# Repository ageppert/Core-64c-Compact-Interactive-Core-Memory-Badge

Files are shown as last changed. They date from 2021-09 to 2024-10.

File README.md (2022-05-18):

# Core-64c-Compact-Interactive-Core-Memory-Badge
Weave your own 64 bits of core memory over the top of LEDs to interact with directly using a magnetic wand.

Purchase: https://www.Core64.io

Follow this project at: https://hackaday.io/project/166155-core-64-interactive-core-memory-badge

You are in the hardware development repository. Production version firmware is at https://github.com/ageppert/Core64/

# Hardware Version History (latest on top)

HWV 0.3.0 Correct shift register schematic, add TC0_MON as ADC3, move 5V0 cap down, alternate LDO v-regs with 0.1uF caps, rotate SPI GPIO 180°, matrix current setting resistors 6.8 Ohm, I2C pull-ups 1.2K, add battery pack wire pads directly to board, silkscreen tweaks, move LED Matrix Driver components away from lanyard hole.

HWV 0.2.1 Rework HWV 0.2.0 to correct shift register schematics mistakes.

HWV 0.2.0 Change to 74HC595 shift registers for IO expansion. First version prototyped. Matrix current setting resistors 5.1 Ohm.

HWV 0.1.0 Compact Triple Stack - use 74HC138/238 3-to-8 decoders for IO expansion. Abandoned before prototyping.

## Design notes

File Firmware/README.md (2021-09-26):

# Firmware Source Code
Arduino project folder, sketches, libraries.

This firmware is for TESTING ONLY in development of Core64c.

Functional firmware is in https://github.com/ageppert/Core64/tree/master/Firmware

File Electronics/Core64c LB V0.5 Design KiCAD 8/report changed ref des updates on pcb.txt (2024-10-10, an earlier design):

Info: Processing symbol 'C1:Capacitor_SMD:C_0805_2012Metric'.
Info: Processing symbol 'X9:Connector_JST:JST_SH_SM04B-SRSS-TB_1x04-1MP_P1.00mm_Horizontal'.
Info: Processing symbol 'C2:Capacitor_SMD:C_0805_2012Metric'.
Info: Processing symbol 'X7:Connector_PinSocket_2.54mm:PinSocket_1x08_P2.54mm_Vertical'.
Info: Processing symbol 'C3:Capacitor_SMD:C_0805_2012Metric'.
Info: Processing symbol 'X6:Connector_PinSocket_2.54mm:PinSocket_1x11_P2.54mm_Vertical'.
Info: Processing symbol 'C4:Capacitor_SMD:C_0805_2012Metric'.
Info: Processing symbol 'X4:Connector_PinSocket_2.54mm:PinSocket_1x04_P2.54mm_Vertical'.
Info: Processing symbol 'C5:Capacitor_SMD:C_0805_2012Metric'.
Info: Processing symbol 'X2:Connector_PinSocket_2.54mm:PinSocket_1x04_P2.54mm_Vertical'.
Info: Processing symbol 'C6:Capacitor_SMD:C_0805_2012Metric'.
Info: Processing symbol 'U10:Package_SO:SOIC-14_3.9x8.7mm_P1.27mm'.
Info: Processing symbol 'C7:Capacitor_SMD:C_1206_3216Metric'.
Info: Processing symbol 'U9:digikey-footprints:SOIC-8_W3.9mm'.
Info: Processing symbol 'C8:Capacitor_SMD:C_1206_3216Metric'.
Info: Processing symbol 'U8:Package_TO_SOT_SMD:SOT-23-5'.
Info: Processing symbol 'C9:Capacitor_SMD:C_1206_3216Metric'.
Info: Processing symbol 'U7:Package_TO_SOT_SMD:SOT-23-5'.
Info: Processing symbol 'C10:Capacitor_SMD:C_0805_2012Metric'.
Info: Processing symbol 'U6:Package_TO_SOT_SMD:SOT-223-5'.
Info: Processing symbol 'C11:Capacitor_SMD:C_0805_2012Metric'.
Info: Processing symbol 'U5:digikey-footprints:SOIC-16_W3.90mm'.
Info: Processing symbol 'U4:digikey-footprints:SOIC-16_W3.90mm'.
Info: Processing symbol 'U3:digikey-footprints:SOIC-16_W3.90mm'.
Info: Processing symbol 'C12:Capacitor_SMD:C_0805_2012Metric'.
Info: Processing symbol 'U2:Package_SO:SOIC-8_3.9x4.9mm_P1.27mm'.
Info: Processing symbol 'C13:Capacitor_SMD:C_1206_3216Metric'.
Info: Processing symbol 'U1:PICO:Pico_W_SC0915'.
Info: Processing symbol 'C14:Capacitor_SMD:C_1206_3216Metric'.
Info: Processing symbol 'SW1:Switch_XKB_SK12D07VG4_SK12D07L4B:SK12D07VG4'.
Info: Processing symbol 'C15:Capacitor_SMD:C_1206_3216Metric'.
Info: Processing symbol 'R55:Resistor_SMD:R_0805_2012Metric'.
Info: Processing symbol 'C16:Capacitor_SMD:C_0805_2012Metric'.
Info: Processing symbol 'R54:Resistor_SMD:R_0805_2012Metric'.
Info: Processing symbol 'C17:Capacitor_SMD:C_0805_2012Metric'.
Info: Processing symbol 'R53:Resistor_SMD:R_0805_2012Metric'.
Info: Processing symbol 'C18:Capacitor_SMD:C_0805_2012Metric'.
Info: Processing symbol 'R52:Resistor_SMD:R_0805_2012Metric'.
Info: Processing symbol 'C19:Capacitor_SMD:C_0805_2012Metric'.
Info: Processing symbol 'R51:Resistor_SMD:R_0805_2012Metric'.
Info: Processing symbol 'D1:Package_TO_SOT_SMD:SOT-323_SC-70'.
Info: Processing symbol 'D2:Package_TO_SOT_SMD:SOT-323_SC-70'.
Info: Processing symbol 'D3:Package_TO_SOT_SMD:SOT-323_SC-70'.
Info: Processing symbol 'D4:Package_TO_SOT_SMD:SOT-323_SC-70'.
Info: Processing symbol 'D5:Package_TO_SOT_SMD:SOT-323_SC-70'.
Info: Processing symbol 'D6:Package_TO_SOT_SMD:SOT-323_SC-70'.
Info: Processing symbol 'D7:Package_TO_SOT_SMD:SOT-323_SC-70'.
Info: Processing symbol 'D8:Package_TO_SOT_SMD:SOT-323_SC-70'.
Info: Processing symbol 'D9:Package_TO_SOT_SMD:SOT-323_SC-70'.
Info: Processing symbol 'D10:Package_TO_SOT_SMD:SOT-323_SC-70'.
Info: Processing symbol 'D11:Package_TO_SOT_SMD:SOT-323_SC-70'.
Info: Processing symbol 'D12:Package_TO_SOT_SMD:SOT-323_SC-70'.
Info: Processing symbol 'H1:MountingHole:MountingHole_3.2mm_M3_Pad_Via'.
Info: Processing symbol 'H2:MountingHole:MountingHole_3.2mm_M3_Pad_Via'.
Info: Processing symbol 'J1:Connector_PinSocket_2.54mm:PinSocket_1x20_P2.54mm_Vertical'.
Info: Processing symbol 'J2:Connector_PinSocket_2.54mm:PinSocket_1x20_P2.54mm_Vertical'.
Info: Processing symbol 'R50:Resistor_SMD:R_0805_2012Metric'.
Info: Processing symbol 'R49:Resistor_SMD:R_0805_2012Metric'.
Info: Processing symbol 'J3:Connector_PinSocket_2.54mm:PinSocket_1x02_P2.54mm_Vertical'.
Info: Processing symbol 'J6:Connector_PinSocket_2.54mm:PinSocket_1x08_P2.54mm_Vertical'.
Info: Processing symbol 'J12:Connector_PinSocket_2.54mm:PinSocket_1x08_P2.54mm_Vertical'.
Info: Processing symbol 'R48:Resistor_SMD:R_0805_2012Metric'.
Info: Processing symbol 'JP1:Jumper:SolderJumper-2_P1.3mm_Bridged_RoundedPad1.0x1.5mm'.
Info: Processing symbol 'R47:Resistor_SMD:R_0805_2012Metric'.
Info: Processing symbol 'R46:Resistor_SMD:R_0805_2012Metric'.
Info: Processing symbol 'R45:Resistor_SMD:R_0805_2012Metric'.
Info: Processing symbol 'R44:Resistor_SMD:R_0805_2012Metric'.
Info: Processing symbol 'R42:Resistor_SMD:R_0805_2012Metric'.
Info: Processing symbol 'R38:Resistor_SMD:R_0805_2012Metric'.
Info: Processing symbol 'R37:Resistor_SMD:R_0805_2012Metric'.
Info: Processing symbol 'R36:Resistor_SMD:R_0805_2012Metric'.
Info: Processing symbol 'R35:Resistor_SMD:R_0805_2012Metric'.
Info: Processing symbol 'R34:Resistor_SMD:R_0805_2012Metric'.
Info: Processing symbol 'R31:Resistor_SMD:R_0805_2012Metric'.
Info: Processing symbol 'JP15:Jumper:SolderJumper-3_P1.3mm_Open_Pad1.0x1.5mm_NumberLabels'.
Info: Processing symbol 'JP16:Jumper:SolderJumper-3_P1.3mm_Open_Pad1.0x1.5mm_NumberLabels'.
Info: Processing symbol 'L1:Core_64_footprints:Core64c_Logo_7mm'.
Info: Processing symbol 'L2:Core_64_footprints:Core64c_Logo_7mm'.
Info: Processing symbol 'L3:Symbol:OSHW-Logo2_7.3x6mm_SilkScreen'.
Info: Processing symbol 'Q1:digikey-footprints:SOT-23-3'.
Info: Processing symbol 'Q2:digikey-footprints:SOT-23-3'.
Info: Processing symbol 'R30:Resistor_SMD:R_0805_2012Metric'.
Info: Processing symbol 'R28:Resistor_SMD:R_0805_2012Metric'.
Info: Processing symbol 'Q3:digikey-footprints:SOT-23-3'.
Info: Processing symbol 'Q4:digikey-footprints:SOT-23-3'.
Info: Processing symbol 'R27:Resistor_SMD:R_0805_2012Metric'.
Info: Processing symbol 'Q5:digikey-footprints:SOT-23-3'.
Info: Processing symbol 'Q6:digikey-footprints:SOT-23-3'.
Info: Processing symbol 'R26:Resistor_SMD:R_0805_2012Metric'.
Info: Processing symbol 'Q7:digikey-footprints:SOT-23-3'.
Info: Processing symbol 'Q8:digikey-footprints:SOT-23-3'.
Info: Processing symbol 'R25:Resistor_SMD:R_0805_2012Metric'.
Info: Processing symbol 'Q9:digikey-footprints:SOT-23-3'.
Info: Processing symbol 'Q10:digikey-footprints:SOT-23-3'.
Info: Processing symbol 'R24:Resistor_SMD:R_0805_2012Metric'.
Info: Processing symbol 'Q11:digikey-footprints:SOT-23-3'.
Info: Processing symbol 'Q12:digikey-footprints:SOT-23-3'.
Info: Processing symbol 'R23:Resistor_SMD:R_0805_2012Metric'.
Info: Processing symbol 'Q13:digikey-footprints:SOT-23-3'.
Info: Processing symbol 'Q14:digikey-footprints:SOT-23-3'.
Info: Processing symbol 'R22:Resistor_SMD:R_0805_2012Metric'.
Info: Processing symbol 'Q15:digikey-footprints:SOT-23-3'.
Info: Processing symbol 'Q16:digikey-footprints:SOT-23-3'.
Info: Processing symbol 'R21:Resistor_SMD:R_0805_2012Metric'.
Info: Processing symbol 'Q17:digikey-footprints:SOT-23-3'.
Info: Processing symbol 'Q18:digikey-footprints:SOT-23-3'.
Info: Processing symbol 'R20:Resistor_SMD:R_0805_2012Metric'.
Info: Processing symbol 'Q19:digikey-footprints:SOT-23-3'.
Info: Processing symbol 'Q20:digikey-footprints:SOT-23-3'.
Info: Processing symbol 'R19:Resistor_SMD:R_0805_2012Metric'.
Info: Processing symbol 'Q21:digikey-footprints:SOT-23-3'.
Info: Processing symbol 'R18:Resistor_SMD:R_0805_2012Metric'.
Info: Processing symbol 'Q22:digikey-footprints:SOT-23-3'.
Info: Processing symbol 'Q23:digikey-footprints:SOT-23-3'.
Info: Processing symbol 'R1:Resistor_SMD:R_0805_2012Metric'.
Info: Processing symbol 'R2:Resistor_SMD:R_0805_2012Metric'.
Info: Processing symbol 'R3:Resistor_SMD:R_0805_2012Metric'.
Info: Processing symbol 'R4:Resistor_SMD:R_0805_2012Metric'.
Info: Processing symbol 'R5:Resistor_SMD:R_0805_2012Metric'.
Info: Processing symbol 'R6:Resistor_SMD:R_0805_2012Metric'.
Info: Processing symbol 'R7:Resistor_SMD:R_0805_2012Metric'.
Info: Processing symbol 'R8:Resistor_SMD:R_0805_2012Metric'.
Info: Processing symbol 'R9:Resistor_SMD:R_0805_2012Metric'.
Info: Processing symbol 'R10:Resistor_SMD:R_0805_2012Metric'.
Info: Processing symbol 'R11:Resistor_SMD:R_0805_2012Metric'.
Info: Processing symbol 'R12:Resistor_SMD:R_0805_2012Metric'.
Info: Processing symbol 'R13:Resistor_SMD:R_0805_2012Metric'.
Info: Processing symbol 'R14:Resistor_SMD:R_0805_2012Metric'.
Info: Processing symbol 'R15:Resistor_SMD:R_0805_2012Metric'.
Info: Processing symbol 'R16:Resistor_SMD:R_0805_2012Metric'.
Info: Processing symbol 'R17:Resistor_SMD:R_0805_2012Metric'.
Reconnected Q21 pin 3 from GNDPWR to GMEM.
Reconnected Q20 pin 2 from GNDPWR to GMEM.
Reconnected Q18 pin 2 from GNDPWR to GMEM.
Reconnected Q16 pin 2 from GNDPWR to GMEM.
Changed R51 reference designator to R21.
Reconnected Q14 pin 2 from GNDPWR to GMEM.
Reconnected Q12 pin 2 from GNDPWR to GMEM.
Reconnected Q10 pin 2 from GNDPWR to GMEM.
Reconnected Q8 pin 2 from GNDPWR to GMEM.
Reconnected Q6 pin 2 from GNDPWR to GMEM.
Reconnected Q4 pin 2 from GNDPWR to GMEM.
Changed R28 reference designator to R27.
Reconnected Q2 pin 2 from GNDPWR to GMEM.
Changed R27 reference designator to R28.
Add net GMEM.
Changed R55 reference designator to R30.
Connected JP1 pin 1 to PICO_VBUS.
Changed R56 reference designator to R31.
Connected JP1 pin 2 to 5VUSB.
Changed R48 reference designator to R34.
Removed JP1 'exclude from BOM' fabrication attribute.
Changed R47 reference designator to R35.
Updated JP1 footprint filters to 'SolderJumper*Bridged*'.
Changed R40 reference designator to R36.
Add net Net-(R36-Pad1).
Reconnected R36 pin 1 from Net-(R40-Pad1) to Net-(R36-Pad1).
Updated JP1 sheetfile to 'Core64c LB.kicad_sch'.
Changed R41 reference designator to R37.
Reconnected R37 pin 2 from Net-(R40-Pad1) to Net-(R36-Pad1).
Updated JP1 sheetname to 'Root'.
Changed R42 reference designator to R38.
Updated JP1 fields.
Changed R45 reference designator to R42.
Updated JP1 symbol association from  to /08dada08-f2dd-4b06-bc5f-624b59e1f3ee.
Changed R39 reference designator to R44.
Changed JP1 value from SolderJumper-2_P1.3mm_Bridged_RoundedPad1.0x1.5mm to VBUS_VUSB_TIE.
Changed R44 reference designator to R45.
Add net Net-(U6-EN).
Reconnected R45 pin 2 from Net-(U5-EN) to Net-(U6-EN).
Changed REF** reference designator to JP1.
Changed R38 reference designator to R46.
Add net Net-(U8-Y).
Reconnected R46 pin 2 from Net-(U3-Y) to Net-(U8-Y).
Added JP1 (footprint 'Jumper:SolderJumper-2_P1.3mm_Bridged_RoundedPad1.0x1.5mm').
Changed R29 reference designator to R47.
Reconnected J12 pin 3 from 5VUSB to PICO_VBUS.
Changed R30 reference designator to R48.
Add net Net-(U9B-_).
Reconnected R48 pin 2 from Net-(U1B-_) to Net-(U9B-_).
Reconnected J2 pin 20 from 5VUSB to PICO_VBUS.
Changed R32 reference designator to R49.
Reconnected R49 pin 1 from Net-(U1B-_) to Net-(U9B-_).
Add net PICO_VBUS.
Changed R34 reference designator to R50.
Changed C4 reference designator to C19.
Changed R31 reference designator to R51.
Add net Net-(U9A--).
Reconnected R51 pin 2 from Net-(U1A--) to Net-(U9A--).
Changed C3 reference designator to C18.
Changed R33 reference designator to R52.
Reconnected R52 pin 1 from Net-(U1A--) to Net-(U9A--).
Changed C2 reference designator to C17.
Changed R35 reference designator to R53.
Changed C5 reference designator to C16.
Changed R36 reference designator to R54.
Changed C22 reference designator to C15.
Changed R37 reference designator to R55.
Changed C21 reference designator to C14.
Changed C20 reference designator to C13.
Changed U7 reference designator to U1.
Reconnected U1 pin 40 from 5VUSB to PICO_VBUS.
Add net unconnected-(U1-SWCLK-PadD1).
Reconnected U1 pin D1 from unconnected-(U7-SWCLK-PadD1) to unconnected-(U1-SWCLK-PadD1).
Add net unconnected-(U1-RUN-Pad30).
Reconnected U1 pin 30 from unconnected-(U7-RUN-Pad30) to unconnected-(U1-RUN-Pad30).
Add net unconnected-(U1-GND-PadD2).
Reconnected U1 pin D2 from unconnected-(U7-GND-PadD2) to unconnected-(U1-GND-PadD2).
Add net unconnected-(U1-RUN-Pad30)_0.
Reconnected U1 pin 30 from unconnected-(U7-RUN-Pad30)_0 to unconnected-(U1-RUN-Pad30)_0.
Add net unconnected-(U1-3V3_EN-Pad37).
Reconnected U1 pin 37 from unconnected-(U7-3V3_EN-Pad37) to unconnected-(U1-3V3_EN-Pad37).
Add net unconnected-(U1-GND-PadD2)_0.
Reconnected U1 pin D2 from unconnected-(U7-GND-PadD2)_0 to unconnected-(U1-GND-PadD2)_0.
Add net unconnected-(U1-SWDIO-PadD3).
Reconnected U1 pin D3 from unconnected-(U7-SWDIO-PadD3) to unconnected-(U1-SWDIO-PadD3).
Add net unconnected-(U1-GND-PadD2)_1.
Reconnected U1 pin D2 from unconnected-(U7-GND-PadD2)_1 to unconnected-(U1-GND-PadD2)_1.
Reconnected U1 pin 40 from 5VUSB to PICO_VBUS.
Add net unconnected-(U1-SWDIO-PadD3)_0.
Reconnected U1 pin D3 from unconnected-(U7-SWDIO-PadD3)_0 to unconnected-(U1-SWDIO-PadD3)_0.
Add net unconnected-(U1-SWDIO-PadD3)_1.
Reconnected U1 pin D3 from unconnected-(U7-SWDIO-PadD3)_1 to unconnected-(U1-SWDIO-PadD3)_1.
Add net unconnected-(U1-SWCLK-PadD1)_0.
Reconnected U1 pin D1 from unconnected-(U7-SWCLK-PadD1)_0 to unconnected-(U1-SWCLK-PadD1)_0.
Add net unconnected-(U1-SWCLK-PadD1)_1.
Reconnected U1 pin D1 from unconnected-(U7-SWCLK-PadD1)_1 to unconnected-(U1-SWCLK-PadD1)_1.
Add net unconnected-(U1-3V3_EN-Pad37)_0.
Reconnected U1 pin 37 from unconnected-(U7-3V3_EN-Pad37)_0 to unconnected-(U1-3V3_EN-Pad37)_0.
Changed C13 reference designator to C12.
Changed U4 reference designator to U2.
Reconnected C11 pin 1 from Net-(U6-BP) to Net-(U7-BP).
Changed U8 reference designator to U3.
Add net Net-(U3-QH').
Reconnected U3 pin 9 from Net-(U8-QH') to Net-(U3-QH').
Add net Net-(U7-BP).
Changed U9 reference designator to U4.
Reconnected U4 pin 14 from Net-(U8-QH') to Net-(U3-QH').
Add net Net-(U4-QH').
Reconnected U4 pin 9 from Net-(U10-SER) to Net-(U4-QH').
Changed C12 reference designator to C11.
Changed U10 reference designator to U5.
Add net Net-(U5-QE).
Reconnected U5 pin 4 from Net-(U10-QE) to Net-(U5-QE).
Add net Net-(U5-QH).
Reconnected U5 pin 7 from Net-(U10-QH) to Net-(U5-QH).
Add net unconnected-(U5-QH'-Pad9).
Reconnected U5 pin 9 from unconnected-(U10-QH'-Pad9) to unconnected-(U5-QH'-Pad9).
Reconnected U5 pin 14 from Net-(U10-SER) to Net-(U4-QH').
Add net Net-(U5-QF).
Reconnected U5 pin 5 from Net-(U10-QF) to Net-(U5-QF).
Add net Net-(U5-QG).
Reconnected U5 pin 6 from Net-(U10-QG) to Net-(U5-QG).
Changed C11 reference designator to C10.
Changed U5 reference designator to U6.
Add net unconnected-(U6-NC-Pad2).
Reconnected U6 pin 2 from unconnected-(U5-NC-Pad2) to unconnected-(U6-NC-Pad2).
Reconnected U6 pin 1 from Net-(U5-EN) to Net-(U6-EN).
Changed C19 reference designator to C9.
Changed U6 reference designator to U7.
Reconnected U7 pin 4 from Net-(U6-BP) to Net-(U7-BP).
Changed C18 reference designator to C8.
Changed U3 reference designator to U8.
Reconnected U8 pin 4 from Net-(U3-Y) to Net-(U8-Y).
Changed C17 reference designator to C7.
Changed U1 reference designator to U9.
Reconnected U9 pin 2 from Net-(U1A--) to Net-(U9A--).
Reconnected U9 pin 6 from Net-(U1B-_) to Net-(U9B-_).
Changed C10 reference designator to C6.
Changed U2 reference designator to U10.
Updated U10 symbol association from /cc8a2cc2-faaa-46fc-b29a-479b6a972e1d to /f689fd4c-a0ce-4408-baa7-6587441be90b.
Add net Net-(U10-Pad1).
Reconnected U10 pin 5 from Net-(U2-Pad1) to Net-(U10-Pad1).
Add net Net-(U10-Pad13).
Reconnected U10 pin 9 from Net-(U2-Pad13) to Net-(U10-Pad13).
Reconnected U10 pin 6 from Net-(U2-Pad1) to Net-(U10-Pad1).
Add net Net-(U10-Pad12).
Reconnected U10 pin 4 from Net-(U2-Pad12) to Net-(U10-Pad12).
Reconnected U10 pin 1 from Net-(U2-Pad1) to Net-(U10-Pad1).
Reconnected U10 pin 12 from Net-(U2-Pad12) to Net-(U10-Pad12).
Reconnected U10 pin 13 from Net-(U2-Pad13) to Net-(U10-Pad13).
Changed C8 reference designator to C5.
Changed X7 reference designator to X2.
Changed C16 reference designator to C4.
Changed X10 reference designator to X4.
Reconnected X4 pin 4 from Net-(U10-QH) to Net-(U5-QH).
Reconnected X4 pin 3 from Net-(U10-QG) to Net-(U5-QG).
Reconnected X4 pin 1 from Net-(U10-QE) to Net-(U5-QE).
Reconnected X4 pin 2 from Net-(U10-QF) to Net-(U5-QF).
Changed C15 reference designator to C3.
Changed C14 reference designator to C2.
Changed X4 reference designator to X7.
Changed C6 reference designator to C1.
Changed X8 reference designator to X9.
Removed unused net unconnected-(U7-SWDIO-PadD3)_1.
Removed unused net unconnected-(U7-SWDIO-PadD3)_0.
Reconnected via from GNDPWR to GMEM.
Reconnected via from GNDPWR to GMEM.
Reconnected via from GNDPWR to GMEM.
Reconnected via from GNDPWR to GMEM.
Reconnected via from GNDPWR to GMEM.
Reconnected via from GNDPWR to GMEM.
Reconnected via from GNDPWR to GMEM.
Reconnected via from GNDPWR to GMEM.
Reconnected via from GNDPWR to GMEM.
Reconnected via from GNDPWR to GMEM.
Reconnected via from GNDPWR to GMEM.
Reconnected via from GNDPWR to GMEM.
Reconnected via from GNDPWR to GMEM.
Reconnected via from Net-(U2-Pad1) to Net-(U10-Pad1).
Reconnected via from Net-(U2-Pad1) to Net-(U10-Pad1).
Reconnected via from Net-(U2-Pad1) to Net-(U10-Pad1).
Reconnected via from Net-(U1A--) to Net-(U9A--).
Reconnected via from Net-(U1A--) to Net-(U9A--).
Reconnected via from Net-(U8-QH') to Net-(U3-QH').
Reconnected via from Net-(U8-QH') to Net-(U3-QH').
Reconnected via from Net-(U10-SER) to Net-(U4-QH').
Reconnected via from Net-(U10-SER) to Net-(U4-QH').
Removed unused net unconnected-(U7-SWDIO-PadD3).
Removed unused net unconnected-(U7-SWCLK-PadD1)_1.
Removed unused net unconnected-(U7-SWCLK-PadD1)_0.
Removed unused net unconnected-(U7-SWCLK-PadD1).
Removed unused net unconnected-(U7-RUN-Pad30)_0.
Removed unused net unconnected-(U7-RUN-Pad30).
Removed unused net unconnected-(U7-GND-PadD2)_1.
Removed unused net unconnected-(U7-GND-PadD2)_0.
Removed unused net unconnected-(U7-GND-PadD2).
Removed unused net unconnected-(U7-3V3_EN-Pad37)_0.
Removed unused net GNDPWR.
Removed unused net Net-(R40-Pad1).
Removed unused net Net-(U10-QE).
Removed unused net Net-(U10-QF).
Removed unused net Net-(U10-QG).
Removed unused net Net-(U10-QH).
Removed unused net Net-(U10-SER).
Removed unused net Net-(U1A--).
Removed unused net Net-(U1B-_).
Removed unused net Net-(U2-Pad1).
Removed unused net Net-(U2-Pad12).
Removed unused net Net-(U2-Pad13).
Removed unused net Net-(U3-Y).
Removed unused net Net-(U5-EN).
Removed unused net Net-(U6-BP).
Removed unused net Net-(U8-QH').
Removed unused net unconnected-(U10-QH'-Pad9).
Removed unused net unconnected-(U5-NC-Pad2).
Removed unused net unconnected-(U7-3V3_EN-Pad37).
Warning: No net found for component X9 pad MP (no pin MP in symbol).
Warning: No net found for component X9 pad MP (no pin MP in symbol).
Error: U1 pad TP4 not found in PICO:Pico_W_SC0915.
Error: U1 pad TP5 not found in PICO:Pico_W_SC0915.
Error: U1 pad TP1 not found in PICO:Pico_W_SC0915.
Error: U1 pad D not found in PICO:Pico_W_SC0915.
Error: U1 pad TP3 not found in PICO:Pico_W_SC0915.
Error: U1 pad B not found in PICO:Pico_W_SC0915.
Error: U1 pad A not found in PICO:Pico_W_SC0915.
Error: U1 pad TP6 not found in PICO:Pico_W_SC0915.
Error: U1 pad TP2 not found in PICO:Pico_W_SC0915.
Error: U1 pad C not found in PICO:Pico_W_SC0915.

Info: Total warnings: 2, errors: 10.

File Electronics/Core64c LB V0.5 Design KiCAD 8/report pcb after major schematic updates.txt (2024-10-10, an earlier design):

Info: Processing symbol 'C1:Capacitor_SMD:C_0805_2012Metric'.
Info: Processing symbol 'X72:Connector_PinSocket_2.54mm:PinSocket_1x07_P2.54mm_Vertical'.
Info: Processing symbol 'X71:Connector_PinSocket_2.54mm:PinSocket_1x07_P2.54mm_Vertical'.
Info: Processing symbol 'C2:Capacitor_SMD:C_0805_2012Metric'.
Info: Processing symbol 'X9:Connector_JST:JST_SH_SM04B-SRSS-TB_1x04-1MP_P1.00mm_Horizontal'.
Info: Processing symbol 'C3:Capacitor_SMD:C_0805_2012Metric'.
Info: Processing symbol 'X5:Connector_PinSocket_2.54mm:PinSocket_1x11_P2.54mm_Vertical'.
Info: Processing symbol 'C4:Capacitor_SMD:C_0805_2012Metric'.
Info: Processing symbol 'X4:Connector_PinSocket_2.54mm:PinSocket_1x04_P2.54mm_Vertical'.
Info: Processing symbol 'C5:Capacitor_SMD:C_0805_2012Metric'.
Info: Processing symbol 'X3:Connector_PinSocket_2.54mm:PinSocket_1x10_P2.54mm_Vertical'.
Info: Processing symbol 'C6:Capacitor_SMD:C_0805_2012Metric'.
Info: Processing symbol 'U10:Package_SO:SOIC-14_3.9x8.7mm_P1.27mm'.
Info: Processing symbol 'C7:Capacitor_SMD:C_1206_3216Metric'.
Info: Processing symbol 'U9:digikey-footprints:SOIC-8_W3.9mm'.
Info: Processing symbol 'C8:Capacitor_SMD:C_1206_3216Metric'.
Info: Processing symbol 'U8:Package_TO_SOT_SMD:SOT-23-5'.
Info: Processing symbol 'C9:Capacitor_SMD:C_1206_3216Metric'.
Info: Processing symbol 'U7:Package_TO_SOT_SMD:SOT-23-5'.
Info: Processing symbol 'C10:Capacitor_SMD:C_0805_2012Metric'.
Info: Processing symbol 'U6:Package_TO_SOT_SMD:SOT-223-5'.
Info: Processing symbol 'C11:Capacitor_SMD:C_0805_2012Metric'.
Info: Processing symbol 'U5:digikey-footprints:SOIC-16_W3.90mm'.
Info: Processing symbol 'C12:Capacitor_SMD:C_0805_2012Metric'.
Info: Processing symbol 'U4:digikey-footprints:SOIC-16_W3.90mm'.
Info: Processing symbol 'C13:Capacitor_SMD:C_1206_3216Metric'.
Info: Processing symbol 'U3:digikey-footprints:SOIC-16_W3.90mm'.
Info: Processing symbol 'C14:Capacitor_SMD:C_1206_3216Metric'.
Info: Processing symbol 'U2:Package_SO:SOIC-8_3.9x4.9mm_P1.27mm'.
Info: Processing symbol 'C15:Capacitor_SMD:C_1206_3216Metric'.
Info: Processing symbol 'U1:PICO:Pico_W_SC0915'.
Info: Processing symbol 'C16:Capacitor_SMD:C_0805_2012Metric'.
Info: Processing symbol 'TP23:Core_64_footprints:TestPoint_THTPad_D1.5mm_Drill1.0mm'.
Info: Processing symbol 'C17:Capacitor_SMD:C_0805_2012Metric'.
Info: Processing symbol 'TP22:Core_64_footprints:TestPoint_THTPad_D1.5mm_Drill1.0mm'.
Info: Processing symbol 'C18:Capacitor_SMD:C_0805_2012Metric'.
Info: Processing symbol 'TP21:Core_64_footprints:TestPoint_THTPad_D1.5mm_Drill1.0mm'.
Info: Processing symbol 'C19:Capacitor_SMD:C_0805_2012Metric'.
Info: Processing symbol 'TP20:Core_64_footprints:TestPoint_THTPad_D1.5mm_Drill1.0mm'.
Info: Processing symbol 'D1:Package_TO_SOT_SMD:SOT-323_SC-70'.
Info: Processing symbol 'TP19:Core_64_footprints:TestPoint_THTPad_D1.5mm_Drill1.0mm'.
Info: Processing symbol 'SW1:Switch_XKB_SK12D07VG4_SK12D07L4B:SK12D07VG4'.
Info: Processing symbol 'R55:Resistor_SMD:R_0805_2012Metric'.
Info: Processing symbol 'R54:Resistor_SMD:R_0805_2012Metric'.
Info: Processing symbol 'D2:Package_TO_SOT_SMD:SOT-323_SC-70'.
Info: Processing symbol 'R53:Resistor_SMD:R_0805_2012Metric'.
Info: Processing symbol 'R52:Resistor_SMD:R_0805_2012Metric'.
Info: Processing symbol 'D3:Package_TO_SOT_SMD:SOT-323_SC-70'.
Info: Processing symbol 'R51:Resistor_SMD:R_0805_2012Metric'.
Info: Processing symbol 'R50:Resistor_SMD:R_0805_2012Metric'.
Info: Processing symbol 'R49:Resistor_SMD:R_0805_2012Metric'.
Info: Processing symbol 'R48:Resistor_SMD:R_0805_2012Metric'.
Info: Processing symbol 'D4:Package_TO_SOT_SMD:SOT-323_SC-70'.
Info: Processing symbol 'R47:Resistor_SMD:R_0805_2012Metric'.
Info: Processing symbol 'R46:Resistor_SMD:R_0805_2012Metric'.
Info: Processing symbol 'D5:Package_TO_SOT_SMD:SOT-323_SC-70'.
Info: Processing symbol 'R45:Resistor_SMD:R_0805_2012Metric'.
Info: Processing symbol 'R44:Resistor_SMD:R_0805_2012Metric'.
Info: Processing symbol 'R43:Resistor_SMD:R_0805_2012Metric'.
Info: Processing symbol 'R42:Resistor_SMD:R_0805_2012Metric'.
Info: Processing symbol 'D6:Package_TO_SOT_SMD:SOT-323_SC-70'.
Info: Processing symbol 'R41:Resistor_SMD:R_0805_2012Metric'.
Info: Processing symbol 'R38:Resistor_SMD:R_0805_2012Metric'.
Info: Processing symbol 'D7:Package_TO_SOT_SMD:SOT-323_SC-70'.
Info: Processing symbol 'R37:Resistor_SMD:R_0805_2012Metric'.
Info: Processing symbol 'R36:Resistor_SMD:R_0805_2012Metric'.
Info: Processing symbol 'R35:Resistor_SMD:R_0805_2012Metric'.
Info: Processing symbol 'R34:Resistor_SMD:R_0805_2012Metric'.
Info: Processing symbol 'D8:Package_TO_SOT_SMD:SOT-323_SC-70'.
Info: Processing symbol 'R33:Resistor_SMD:R_0805_2012Metric'.
Info: Processing symbol 'R32:Resistor_SMD:R_0805_2012Metric'.
Info: Processing symbol 'D9:Package_TO_SOT_SMD:SOT-323_SC-70'.
Info: Processing symbol 'R31:Resistor_SMD:R_0805_2012Metric'.
Info: Processing symbol 'R30:Resistor_SMD:R_0805_2012Metric'.
Info: Processing symbol 'R29:Resistor_SMD:R_0805_2012Metric'.
Info: Processing symbol 'R28:Resistor_SMD:R_0805_2012Metric'.
Info: Processing symbol 'D10:Package_TO_SOT_SMD:SOT-323_SC-70'.
Info: Processing symbol 'R27:Resistor_SMD:R_0805_2012Metric'.
Info: Processing symbol 'R26:Resistor_SMD:R_0805_2012Metric'.
Info: Processing symbol 'D11:Package_TO_SOT_SMD:SOT-323_SC-70'.
Info: Processing symbol 'R25:Resistor_SMD:R_0805_2012Metric'.
Info: Processing symbol 'R24:Resistor_SMD:R_0805_2012Metric'.
Info: Processing symbol 'R23:Resistor_SMD:R_0805_2012Metric'.
Info: Processing symbol 'R22:Resistor_SMD:R_0805_2012Metric'.
Info: Processing symbol 'D12:Package_TO_SOT_SMD:SOT-323_SC-70'.
Info: Processing symbol 'R21:Resistor_SMD:R_0805_2012Metric'.
Info: Processing symbol 'R20:Resistor_SMD:R_0805_2012Metric'.
Info: Processing symbol 'H1:MountingHole:MountingHole_3.2mm_M3_Pad_Via'.
Info: Processing symbol 'R19:Resistor_SMD:R_0805_2012Metric'.
Info: Processing symbol 'R18:Resistor_SMD:R_0805_2012Metric'.
Info: Processing symbol 'R17:Resistor_SMD:R_0805_2012Metric'.
Info: Processing symbol 'R16:Resistor_SMD:R_0805_2012Metric'.
Info: Processing symbol 'R15:Resistor_SMD:R_0805_2012Metric'.
Info: Processing symbol 'R14:Resistor_SMD:R_0805_2012Metric'.
Info: Processing symbol 'R13:Resistor_SMD:R_0805_2012Metric'.
Info: Processing symbol 'R12:Resistor_SMD:R_0805_2012Metric'.
Info: Processing symbol 'R11:Resistor_SMD:R_0805_2012Metric'.
Info: Processing symbol 'H2:MountingHole:MountingHole_3.2mm_M3_Pad_Via'.
Info: Processing symbol 'R10:Resistor_SMD:R_0805_2012Metric'.
Info: Processing symbol 'R9:Resistor_SMD:R_0805_2012Metric'.
Info: Processing symbol 'R8:Resistor_SMD:R_0805_2012Metric'.
Info: Processing symbol 'R7:Resistor_SMD:R_0805_2012Metric'.
Info: Processing symbol 'R6:Resistor_SMD:R_0805_2012Metric'.
Info: Processing symbol 'R5:Resistor_SMD:R_0805_2012Metric'.
Info: Processing symbol 'R4:Resistor_SMD:R_0805_2012Metric'.
Info: Processing symbol 'R3:Resistor_SMD:R_0805_2012Metric'.
Info: Processing symbol 'R2:Resistor_SMD:R_0805_2012Metric'.
Info: Processing symbol 'J1:Connector_PinSocket_2.54mm:PinSocket_1x20_P2.54mm_Vertical'.
Info: Processing symbol 'R1:Resistor_SMD:R_0805_2012Metric'.
Info: Processing symbol 'Q23:digikey-footprints:SOT-23-3'.
Info: Processing symbol 'Q22:digikey-footprints:SOT-23-3'.
Info: Processing symbol 'Q21:digikey-footprints:SOT-23-3'.
Info: Processing symbol 'Q20:digikey-footprints:SOT-23-3'.
Info: Processing symbol 'Q19:digikey-footprints:SOT-23-3'.
Info: Processing symbol 'Q18:digikey-footprints:SOT-23-3'.
Info: Processing symbol 'Q17:digikey-footprints:SOT-23-3'.
Info: Processing symbol 'Q16:digikey-footprints:SOT-23-3'.
Info: Processing symbol 'Q15:digikey-footprints:SOT-23-3'.
Info: Processing symbol 'Q14:digikey-footprints:SOT-23-3'.
Info: Processing symbol 'Q13:digikey-footprints:SOT-23-3'.
Info: Processing symbol 'Q12:digikey-footprints:SOT-23-3'.
Info: Processing symbol 'Q11:digikey-footprints:SOT-23-3'.
Info: Processing symbol 'Q10:digikey-footprints:SOT-23-3'.
Info: Processing symbol 'Q9:digikey-footprints:SOT-23-3'.
Info: Processing symbol 'Q8:digikey-footprints:SOT-23-3'.
Info: Processing symbol 'Q7:digikey-footprints:SOT-23-3'.
Info: Processing symbol 'Q6:digikey-footprints:SOT-23-3'.
Info: Processing symbol 'Q5:digikey-footprints:SOT-23-3'.
Info: Processing symbol 'Q4:digikey-footprints:SOT-23-3'.
Info: Processing symbol 'Q3:digikey-footprints:SOT-23-3'.
Info: Processing symbol 'Q2:digikey-footprints:SOT-23-3'.
Info: Processing symbol 'Q1:digikey-footprints:SOT-23-3'.
Info: Processing symbol 'L3:Symbol:OSHW-Logo2_9.8x8mm_SilkScreen'.
Info: Processing symbol 'L2:Core_64_footprints:Core64c_Logo_7mm'.
Info: Processing symbol 'L1:Core_64_footprints:Core64c_Logo_7mm'.
Info: Processing symbol 'JP17:Jumper:SolderJumper-2_P1.3mm_Bridged_RoundedPad1.0x1.5mm'.
Info: Processing symbol 'JP16:Jumper:SolderJumper-2_P1.3mm_Bridged_RoundedPad1.0x1.5mm'.
Info: Processing symbol 'JP15:Jumper:SolderJumper-2_P1.3mm_Bridged_RoundedPad1.0x1.5mm'.
Info: Processing symbol 'JP14:Jumper:SolderJumper-2_P1.3mm_Bridged_RoundedPad1.0x1.5mm'.
Info: Processing symbol 'JP11:Jumper:SolderJumper-2_P1.3mm_Bridged_RoundedPad1.0x1.5mm'.
Info: Processing symbol 'JP10:Jumper:SolderJumper-2_P1.3mm_Bridged_RoundedPad1.0x1.5mm'.
Info: Processing symbol 'J2:Connector_PinSocket_2.54mm:PinSocket_1x20_P2.54mm_Vertical'.
Info: Processing symbol 'JP8:Jumper:SolderJumper-2_P1.3mm_Bridged_RoundedPad1.0x1.5mm'.
Info: Processing symbol 'JP3:Jumper:SolderJumper-2_P1.3mm_Bridged_RoundedPad1.0x1.5mm'.
Info: Processing symbol 'J3:Connector_PinSocket_2.54mm:PinSocket_1x02_P2.54mm_Vertical'.
Add net +LABB.
Reconnect J2 pin 19 from +BATT to +LABB.
Reconnect J2 pin 14 from XB7 to /XB7.
Reconnect J2 pin 9 from XB2 to /XB2.
Add net /GPIO4_CP4_CS2.
Reconnect J2 pin 18 from CP4_EN to /GPIO4_CP4_CS2.
Reconnect J2 pin 7 from XB0 to /XB0.
Reconnect J2 pin 8 from XB1 to /XB1.
Reconnect J2 pin 10 from XB3 to /XB3.
Reconnect J2 pin 11 from XB4 to /XB4.
Reconnect J2 pin 2 from -BATT to -LABB.
Add net /XT0,4.
Reconnect J2 pin 6 from XT0,4 to /XT0,4.
Add net /XT2,6.
Reconnect J2 pin 4 from XT2,6 to /XT2,6.
Add net /GPIO1_CP1_SAO1.
Reconnect J2 pin 15 from CP1_EN to /GPIO1_CP1_SAO1.
Reconnect J2 pin 13 from XB6 to /XB6.
Add net /XT3,7.
Reconnect J2 pin 3 from XT3,7 to /XT3,7.
Add net /GPIO2_CP2_SAO2.
Reconnect J2 pin 16 from CP2_EN to /GPIO2_CP2_SAO2.
Add net /GPIO3_CP3_DC.
Reconnect J2 pin 17 from CP3_EN to /GPIO3_CP3_DC.
Reconnect J2 pin 12 from XB5 to /XB5.
Change J3 value from ALT. BATT. to Conn_1x02.
Reconnect J3 pin 1 from +BATT to +LABB.
Reconnect J3 pin 2 from -BATT to -LABB.
Reconnect J2 pin 5 from XT1,5 to /XT1,5.
Add JP3 (footprint 'Jumper:SolderJumper-2_P1.3mm_Bridged_RoundedPad1.0x1.5mm').
Add net /XT1,5.
Add JP8 (footprint 'Jumper:SolderJumper-2_P1.3mm_Bridged_RoundedPad1.0x1.5mm').
Reconnect J1 pin 2 from unconnected-(J1-Pin_2-Pad2) to /USER1.
Add JP10 (footprint 'Jumper:SolderJumper-2_P1.3mm_Bridged_RoundedPad1.0x1.5mm').
Add net /USER1.
Add JP11 (footprint 'Jumper:SolderJumper-2_P1.3mm_Bridged_RoundedPad1.0x1.5mm').
Reconnect J1 pin 4 from YL1 to /YL1.
Change JP14 value from VBUS_VUSB_TIE to VBUS_5VUSB_TIE.
Reconnect JP14 pin 1 from PICO_VBUS to 5VUSB.
Reconnect J1 pin 5 from YL2 to /YL2.
Reconnect J1 pin 9 from SENSE1 to /CM_SENSE_1_IN.
Add net /CM_SENSE_1_IN.
Reconnect J1 pin 10 from SENSE2 to /CM_SENSE_2_IN.
Add net /CM_SENSE_2_IN.
Reconnect J1 pin 17 from CP6_EN to /GPIO6_CP6_HS2.
Add net /GPIO6_CP6_HS2.
Reconnect J1 pin 8 from YL5 to /YL5,7.
Add net /YL5,7.
Reconnect J1 pin 15 from CP8_EN to /GPIO8_CP8_HS4.
Add net /GPIO8_CP8_HS4.
Reconnect J1 pin 16 from CP7_EN to /GPIO7_CP7_HS3.
Add net /GPIO7_CP7_HS3.
Reconnect J1 pin 11 from I2C_CLOCK to /I2C_3V3_SCL.
Add net /I2C_3V3_SCL.
Reconnect J1 pin 19 from unconnected-(J1-Pin_19-Pad19) to /USER2.
Add net /USER2.
Reconnect J1 pin 14 from -BATT to -LABB.
Reconnect J1 pin 7 from YL4 to /YL4,6.
Add net /YL4,6.
Reconnect J1 pin 3 from YL0 to /YL0.
Reconnect J1 pin 6 from YL3 to /YL3.
Reconnect J1 pin 1 from LED_MATRIX_5V0_SIG to /LED_ARY_5V0_SIG.
Add net /LED_ARY_5V0_SIG.
Reconnect J1 pin 18 from CP5_EN to /GPIO5_CP5_HS1.
Add net /GPIO5_CP5_HS1.
Reconnect J1 pin 12 from I2C_DATA to /I2C_3V3_SDA.
Reconnect Q21 pin 2 from -BATT to -LABB.
Add net Net-(JP3-A).
Reconnect Q21 pin 3 from GMEM to Net-(JP3-A).
Add net /I2C_3V3_SDA.
Reconnect J1 pin 20 from unconnected-(J1-Pin_20-Pad20) to /USER3.
Add net /USER3.
Add net /CM_Q1P.
Reconnect R1 pin 2 from Q1P to /CM_Q1P.
Reconnect H2 pin 1 from -BATT to -LABB.
Add net /CM_Q1N.
Reconnect R2 pin 2 from Q1N to /CM_Q1N.
Reconnect H2 pin 1 from -BATT to -LABB.
Add net /CM_Q2P.
Reconnect R3 pin 2 from Q2P to /CM_Q2P.
Reconnect H2 pin 1 from -BATT to -LABB.
Add net /CM_Q2N.
Reconnect R4 pin 2 from Q2N to /CM_Q2N.
Reconnect H2 pin 1 from -BATT to -LABB.
Add net /CM_Q3P.
Reconnect R5 pin 2 from Q3P to /CM_Q3P.
Reconnect H2 pin 1 from -BATT to -LABB.
Add net /CM_Q3N.
Reconnect R6 pin 2 from Q3N to /CM_Q3N.
Reconnect H2 pin 1 from -BATT to -LABB.
Add net /CM_Q4P.
Reconnect R7 pin 2 from Q4P to /CM_Q4P.
Reconnect H2 pin 1 from -BATT to -LABB.
Add net /CM_Q4N.
Reconnect R8 pin 2 from Q4N to /CM_Q4N.
Reconnect H2 pin 1 from -BATT to -LABB.
Add net /CM_Q5P.
Reconnect R9 pin 2 from Q5P to /CM_Q5P.
Reconnect H2 pin 1 from -BATT to -LABB.
Add net /CM_Q5N.
Reconnect R10 pin 2 from Q5N to /CM_Q5N.
Reconnect H1 pin 1 from -BATT to -LABB.
Add net /CM_Q6P.
Reconnect R11 pin 2 from Q6P to /CM_Q6P.
Reconnect H1 pin 1 from -BATT to -LABB.
Add net /CM_Q6N.
Reconnect R12 pin 2 from Q6N to /CM_Q6N.
Reconnect H1 pin 1 from -BATT to -LABB.
Add net /CM_Q7P.
Reconnect R13 pin 2 from Q7P to /CM_Q7P.
Reconnect H1 pin 1 from -BATT to -LABB.
Add net /CM_Q7N.
Reconnect R14 pin 2 from Q7N to /CM_Q7N.
Reconnect H1 pin 1 from -BATT to -LABB.
Add net /CM_Q8P.
Reconnect R15 pin 2 from Q8P to /CM_Q8P.
Reconnect H1 pin 1 from -BATT to -LABB.
Add net /CM_Q8N.
Reconnect R16 pin 2 from Q8N to /CM_Q8N.
Reconnect H1 pin 1 from -BATT to -LABB.
Add net /CM_Q9P.
Reconnect R17 pin 2 from Q9P to /CM_Q9P.
Reconnect H1 pin 1 from -BATT to -LABB.
Add net /CM_Q9N.
Reconnect R18 pin 2 from Q9N to /CM_Q9N.
Reconnect H1 pin 1 from -BATT to -LABB.
Add net /CM_Q10P.
Reconnect R19 pin 2 from Q10P to /CM_Q10P.
Reconnect D12 pin 1 from YL3 to /YL3.
Add net /CM_Q10N.
Reconnect R20 pin 2 from Q10N to /CM_Q10N.
Reconnect D12 pin 2 from YL2 to /YL2.
Reconnect R21 pin 2 from XT0,4 to /XT0,4.
Reconnect D11 pin 2 from YL3 to /YL3.
Reconnect R22 pin 1 from XT1,5 to /XT1,5.
Add net /YL3.
Reconnect R23 pin 1 from XT2,6 to /XT2,6.
Reconnect D11 pin 1 from YL2 to /YL2.
Reconnect R24 pin 1 from XT3,7 to /XT3,7.
Add net /YL2.
Reconnect R25 pin 1 from YL4 to /YL4,6.
Reconnect D10 pin 2 from YL0 to /YL0.
Reconnect R26 pin 1 from YL5 to /YL5,7.
Reconnect D10 pin 1 from YL1 to /YL1.
Reconnect R27 pin 1 from -BATT to -LABB.
Reconnect D9 pin 2 from YL1 to /YL1.
Add net /CM_EN.
Reconnect R28 pin 1 from Net-(Q21-G) to /CM_EN.
Reconnect R28 pin 2 from CORE_ARRAY_ENABLE to Net-(Q21-G).
Add net /YL1.
Add R29 (footprint 'Resistor_SMD:R_0805_2012Metric').
Reconnect D9 pin 1 from YL0 to /YL0.
Add net /I2C_CLOCK.
Reconnect R30 pin 2 from I2C_CLOCK to /I2C_CLOCK.
Add net /YL0.
Add net /I2C_DATA.
Reconnect R31 pin 2 from I2C_DATA to /I2C_DATA.
Reconnect D8 pin 2 from XB7 to /XB7.
Add R32 (footprint 'Resistor_SMD:R_0805_2012Metric').
Reconnect D8 pin 1 from XB6 to /XB6.
Add R33 (footprint 'Resistor_SMD:R_0805_2012Metric').
Reconnect D7 pin 1 from XB7 to /XB7.
Add net /SPI_CS1.
Reconnect R34 pin 2 from SPI_CS1 to /SPI_CS1.
Add net /XB7.
Reconnect R35 pin 2 from CP4_EN to /GPIO8_CP8_HS4.
Reconnect D7 pin 2 from XB6 to /XB6.
Add R36 (footprint 'Resistor_SMD:R_0805_2012Metric').
Add net /XB6.
Add R37 (footprint 'Resistor_SMD:R_0805_2012Metric').
Reconnect D6 pin 2 from XB5 to /XB5.
Reconnect R38 pin 2 from -BATT to -LABB.
Add net Net-(JP8-A).
Reconnect R38 pin 1 from BAT_MON to Net-(JP8-A).
Reconnect D6 pin 1 from XB4 to /XB4.
Add R41 (footprint 'Resistor_SMD:R_0805_2012Metric').
Reconnect D5 pin 1 from XB5 to /XB5.
Change R42 value from 10k to 1K2.
Add net /ADC1.
Reconnect R42 pin 1 from 3V3_MON to /ADC1.
Add net /ADC1_BUFF.
Reconnect R42 pin 2 from 3V3 to /ADC1_BUFF.
Add net /XB5.
Add R43 (footprint 'Resistor_SMD:R_0805_2012Metric').
Reconnect D5 pin 2 from XB4 to /XB4.
Reconnect R44 pin 2 from -BATT to -LABB.
Add net /XB4.
Reconnect D4 pin 2 from XB3 to /XB3.
Reconnect R46 pin 1 from LED_MATRIX_5V0_SIG to /LED_ARY_5V0_SIG.
Reconnect D4 pin 1 from XB2 to /XB2.
Reconnect R47 pin 1 from SENSE1 to /CM_SENSE_1_IN.
Reconnect R47 pin 2 from SENSE2 to /CM_SENSE_2_IN.
Reconnect D3 pin 2 from XB2 to /XB2.
Add net /XB2.
Reconnect R49 pin 2 from SENSE2 to /CM_SENSE_2_IN.
Reconnect D3 pin 1 from XB3 to /XB3.
Reconnect R50 pin 1 from SENSE2 to /CM_SENSE_2_IN.
Reconnect R50 pin 2 from -BATT to -LABB.
Add net /XB3.
Reconnect D2 pin 2 from XB1 to /XB1.
Reconnect R52 pin 2 from SENSE1 to /CM_SENSE_1_IN.
Reconnect D2 pin 1 from XB0 to /XB0.
Reconnect R53 pin 2 from -BATT to -LABB.
Reconnect R53 pin 1 from SENSE1 to /CM_SENSE_1_IN.
Reconnect D1 pin 1 from XB1 to /XB1.
Add net /XB1.
Reconnect D1 pin 2 from XB0 to /XB0.
Reconnect SW1 pin 1 from +BATT to +LABB.
Add net /XB0.
Add TP19 (footprint 'Core_64_footprints:TestPoint_THTPad_D1.5mm_Drill1.0mm').
Reconnect C19 pin 2 from -BATT to -LABB.
Reconnect TP20 pin 1 from SENSE1 to /CM_SENSE_1_IN.
Reconnect C18 pin 2 from -BATT to -LABB.
Reconnect TP21 pin 1 from SENSE2 to /CM_SENSE_2_IN.
Reconnect C17 pin 2 from -BATT to -LABB.
Reconnect C16 pin 2 from -BATT to -LABB.
Reconnect C15 pin 2 from -BATT to -LABB.
Add net /LED_ARY_3V3_SIG.
Reconnect U1 pin 29 from LED_MATRIX_3V3_SIG to /LED_ARY_3V3_SIG.
Reconnect U1 pin 40 from PICO_VBUS to 5VUSB.
Reconnect U1 pin 33 from -BATT to -LABB.
Add net /SPI_CD.
Reconnect U1 pin 19 from SPI_CD to /SPI_CD.
Reconnect U1 pin 5 from CP3_EN to /GPIO3_CP3_DC.
Reconnect U1 pin 9 from CP6_EN to /GPIO6_CP6_HS2.
Reconnect U1 pin 33 from -BATT to -LABB.
Reconnect U1 pin 6 from CP4_EN to /GPIO4_CP4_CS2.
Reconnect U1 pin 22 from SPI_CS1 to /SPI_CS1.
Reconnect U1 pin 6 from CP4_EN to /GPIO4_CP4_CS2.
Reconnect U1 pin 18 from -BATT to -LABB.
Add net /SPI_CLK.
Reconnect U1 pin 24 from SPI_CLK to /SPI_CLK.
Add net /SPI_SDI.
Reconnect U1 pin 21 from SPI_SDI to /SPI_SDI.
Reconnect U1 pin 11 from CP8_EN to /GPIO8_CP8_HS4.
Reconnect U1 pin 17 from SR_CLK to /CM_SR_CLK.
Reconnect U1 pin 12 from SR_LAT to /CM_SR_LAT.
Reconnect U1 pin 4 from CP2_EN to /GPIO2_CP2_SAO2.
Reconnect U1 pin 19 from SPI_CD to /SPI_CD.
Reconnect U1 pin 29 from LED_MATRIX_3V3_SIG to /LED_ARY_3V3_SIG.
Reconnect U1 pin 28 from -BATT to -LABB.
Reconnect U1 pin 3 from -BATT to -LABB.
Add net /ADC2.
Reconnect U1 pin 34 from SPARE_ADC2 to /ADC2.
Add net /SPI_RESET.
Reconnect U1 pin 20 from SPI_RESET to /SPI_RESET.
Reconnect U1 pin 13 from -BATT to -LABB.
Reconnect U1 pin 23 from -BATT to -LABB.
Reconnect U1 pin 21 from SPI_SDI to /SPI_SDI.
Add net /SPI_SDO.
Reconnect U1 pin 25 from SPI_SDO to /SPI_SDO.
Reconnect U1 pin 38 from -BATT to -LABB.
Reconnect U1 pin 34 from SPARE_ADC2 to /ADC2.
Reconnect U1 pin 14 from I2C_DATA to /I2C_DATA.
Reconnect U1 pin 10 from CP7_EN to /GPIO7_CP7_HS3.
Reconnect U1 pin 20 from SPI_RESET to /SPI_RESET.
Reconnect U1 pin 22 from SPI_CS1 to /SPI_CS1.
Reconnect U1 pin 2 from CP1_EN to /GPIO1_CP1_SAO1.
Reconnect U1 pin 24 from SPI_CLK to /SPI_CLK.
Reconnect U1 pin 32 from 3V3_MON to /ADC1.
Reconnect U1 pin 2 from CP1_EN to /GPIO1_CP1_SAO1.
Reconnect U1 pin 26 from CORE_ARRAY_ENABLE to /CM_EN.
Reconnect U1 pin 15 from I2C_CLOCK to /I2C_CLOCK.
Reconnect U1 pin 25 from SPI_SDO to /SPI_SDO.
Add net /CM_SENSE_PULSE.
Reconnect U1 pin 27 from SENSE_PULSE to /CM_SENSE_PULSE.
Reconnect U1 pin 5 from CP3_EN to /GPIO3_CP3_DC.
Reconnect U1 pin 32 from 3V3_MON to /ADC1.
Reconnect U1 pin 12 from SR_LAT to /CM_SR_LAT.
Add net /ADC0.
Reconnect U1 pin 31 from BAT_MON to /ADC0.
Reconnect U1 pin 16 from SR_SER to /CM_SR_SER1.
Reconnect U1 pin 26 from CORE_ARRAY_ENABLE to /CM_EN.
Reconnect U1 pin 18 from -BATT to -LABB.
Add net /CM_SENSE_RESET.
Reconnect U1 pin 1 from SENSE_RESET to /CM_SENSE_RESET.
Reconnect U1 pin 23 from -BATT to -LABB.
Reconnect U1 pin 40 from PICO_VBUS to 5VUSB.
Reconnect U1 pin 8 from -BATT to -LABB.
Reconnect U1 pin 7 from CP5_EN to /GPIO5_CP5_HS1.
Reconnect U1 pin 31 from BAT_MON to /ADC0.
Reconnect U1 pin 8 from -BATT to -LABB.
Reconnect U1 pin 11 from CP8_EN to /GPIO8_CP8_HS4.
Reconnect U1 pin 15 from I2C_CLOCK to /I2C_CLOCK.
Reconnect U1 pin 28 from -BATT to -LABB.
Reconnect U1 pin 7 from CP5_EN to /GPIO5_CP5_HS1.
Reconnect U1 pin 3 from -BATT to -LABB.
Reconnect U1 pin 1 from SENSE_RESET to /CM_SENSE_RESET.
Reconnect U1 pin 4 from CP2_EN to /GPIO2_CP2_SAO2.
Reconnect U1 pin 16 from SR_SER to /CM_SR_SER1.
Reconnect U1 pin 9 from CP6_EN to /GPIO6_CP6_HS2.
Reconnect U1 pin 10 from CP7_EN to /GPIO7_CP7_HS3.
Reconnect U1 pin 38 from -BATT to -LABB.
Reconnect U1 pin 27 from SENSE_PULSE to /CM_SENSE_PULSE.
Reconnect U1 pin 13 from -BATT to -LABB.
Reconnect U1 pin 17 from SR_CLK to /CM_SR_CLK.
Reconnect U1 pin 14 from I2C_DATA to /I2C_DATA.
Reconnect C14 pin 2 from -BATT to -LABB.
Reconnect U2 pin 4 from -BATT to -LABB.
Reconnect U2 pin 6 from I2C_CLOCK to /I2C_3V3_SCL.
Reconnect U2 pin 5 from I2C_DATA to /I2C_3V3_SDA.
Reconnect U2 pin 7 from -BATT to -LABB.
Reconnect C13 pin 2 from -BATT to -LABB.
Reconnect U3 pin 8 from -BATT to -LABB.
Reconnect U3 pin 14 from SR_SER to /CM_SR_SER1.
Add net /CA_SR_SER2.
Reconnect U3 pin 9 from Net-(U3-QH') to /CA_SR_SER2.
Reconnect U3 pin 5 from Q3P to /CM_Q3P.
Reconnect U3 pin 13 from -BATT to /CM_SR_~{OE}.
Reconnect U3 pin 4 from Q3N to /CM_Q3N.
Reconnect U3 pin 12 from SR_LAT to /CM_SR_LAT.
Reconnect U3 pin 1 from Q1P to /CM_Q1P.
Reconnect U3 pin 7 from Q4P to /CM_Q4P.
Reconnect U3 pin 2 from Q2N to /CM_Q2N.
Reconnect U3 pin 11 from SR_CLK to /CM_SR_CLK.
Reconnect U3 pin 6 from Q4N to /CM_Q4N.
Reconnect U3 pin 3 from Q2P to /CM_Q2P.
Reconnect U3 pin 15 from Q1N to /CM_Q1N.
Reconnect C12 pin 2 from -BATT to -LABB.
Reconnect U4 pin 14 from Net-(U3-QH') to /CA_SR_SER2.
Reconnect U4 pin 3 from Q6P to /CM_Q6P.
Reconnect U4 pin 7 from Q8P to /CM_Q8P.
Reconnect U4 pin 12 from SR_LAT to /CM_SR_LAT.
Reconnect U4 pin 6 from Q8N to /CM_Q8N.
Reconnect U4 pin 1 from Q5P to /CM_Q5P.
Reconnect U4 pin 13 from -BATT to /CM_SR_~{OE}.
Reconnect U4 pin 15 from Q5N to /CM_Q5N.
Reconnect U4 pin 4 from Q7N to /CM_Q7N.
Add net /CA_SR_SER3.
Reconnect U4 pin 9 from Net-(U4-QH') to /CA_SR_SER3.
Reconnect U4 pin 11 from SR_CLK to /CM_SR_CLK.
Reconnect U4 pin 8 from -BATT to -LABB.
Reconnect U4 pin 5 from Q7P to /CM_Q7P.
Reconnect U4 pin 2 from Q6N to /CM_Q6N.
Reconnect C11 pin 2 from -BATT to -LABB.
Reconnect U5 pin 3 from Q10P to /CM_Q10P.
Add net /CA_SR_GPO_A.
Reconnect U5 pin 4 from Net-(U5-QE) to /CA_SR_GPO_A.
Reconnect U5 pin 8 from -BATT to -LABB.
Add net /CA_SR_GPO_D.
Reconnect U5 pin 7 from Net-(U5-QH) to /CA_SR_GPO_D.
Reconnect U5 pin 13 from -BATT to /CM_SR_~{OE}.
Reconnect U5 pin 12 from SR_LAT to /CM_SR_LAT.
Reconnect U5 pin 14 from Net-(U4-QH') to /CA_SR_SER3.
Reconnect U5 pin 1 from Q9P to /CM_Q9P.
Reconnect U5 pin 15 from Q9N to /CM_Q9N.
Add net /CA_SR_GPO_B.
Reconnect U5 pin 5 from Net-(U5-QF) to /CA_SR_GPO_B.
Add net /CA_SR_GPO_C.
Reconnect U5 pin 6 from Net-(U5-QG) to /CA_SR_GPO_C.
Reconnect U5 pin 11 from SR_CLK to /CM_SR_CLK.
Reconnect U5 pin 2 from Q10N to /CM_Q10N.
Reconnect C10 pin 2 from -BATT to -LABB.
Reconnect U6 pin 5 from -BATT to -LABB.
Reconnect C9 pin 2 from -BATT to -LABB.
Reconnect U7 pin 2 from -BATT to -LABB.
Reconnect C8 pin 2 from -BATT to -LABB.
Reconnect U8 pin 3 from -BATT to -LABB.
Reconnect U8 pin 2 from LED_MATRIX_3V3_SIG to /LED_ARY_3V3_SIG.
Reconnect U8 pin 1 from -BATT to -LABB.
Reconnect C7 pin 2 from -BATT to -LABB.
Reconnect U9 pin 4 from -BATT to -LABB.
Reconnect U9 pin 5 from SENSE1 to /CM_SENSE_1_IN.
Reconnect U9 pin 3 from SENSE2 to /CM_SENSE_2_IN.
Reconnect C6 pin 2 from -BATT to -LABB.
Update U10 symbol association from /f689fd4c-a0ce-4408-baa7-6587441be90b to /351c8bf0-7036-4033-b8e3-6f6a54e6d682.
Reconnect U10 pin 8 from SENSE_RESET to /CM_SENSE_RESET.
Reconnect U10 pin 7 from -BATT to -LABB.
Reconnect U10 pin 10 from SENSE_PULSE to /CM_SENSE_PULSE.
Reconnect U10 pin 11 from SENSE_PULSE to /CM_SENSE_PULSE.
Reconnect C5 pin 2 from -BATT to -LABB.
Change J6 footprint from 'Connector_PinSocket_2.54mm:PinSocket_1x08_P2.54mm_Vertical' to 'Connector_PinSocket_2.54mm:PinSocket_1x10_P2.54mm_Vertical'.
Reconnect C4 pin 2 from -BATT to -LABB.
Change X4 value from HEADER_4-PIN_0.1 to CA_SR_GPO_ABCD.
Reconnect X4 pin 4 from Net-(U5-QH) to /CA_SR_GPO_D.
Reconnect X4 pin 3 from Net-(U5-QG) to /CA_SR_GPO_C.
Reconnect X4 pin 1 from Net-(U5-QE) to /CA_SR_GPO_A.
Reconnect X4 pin 2 from Net-(U5-QF) to /CA_SR_GPO_B.
Reconnect C3 pin 2 from -BATT to -LABB.
Change X6 reference designator to X5.
Change X6 value from HEADER_11-PIN_0.1 to Conn_01x11_Female.
Reconnect X6 pin 2 from SPI_RESET to /SPI_CLK.
Reconnect X6 pin 8 from SPI_SDI to /SPI_CD.
Reconnect X6 pin 5 from 3V3_MON to /GPIO4_CP4_CS2.
Reconnect X6 pin 10 from -BATT to 5V0.
Reconnect X6 pin 1 from CP4_EN to /SPI_SDO.
Reconnect X6 pin 7 from SPI_SDO to /SPI_SDI.
Reconnect X6 pin 6 from SPI_CS1 to /SPI_CS1.
Reconnect X6 pin 4 from SPARE_ADC2 to /SPI_RESET.
Reconnect X6 pin 3 from SPI_CD to /GPIO3_CP3_DC.
Add net unconnected-(X5-Pin_9-Pad9).
Reconnect X6 pin 9 from SPI_CLK to unconnected-(X5-Pin_9-Pad9).
Reconnect X6 pin 11 from 3V3 to -LABB.
Reconnect C2 pin 2 from -BATT to -LABB.
Change X9 value from QWIIC to Conn_4_QWIIC.
Reconnect X9 pin 4 from I2C_CLOCK to /I2C_3V3_SCL.
Reconnect copper zone 'GROUND' from -BATT to -LABB.
Reconnect X9 pin 3 from I2C_DATA to /I2C_3V3_SDA.
Reconnect X9 pin 1 from -BATT to -LABB.
Reconnect via from Net-(U4-QH') to /CA_SR_SER3.
Reconnect C1 pin 2 from -BATT to -LABB.
Change J12 footprint from 'Connector_PinSocket_2.54mm:PinSocket_1x08_P2.54mm_Vertical' to 'Connector_PinSocket_2.54mm:PinSocket_1x07_P2.54mm_Vertical'.
Add net -LABB.
Change X7 footprint from 'Connector_PinSocket_2.54mm:PinSocket_1x08_P2.54mm_Vertical' to 'Connector_PinSocket_2.54mm:PinSocket_1x07_P2.54mm_Vertical'.
Reconnect via from -BATT to -LABB.
Reconnect via from -BATT to -LABB.
Reconnect via from -BATT to -LABB.
Reconnect via from -BATT to -LABB.
Reconnect via from -BATT to -LABB.
Reconnect via from -BATT to -LABB.
Reconnect via from -BATT to -LABB.
Reconnect via from -BATT to -LABB.
Reconnect via from -BATT to -LABB.
Reconnect via from -BATT to -LABB.
Reconnect via from -BATT to -LABB.
Reconnect via from -BATT to -LABB.
Reconnect via from -BATT to -LABB.
Reconnect via from -BATT to -LABB.
Reconnect via from -BATT to -LABB.
Reconnect via from -BATT to -LABB.
Reconnect via from -BATT to -LABB.
Reconnect via from -BATT to -LABB.
Reconnect via from -BATT to -LABB.
Reconnect via from -BATT to -LABB.
Reconnect via from -BATT to -LABB.
Reconnect via from -BATT to -LABB.
Reconnect via from -BATT to -LABB.
Reconnect via from -BATT to -LABB.
Reconnect via from -BATT to -LABB.
Reconnect via from -BATT to -LABB.
Reconnect via from -BATT to -LABB.
Reconnect via from -BATT to -LABB.
Reconnect via from -BATT to -LABB.
Reconnect via from -BATT to -LABB.
Reconnect via from -BATT to -LABB.
Reconnect via from -BATT to -LABB.
Reconnect via from -BATT to -LABB.
Reconnect via from -BATT to -LABB.
Reconnect via from -BATT to -LABB.
Reconnect via from -BATT to -LABB.
Reconnect via from -BATT to -LABB.
Reconnect via from XB4 to /XB4.
Reconnect via from XB4 to /XB4.
Reconnect via from XB6 to /XB6.
Reconnect via from XB6 to /XB6.
Reconnect via from XB2 to /XB2.
Reconnect via from XB2 to /XB2.
Reconnect via from I2C_DATA to /I2C_3V3_SDA.
Reconnect via from I2C_CLOCK to /I2C_3V3_SCL.
Reconnect via from I2C_CLOCK to /I2C_3V3_SCL.
Reconnect via from I2C_CLOCK to /I2C_3V3_SCL.
Reconnect via from I2C_CLOCK to /I2C_3V3_SCL.
Reconnect via from I2C_CLOCK to /I2C_3V3_SCL.
Reconnect via from Q2P to /CM_Q2P.
Reconnect via from Q2P to /CM_Q2P.
Reconnect via from Q3P to /CM_Q3P.
Reconnect via from Q3P to /CM_Q3P.
Reconnect via from Q3N to /CM_Q3N.
Reconnect via from Q3N to /CM_Q3N.
Reconnect via from Q4P to /CM_Q4P.
Reconnect via from Q4P to /CM_Q4P.
Reconnect via from Q4N to /CM_Q4N.
Reconnect via from Q4N to /CM_Q4N.
Reconnect via from Q5P to /CM_Q5P.
Reconnect via from Q5P to /CM_Q5P.
Reconnect via from Q5P to /CM_Q5P.
Reconnect via from Q5P to /CM_Q5P.
Reconnect via from Q5N to /CM_Q5N.
Reconnect via from Q5N to /CM_Q5N.
Reconnect via from Q5N to /CM_Q5N.
Reconnect via from Q5N to /CM_Q5N.
Reconnect via from Q6P to /CM_Q6P.
Reconnect via from Q6P to /CM_Q6P.
Reconnect via from Q6N to /CM_Q6N.
Reconnect via from Q6N to /CM_Q6N.
Reconnect via from SENSE1 to /CM_SENSE_1_IN.
Reconnect via from SENSE1 to /CM_SENSE_1_IN.
Reconnect via from SENSE2 to /CM_SENSE_2_IN.
Reconnect via from SENSE2 to /CM_SENSE_2_IN.
Reconnect via from SENSE2 to /CM_SENSE_2_IN.
Reconnect via from SENSE2 to /CM_SENSE_2_IN.
Reconnect via from SENSE2 to /CM_SENSE_2_IN.
Reconnect via from Net-(U4-QH') to /CA_SR_SER3.
Reconnect via from Q10P to /CM_Q10P.
Reconnect via from Q10P to /CM_Q10P.
Reconnect via from Q10N to /CM_Q10N.
Reconnect via from Q10N to /CM_Q10N.
Reconnect via from Q9P to /CM_Q9P.
Reconnect via from Q9P to /CM_Q9P.
Reconnect via from Q9N to /CM_Q9N.
Reconnect via from Q9N to /CM_Q9N.
Reconnect via from Q7P to /CM_Q7P.
Reconnect via from Q7P to /CM_Q7P.
Reconnect via from Q7N to /CM_Q7N.
Reconnect via from Q7N to /CM_Q7N.
Reconnect via from Q7N to /CM_Q7N.
Reconnect via from Q7N to /CM_Q7N.
Reconnect via from Q8P to /CM_Q8P.
Reconnect via from Q8P to /CM_Q8P.
Reconnect via from Q8N to /CM_Q8N.
Reconnect via from Q8N to /CM_Q8N.
Reconnect via from Q8N to /CM_Q8N.
Reconnect via from Q8N to /CM_Q8N.
Reconnect via from Q8N to /CM_Q8N.
Reconnect via from Q8N to /CM_Q8N.
Reconnect via from Q8N to /CM_Q8N.
Reconnect via from Q8N to /CM_Q8N.
Reconnect via from SENSE_PULSE to /CM_SENSE_PULSE.
Reconnect via from SENSE_PULSE to /CM_SENSE_PULSE.
Reconnect via from SENSE_PULSE to /CM_SENSE_PULSE.
Reconnect via from +BATT to +LABB.
Reconnect via from +BATT to +LABB.
Reconnect via from +BATT to +LABB.
Reconnect via from +BATT to +LABB.
Reconnect via from SENSE_RESET to /CM_SENSE_RESET.
Reconnect via from SENSE_RESET to /CM_SENSE_RESET.
Reconnect via from SENSE_RESET to /CM_SENSE_RESET.
Reconnect via from SENSE_RESET to /CM_SENSE_RESET.
Reconnect via from SENSE_RESET to /CM_SENSE_RESET.
Reconnect via from SENSE_RESET to /CM_SENSE_RESET.
Reconnect via from CP5_EN to /GPIO5_CP5_HS1.
Reconnect via from CP5_EN to /GPIO5_CP5_HS1.
Reconnect via from CP6_EN to /GPIO6_CP6_HS2.
Reconnect via from CP6_EN to /GPIO6_CP6_HS2.
Reconnect via from CP7_EN to /GPIO7_CP7_HS3.
Reconnect via from CP7_EN to /GPIO7_CP7_HS3.
Reconnect via from CP8_EN to /GPIO8_CP8_HS4.
Reconnect via from CP8_EN to /GPIO8_CP8_HS4.
Reconnect via from CP8_EN to /GPIO8_CP8_HS4.
Reconnect via from CP8_EN to /GPIO8_CP8_HS4.
Reconnect via from CP4_EN to /SPI_SDO.
Reconnect via from CP4_EN to /SPI_SDO.
Reconnect via from CP4_EN to /SPI_SDO.
Reconnect via from CP4_EN to /SPI_SDO.
Reconnect via from CP4_EN to /SPI_SDO.
Reconnect via from CP4_EN to /SPI_SDO.
Reconnect via from CP4_EN to /SPI_SDO.
Reconnect via from CP4_EN to /SPI_SDO.
Reconnect via from CP4_EN to /SPI_SDO.
Reconnect via from CP3_EN to /GPIO3_CP3_DC.
Reconnect via from CP3_EN to /GPIO3_CP3_DC.
Reconnect via from CP3_EN to /GPIO3_CP3_DC.
Reconnect via from CP3_EN to /GPIO3_CP3_DC.
Reconnect via from CP3_EN to /GPIO3_CP3_DC.
Reconnect via from CP3_EN to /GPIO3_CP3_DC.
Reconnect via from CP3_EN to /GPIO3_CP3_DC.
Reconnect via from CP2_EN to /GPIO2_CP2_SAO2.
Reconnect via from CP2_EN to /GPIO2_CP2_SAO2.
Reconnect via from CP2_EN to /GPIO2_CP2_SAO2.
Reconnect via from CP2_EN to /GPIO2_CP2_SAO2.
Reconnect via from CP2_EN to /GPIO2_CP2_SAO2.
Reconnect via from CP2_EN to /GPIO2_CP2_SAO2.
Reconnect via from CP2_EN to /GPIO2_CP2_SAO2.
Reconnect via from CP1_EN to /GPIO1_CP1_SAO1.
Reconnect via from CP1_EN to /GPIO1_CP1_SAO1.
Reconnect via from CP1_EN to /GPIO1_CP1_SAO1.
Reconnect via from CP1_EN to /GPIO1_CP1_SAO1.
Reconnect via from CP1_EN to /GPIO1_CP1_SAO1.
Reconnect via from CP1_EN to /GPIO1_CP1_SAO1.
Reconnect via from CP1_EN to /GPIO1_CP1_SAO1.
Reconnect via from CP1_EN to /GPIO1_CP1_SAO1.
Reconnect via from Q1N to /CM_Q1N.
Reconnect via from Q1N to /CM_Q1N.
Reconnect via from BAT_MON to /ADC0.
Reconnect via from BAT_MON to /ADC0.
Reconnect via from BAT_MON to /ADC0.
Reconnect via from BAT_MON to /ADC0.
Reconnect via from BAT_MON to /ADC0.
Reconnect via from BAT_MON to /ADC0.
Reconnect via from LED_MATRIX_3V3_SIG to /LED_ARY_3V3_SIG.
Reconnect via from LED_MATRIX_3V3_SIG to /LED_ARY_3V3_SIG.
Reconnect via from LED_MATRIX_3V3_SIG to /LED_ARY_3V3_SIG.
Reconnect via from LED_MATRIX_3V3_SIG to /LED_ARY_3V3_SIG.
Reconnect via from LED_MATRIX_3V3_SIG to /LED_ARY_3V3_SIG.
Reconnect via from LED_MATRIX_3V3_SIG to /LED_ARY_3V3_SIG.
Reconnect via from XB0 to /XB0.
Reconnect via from XB0 to /XB0.
Reconnect via from Q1P to /CM_Q1P.
Reconnect via from Q1P to /CM_Q1P.
Reconnect via from Q2N to /CM_Q2N.
Reconnect via from Q2N to /CM_Q2N.
Reconnect via from 3V3_MON to /GPIO4_CP4_CS2.
Reconnect via from 3V3_MON to /GPIO4_CP4_CS2.
Reconnect via from 3V3_MON to /GPIO4_CP4_CS2.
Reconnect via from SPARE_ADC2 to /SPI_RESET.
Reconnect via from SPARE_ADC2 to /SPI_RESET.
Reconnect via from SPARE_ADC2 to /SPI_RESET.
Reconnect via from CORE_ARRAY_ENABLE to /CM_EN.
Reconnect via from CORE_ARRAY_ENABLE to /CM_EN.
Reconnect via from CORE_ARRAY_ENABLE to /CM_EN.
Reconnect via from CORE_ARRAY_ENABLE to /CM_EN.
Reconnect via from SR_SER to /CM_SR_SER1.
Reconnect via from SR_SER to /CM_SR_SER1.
Reconnect via from SR_SER to /CM_SR_SER1.
Reconnect via from SR_CLK to /CM_SR_CLK.
Reconnect via from SR_CLK to /CM_SR_CLK.
Reconnect via from SR_CLK to /CM_SR_CLK.
Reconnect via from SPI_CS1 to /SPI_CS1.
Reconnect via from SPI_CS1 to /SPI_CS1.
Reconnect via from SPI_CS1 to /SPI_CS1.
Reconnect via from SR_LAT to /CM_SR_LAT.
Reconnect via from SR_LAT to /CM_SR_LAT.
Reconnect via from SR_LAT to /CM_SR_LAT.
Reconnect via from SPI_RESET to /SPI_CLK.
Reconnect via from SPI_RESET to /SPI_CLK.
Reconnect via from SPI_SDI to /SPI_CD.
Reconnect via from SPI_SDI to /SPI_CD.
Reconnect via from SPI_SDI to /SPI_CD.
Reconnect via from SPI_CLK to unconnected-(X5-Pin_9-Pad9).
Reconnect via from SPI_CLK to unconnected-(X5-Pin_9-Pad9).
Reconnect via from SPI_SDO to /SPI_SDI.
Reconnect via from SPI_SDO to /SPI_SDI.
Reconnect via from SPI_SDO to /SPI_SDI.
Reconnect via from SPI_SDO to /SPI_SDI.
Reconnect via from SPI_SDO to /SPI_SDI.
Reconnect via from Net-(U3-QH') to /CA_SR_SER2.
Reconnect via from Net-(U3-QH') to /CA_SR_SER2.
Warning: Via connected to unknown net (Net-(JP6-C)).
Warning: No net found for component X9 pad MP (no pin MP in symbol).
Warning: No net found for component X9 pad MP (no pin MP in symbol).

Info: Total warnings: 3, errors: 0.

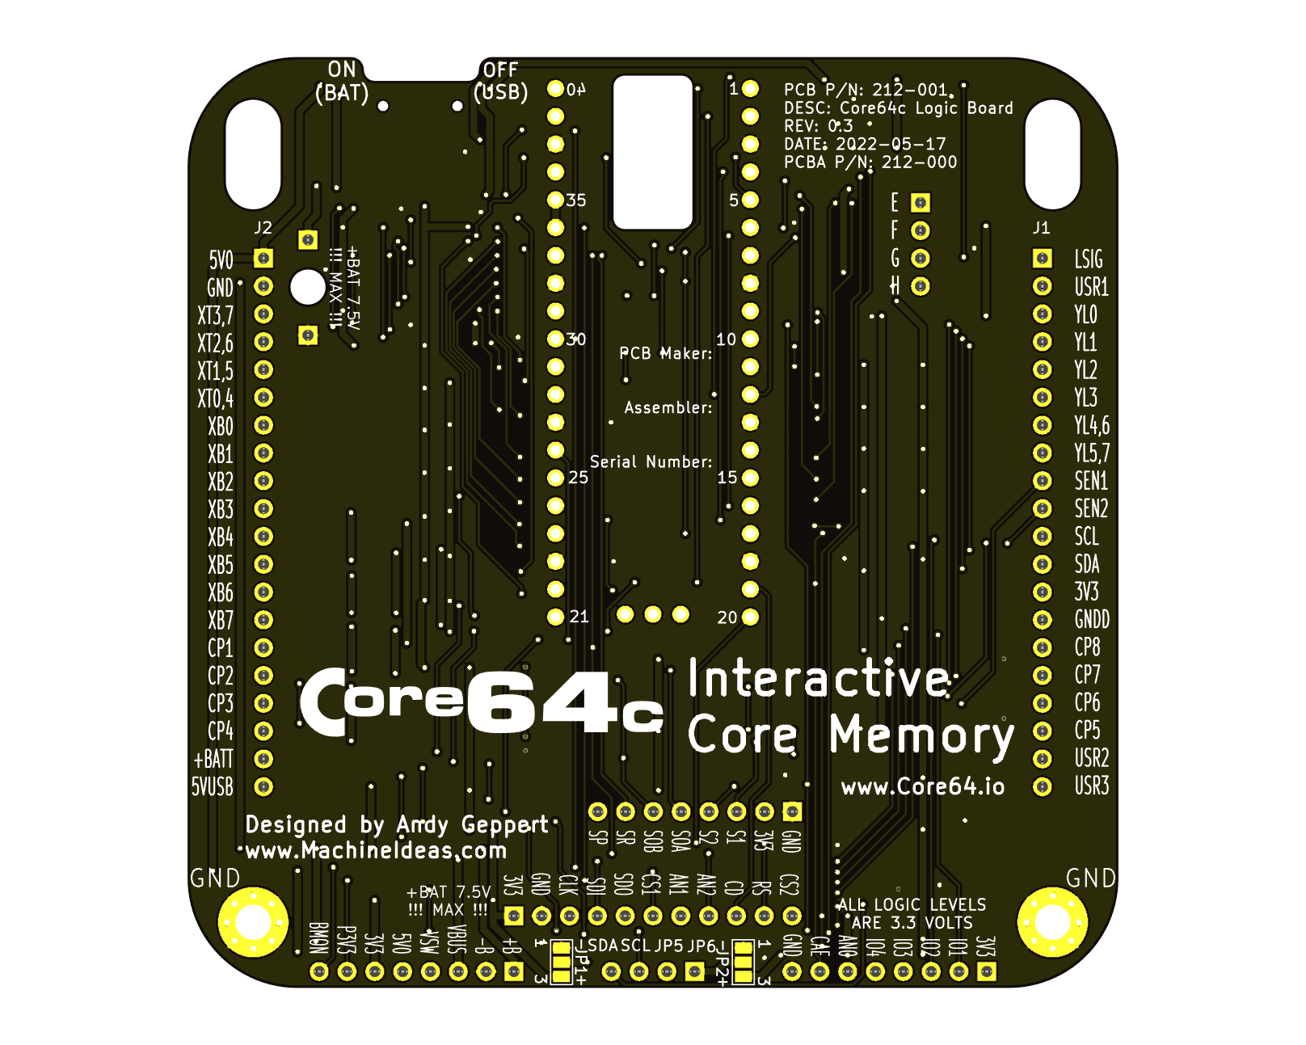
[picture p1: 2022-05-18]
Electronics/Core64c LB V0.3/Core64c LB V0.3 Render Back.png

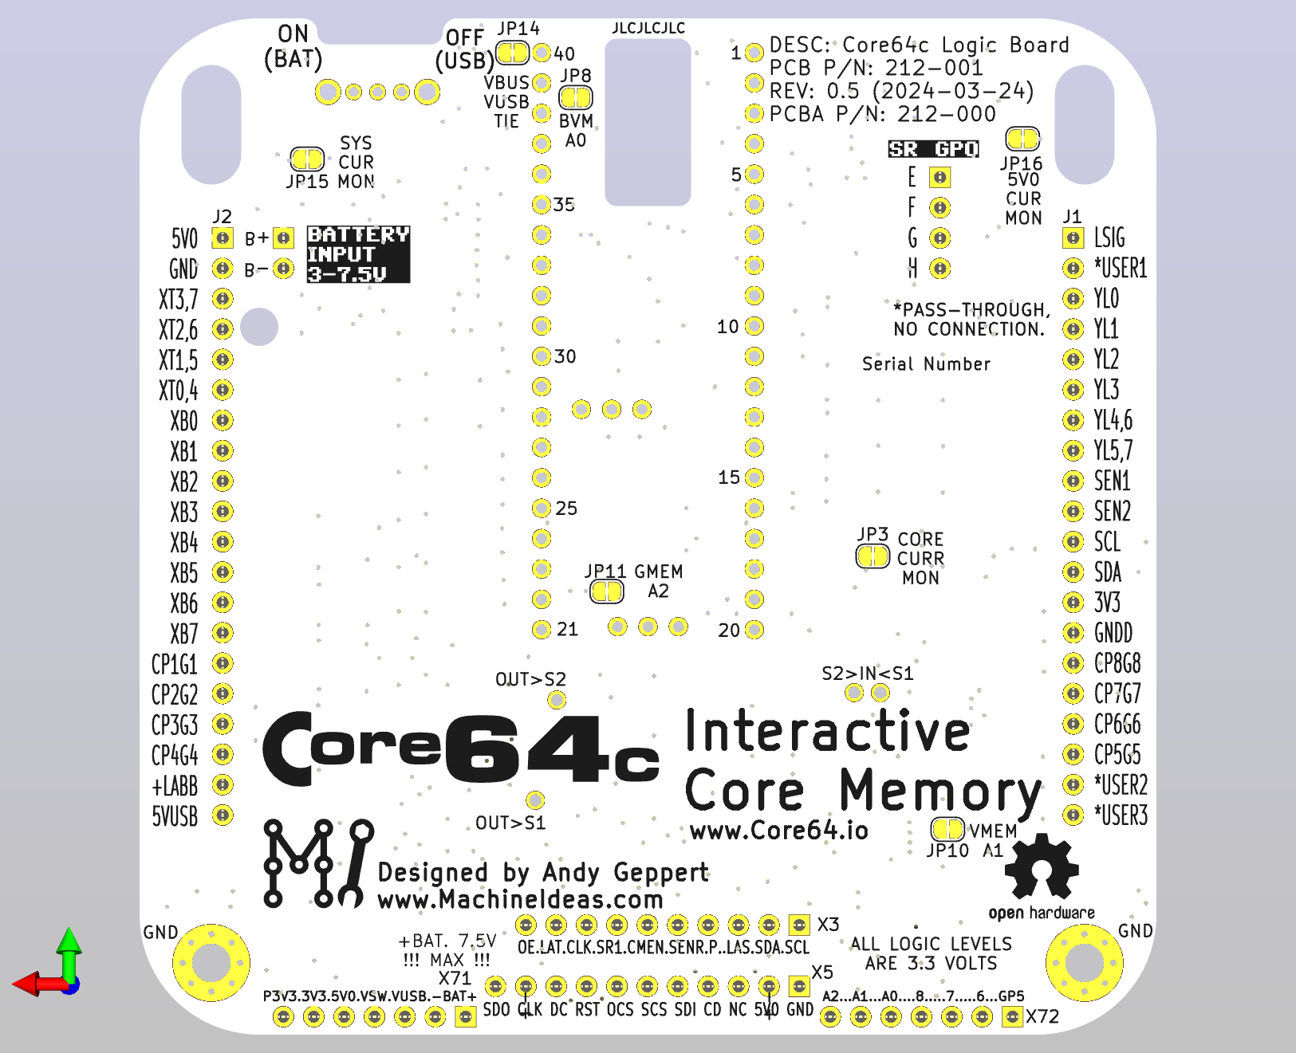
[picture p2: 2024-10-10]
Electronics/Core64c LB V0.5 Schematic and Renders/Render Core64c LB V0.5 Back.png

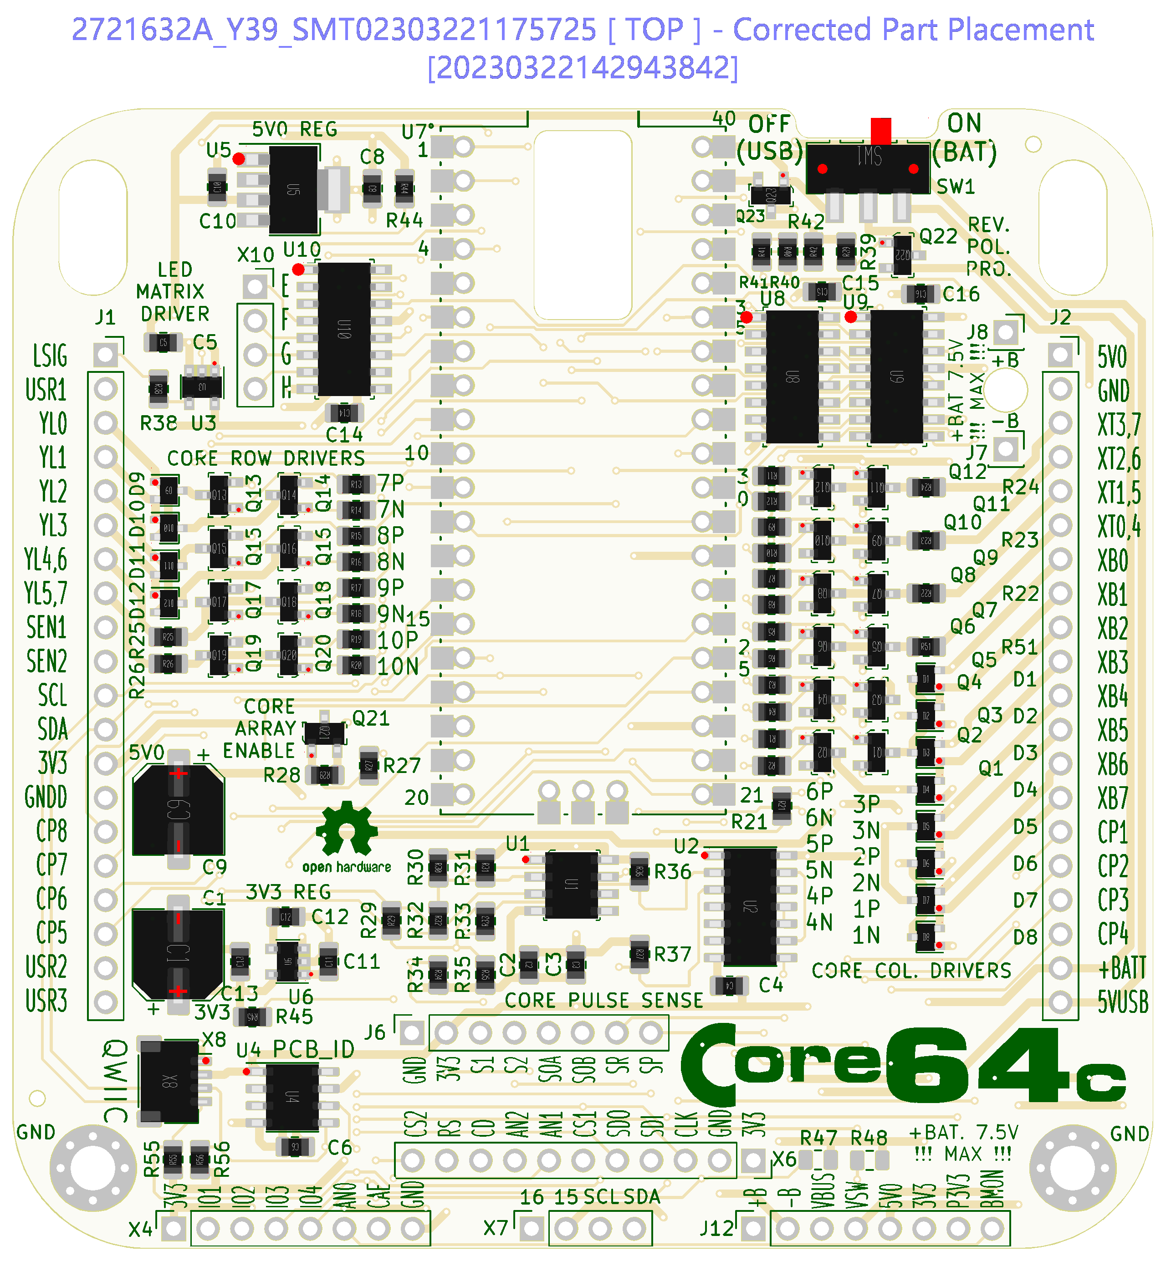
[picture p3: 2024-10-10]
Electronics/Core64c LB V0.4 KiCAD 5/Core64c Production File Review/Produce_DanZhi.SMT_Snapshot.Top.2721632A_Y39.SMT02303221175725.png

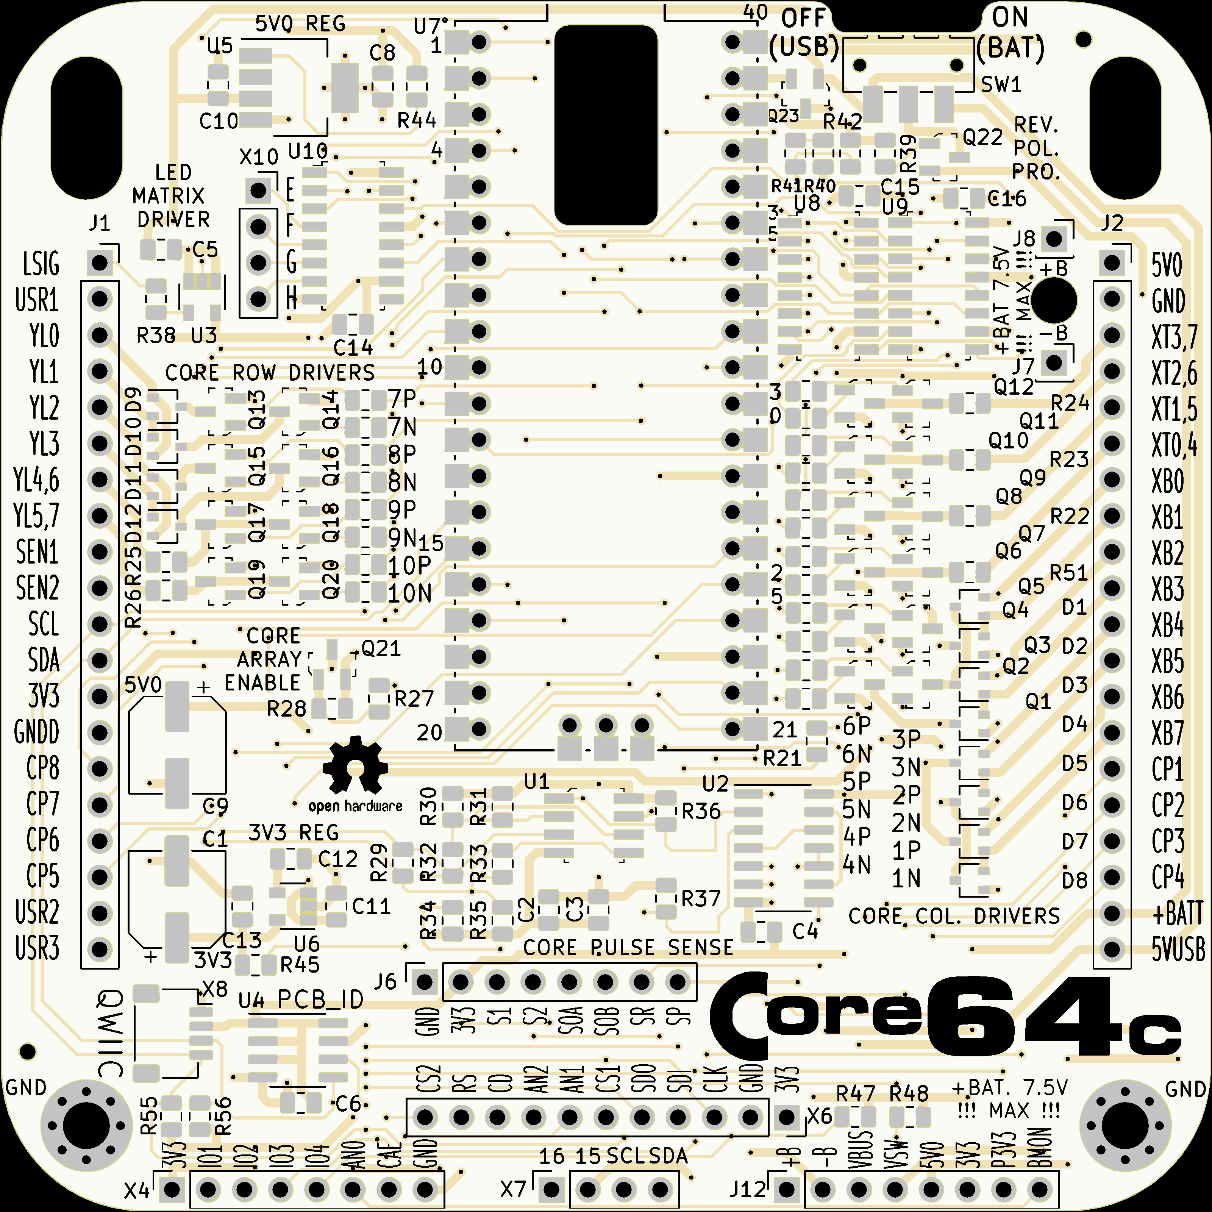
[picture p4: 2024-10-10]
Electronics/Core64c LB V0.4 KiCAD 5/Core64c Production File Review/jlcS2K58HEJHQ69top-4480x3200.png

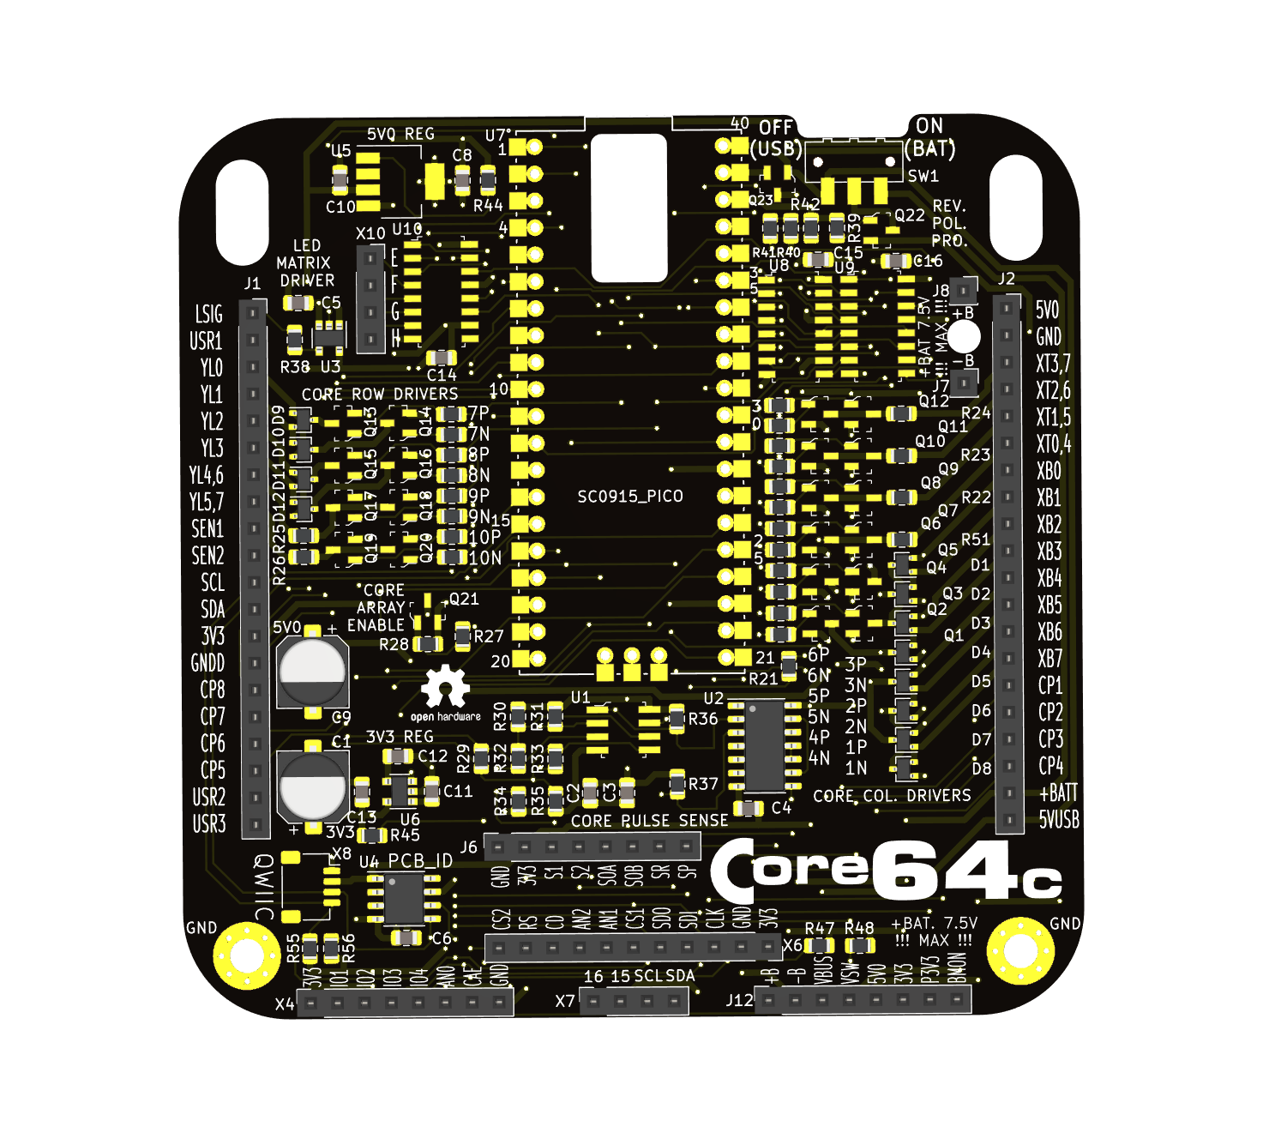
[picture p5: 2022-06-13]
Electronics/Core64c LB V0.4 KiCAD 5/Core64c LB v0.4 Render Top.png

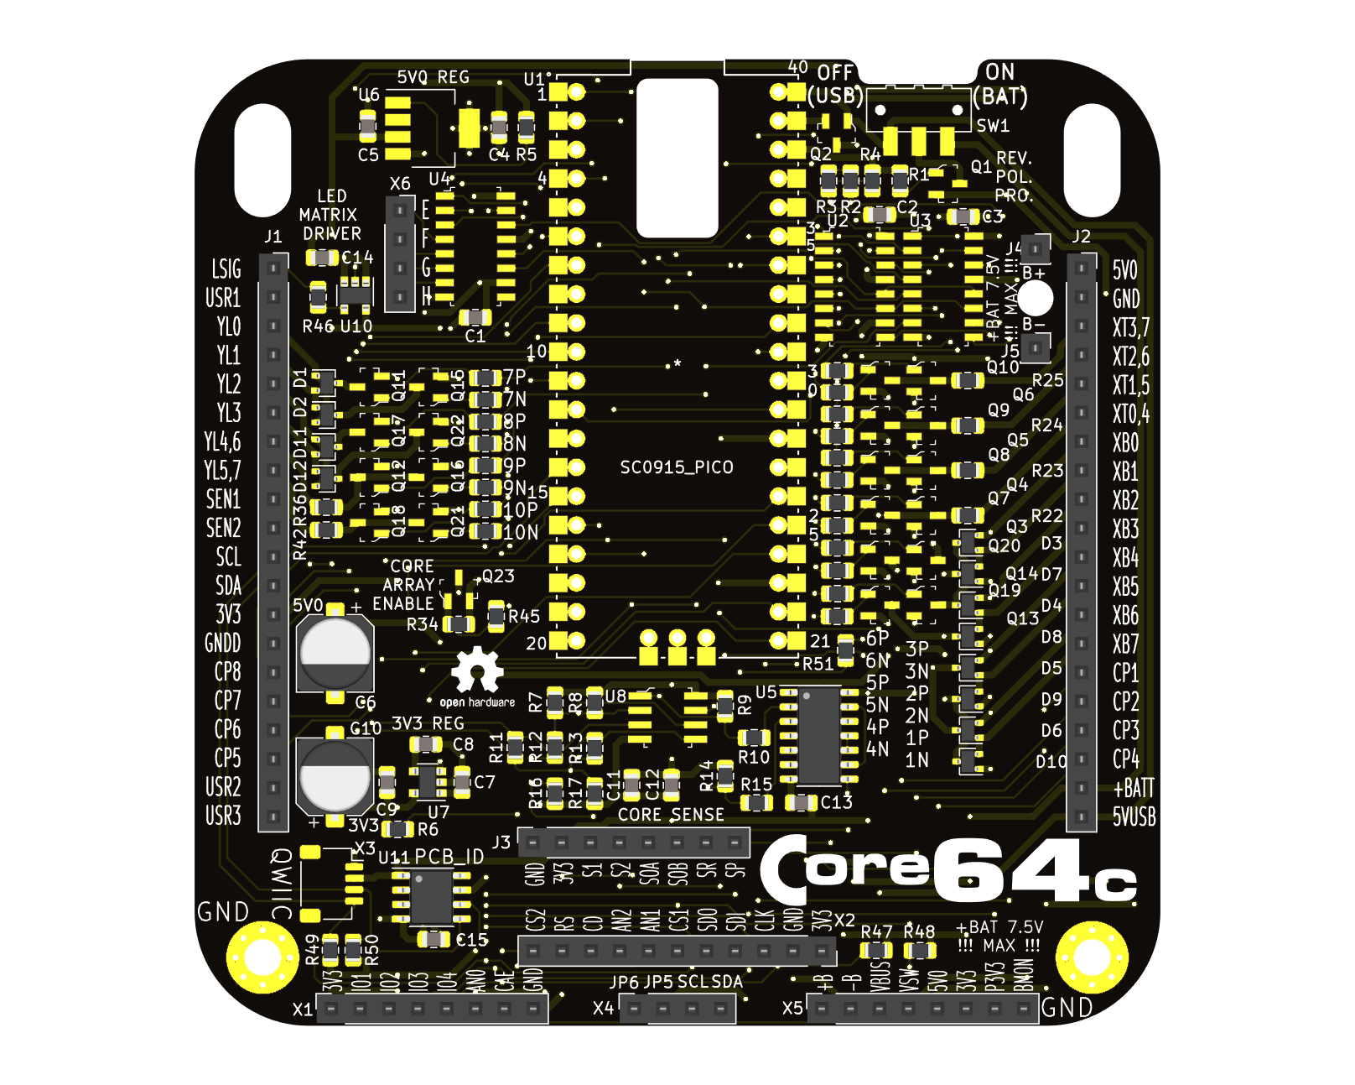
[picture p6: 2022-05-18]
Electronics/Core64c LB V0.3/Core64c LB V0.3 Render Front.png

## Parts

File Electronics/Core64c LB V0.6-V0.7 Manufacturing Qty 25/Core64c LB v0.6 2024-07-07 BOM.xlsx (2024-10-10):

Comment | Designator | Footprint | LCSC Part Number | Substituted
0.1uF | C1, C2, C3, C4, C16, C17, C19 | Capacitor_SMD:C_0805_2012Metric | C28233
1uF | C5, C6, C10, C12 | Capacitor_SMD:C_0805_2012Metric | C28323
220uF | C7, C8, C9, C13, C14, C15 | Capacitor_SMD:C_1206_3216Metric | C412252
0.01uF | C11 | Capacitor_SMD:C_0805_2012Metric | C1710
10uF | C18 | Capacitor_SMD:C_0805_2012Metric | C17024
BAT54AW | D1, D3, D5, D7, D9, D11 | Package_TO_SOT_SMD:SOT-323_SC-70 | C78261
BAT54CW | D2, D4, D6, D8, D10, D12 | Package_TO_SOT_SMD:SOT-323_SC-70 | C83573 | C5240624
MMBT4403LT1G | Q1, Q3, Q5, Q7, Q9, Q11, Q13, Q15, Q17, Q19 | digikey-footprints:SOT-23-3 | C78864
MMBT4401LT1G | Q2, Q4, Q6, Q8, Q10, Q12, Q14, Q16, Q18, Q20 | digikey-footprints:SOT-23-3 | C31776
Q_NMOS_DGS_AO3400A | Q21 | digikey-footprints:SOT-23-3 | C20917
SL3401A | Q22, Q23 | digikey-footprints:SOT-23-3 | C350311
470 | R1, R2, R3, R4, R5, R6, R7, R8, R9, R10, R11, R12, R13, R14, R15, R16, R17, R18, R19, R20, R28, R46 | Resistor_SMD:R_0805_2012Metric | C17710
8R2-1% | R21, R22, R23, R24, R25, R26 | Resistor_SMD:R_0805_2012Metric | C17830
10k | R27, R29, R34, R35, R36, R37, R38, R44, R45, R54, R55 | Resistor_SMD:R_0805_2012Metric | C17673 | This may have been 4.7K
1K2 | R30, R31 | Resistor_SMD:R_0805_2012Metric | C17379
68 | R32, R33 | Resistor_SMD:R_0805_2012Metric | C17802
1K5-1% | R47, R50, R53 | Resistor_SMD:R_0805_2012Metric | C4310
1K8-1% | R48, R51 | Resistor_SMD:R_0805_2012Metric | C17398
11-1% | R49, R52 | Resistor_SMD:R_0805_2012Metric | C17430
SK12D07L4B | SW1 | Switch_XKB_SK12D07VG4_SK12D07L4B:SK12D07VG4 | C480340
M24C02 | U2 | Package_SO:SOIC-8_3.9x4.9mm_P1.27mm | C7562
74HC595D | U3, U4, U5 | digikey-footprints:SOIC-16_W3.90mm | C5947
LP38693MP-5.0 | U6 | Package_TO_SOT_SMD:SOT-223-5 | C140294
SSP9193-33M5R | U7 | Package_TO_SOT_SMD:SOT-23-5 | C411022
SN74LV1T125DBVR | U8 | Package_TO_SOT_SMD:SOT-23-5 | C473338
LM393 | U9 | digikey-footprints:SOIC-8_W3.9mm | C7955
74HC02 | U10 | Package_SO:SOIC-14_3.9x8.7mm_P1.27mm | C350559
Conn_4_QWIIC | X9 | Connector_JST:JST_SH_SM04B-SRSS-TB_1x04-1MP_P1.00mm_Horizontal | C160404

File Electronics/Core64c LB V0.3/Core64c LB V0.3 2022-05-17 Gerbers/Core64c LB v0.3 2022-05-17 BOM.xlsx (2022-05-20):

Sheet: Core64C LB v0.3 BOM
Comment | Designator | Footprint | LCSC Part Number
0.1uF | C1, C2, C3, C11, C13, C14, C15 | Capacitor_SMD:C_0805_2012Metric | C28233
470uF | C6, C10 | Capacitor_SMD:CP_Elec_6.3x7.7 | C335982
0.01uF | C8 | Capacitor_SMD:C_0805_2012Metric | C16834
1uF | C9, C7, C4, C5 | Capacitor_SMD:C_0805_2012Metric | C16834
10uF | C12 | Capacitor_SMD:C_0805_2012Metric | C17024
BAT54AW | D3, D4, D5, D6, D11, D1 | Package_TO_SOT_SMD:SOT-323_SC-70 | C78261
BAT54CW | D7, D8, D10, D9, D12, D2 | Package_TO_SOT_SMD:SOT-323_SC-70 | C83573
SL3401A | Q1, Q2 | Digikey:SOT-23-3 | C350311
MMBT4403LT1G | Q3, Q14, Q5, Q11, Q17, Q12, Q18, Q13, Q4, Q6 | Digikey:SOT-23-3 | C78864
MMBT4401LT1G | Q7, Q20, Q9, Q10, Q15, Q22, Q16, Q21, Q19, Q8 | Digikey:SOT-23-3 | C31776
Q_NMOS_DGS_NVTR4503NT1G | Q23 | Digikey:SOT-23-3 | C184182 | INVENTORY SHORTAGE
1K8-1% | R7, R8 | Resistor_SMD:R_0805_2012Metric | C17398
10k | R9, R14, R15, R10, R4, R5, R1, R2, R3, R6, R34, R51 | Resistor_SMD:R_0805_2012Metric | C17414
11-1% | R12, R13 | Resistor_SMD:R_0805_2012Metric | C17430
1K5-1% | R16, R11, R17 | Resistor_SMD:R_0805_2012Metric | C4310
6R8-1% | R22, R23, R24, R36, R42, R25 | Resistor_SMD:R_0805_2012Metric | C17774
470 | R46, R18, R26, R33, R41, R19, R27, R20, R28, R21, R29, R30, R35, R38, R44, R31, R37, R39, R43, R32, R40, R45 | Resistor_SMD:R_0805_2012Metric | C17710
1K2 | R49, R50 | Resistor_SMD:R_0805_2012Metric | C17379
JS102011SAQN | SW1 | Button_Switch_SMD:SW_SPDT_CK-JS102011SAQN_Core64_Recessed | C221660
74HC595D | U2, U3, U4 | Digikey:SOIC-16_W3.90mm | C5947
74HC02 | U5 | Package_SO:SOIC-14_3.9x8.7mm_P1.27mm | C350559
LP38693MP-5.0 | U6 | Package_TO_SOT_SMD:SOT-223-5 | C140294
SGM2007-3.3XN5_TR | U7 | Package_TO_SOT_SMD:SOT-23-5 | C193687 | INVENTORY SHORTAGE
LM393 | U8 | Digikey:SOIC-8_W3.9mm | C7955
SN74LV1T125DBVR | U10 | Package_TO_SOT_SMD:SOT-23-5 | C473338
M24C02 | U11 | Package_SO:SOIC-8_3.9x4.9mm_P1.27mm | C7562
QWIIC | X3 | Connector_JST:JST_SH_SM04B-SRSS-TB_1x04-1MP_P1.00mm_Horizontal | C160404 | INVENTORY SHORTAGE

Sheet: Component Prices Qty5
Selected Parts(24 items)
Download Selected Parts List
Part Detail | Designator | Qty | Source | Price
 | C8,C9,C7,C4,C5 | 30 | JLCPCB | $0.2730
CL21F105ZOFNNNE
Extended PartC16834
 | R46,R18,R26,R33... | 110 | JLCPCB | $0.2420
0805W8F4700T5E
Basic PartC17710
 | U7 | 10 | JLCPCB | $2.0910
SGM2007-3.3XN5/TR
Extended PartC193687
 | Q7,Q20,Q9,Q10,Q... | 54 | JLCPCB | $8.8776
MMBT4401LT1G
Extended PartC31776
 | U11 | 5 | JLCPCB | $0.7245
M24C02-WMN6TP
Basic PartC7562
 | U2,U3,U4 | 15 | JLCPCB | $3.8160
74HC595D,118
Basic PartC5947
 | D7,D8,D10,D9,D1... | 34 | JLCPCB | $1.4790
BAT54CW-7-F
Extended PartC83573
 | Q1,Q2 | 15 | JLCPCB | $0.9810
SL3401A
Extended PartC350311
 | U5 | 5 | JLCPCB | $0.9260
SN74HC02DR
Extended PartC350559
 | U6 | 5 | JLCPCB | $5.9695
LP38693MP-5.0/NOPB
Extended PartC140294
 | Q3,Q14,Q5,Q11,Q... | 54 | JLCPCB | $2.6190
MMBT4403LT1G
Extended PartC78864
 | U10 | 10 | JLCPCB | $13.7750
SN74LV1T125DBVR
Extended PartC473338
 | D3,D4,D5,D6,D11... | 34 | JLCPCB | $1.5266
BAT54AW,115
Extended PartC78261
 | R12,R13 | 20 | JLCPCB | $0.0500
0805W8F110JT5E
Extended PartC17430
 | R9,R14,R15,R10,... | 60 | JLCPCB | $0.1200
0805W8F1002T5E
Basic PartC17414
 | R16,R11,R17 | 20 | JLCPCB | $0.0480
0805W8F1501T5E
Basic PartC4310
 | R7,R8 | 20 | JLCPCB | $0.0500
0805W8F1801T5E
Basic PartC17398
 | C12 | 20 | JLCPCB | $0.1700
CL21A106KPFNNNE
Extended PartC17024
 | C1,C2,C3,C11,C1... | 35 | JLCPCB | $0.3045
CL21B104KCFNNNE
Basic PartC28233
 | SW1 | 5 | JLCPCB | $2.4225
JS102011SAQN
Extended PartC221660
 | C6,C10 | 10 | JLCPCB | $0.4070
RVT1A471M0607
Extended PartC335982
 | R22,R23,R24,R36... | 35 | JLCPCB | $0.1400
0805W8F680KT5E
Extended PartC17774
 | U8 | 5 | JLCPCB | $0.6715
LM393DR2G
Basic PartC7955
 | R49,R50 | 20 | JLCPCB | $0.0560
0805W8F1201T5E
Basic PartC17379
Show Less

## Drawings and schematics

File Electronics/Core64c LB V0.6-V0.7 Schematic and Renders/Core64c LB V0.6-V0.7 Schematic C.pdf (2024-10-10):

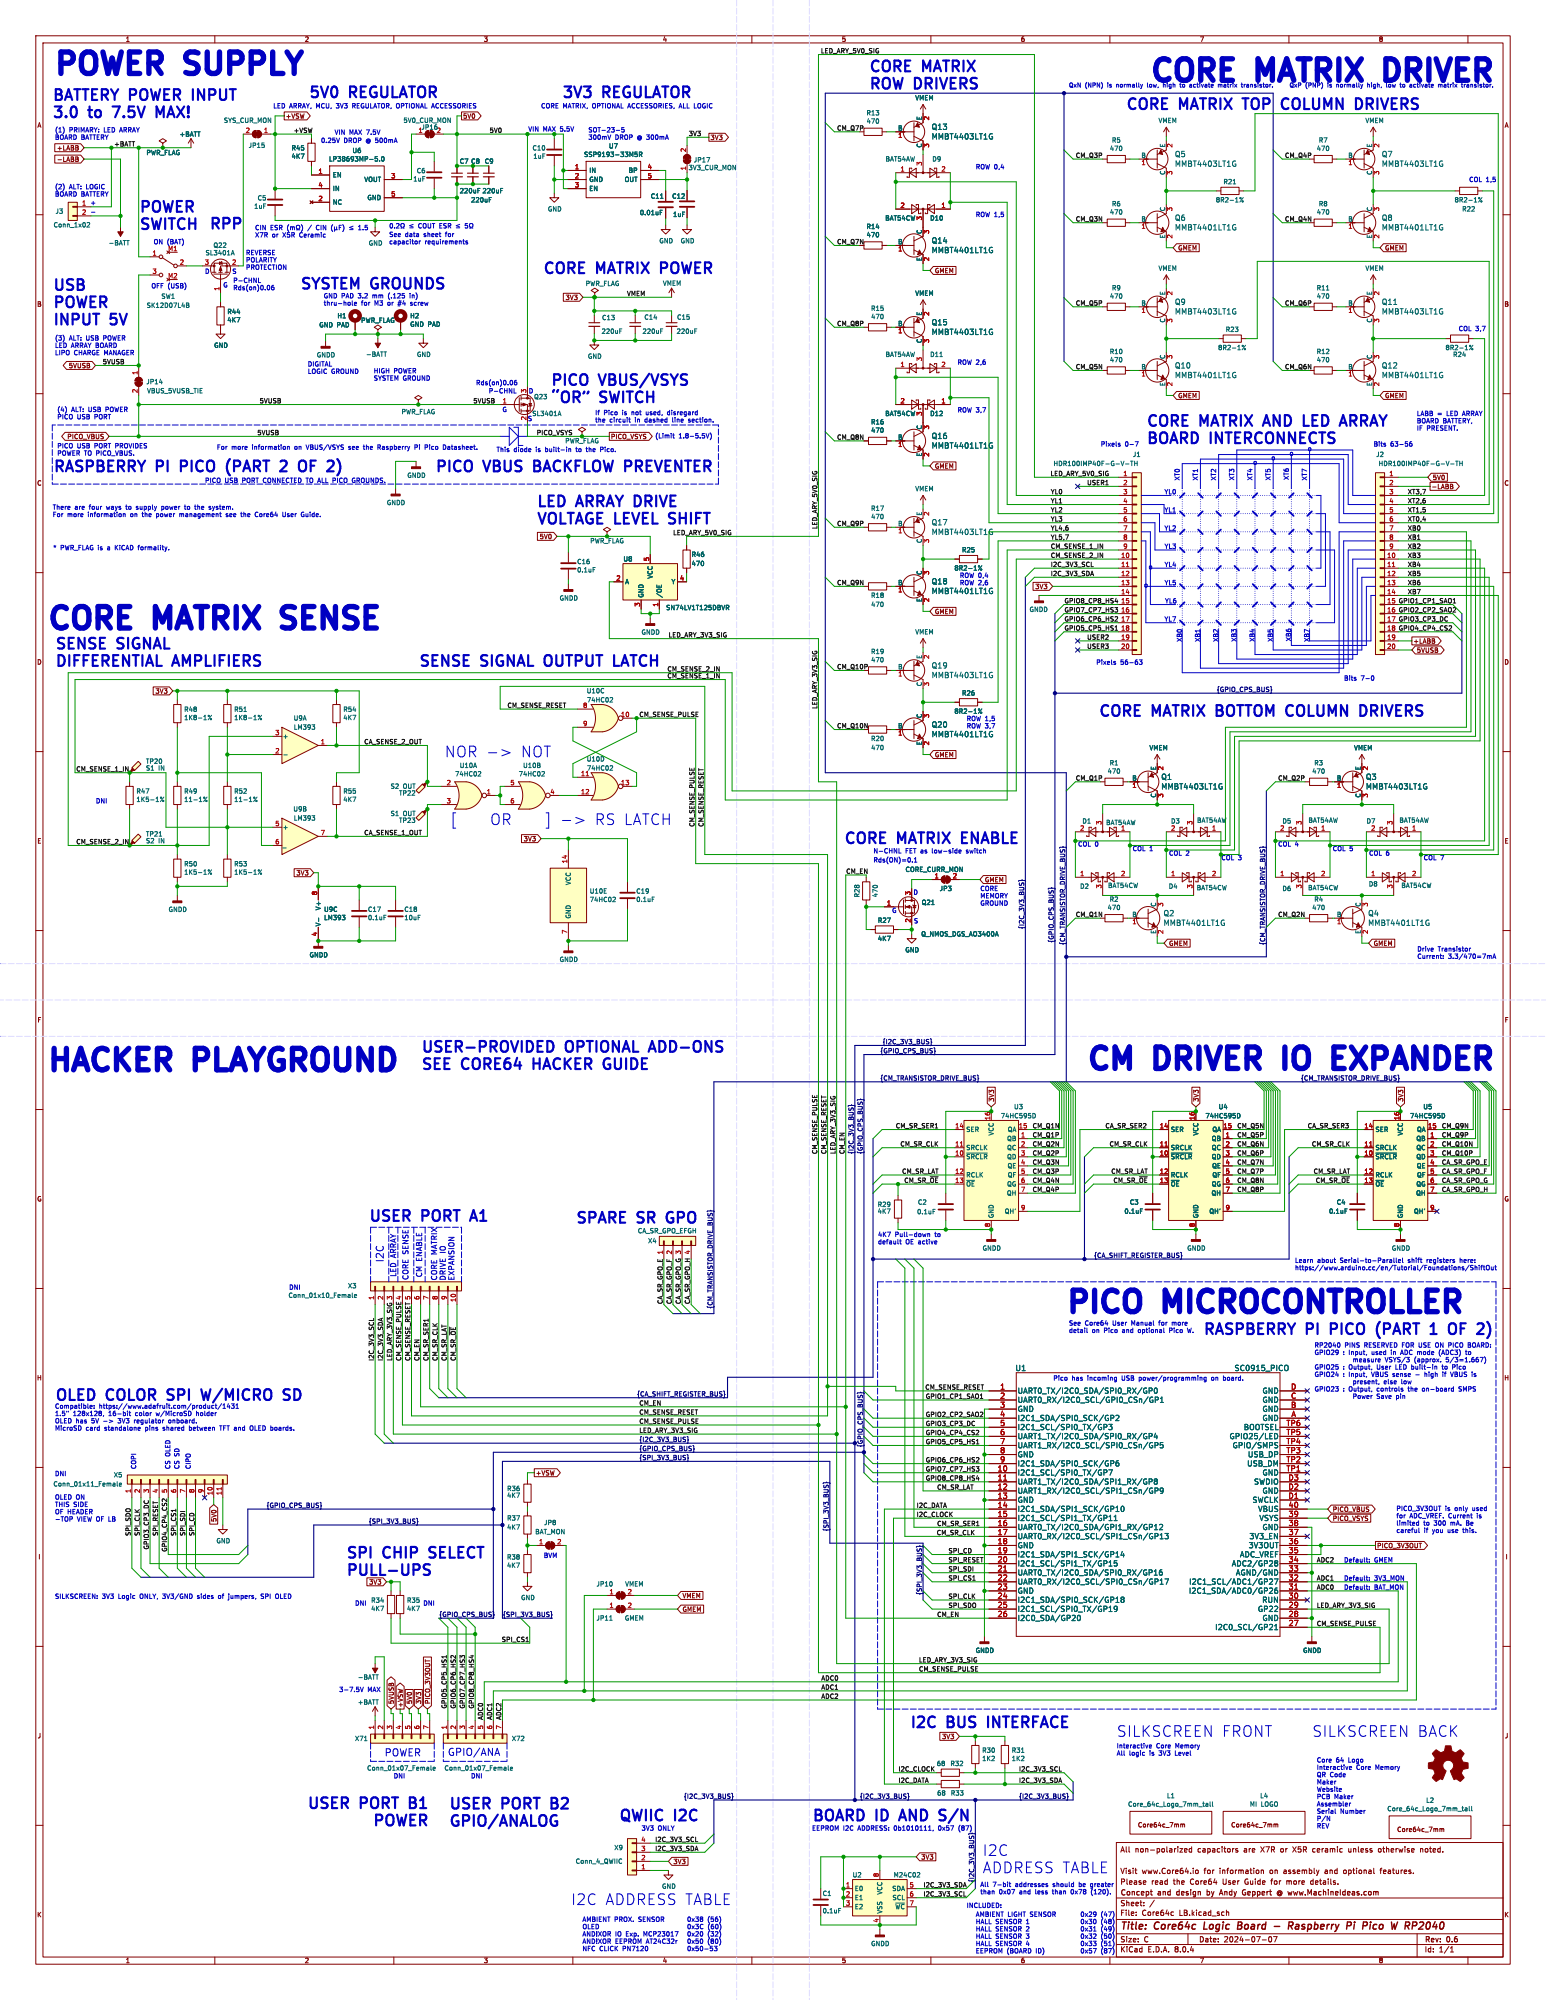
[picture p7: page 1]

LED ARRAY, MCU, 3V3 REGULATOR, OPTIONAL ACCESSORIES
+VSW

CORE MATRIX, OPTIONAL ACCESSORIES, ALL LOGIC

CORE MATRIX TOP COLUMN DRIVERS

CIN ESR þÿ(m©) / CIN þÿ(¼F) þÿ"d1.5 X7R or X5R Ceramic REVERSE

þÿ0.2©þÿ"dCOUT ESR þÿ"dþÿ5©

GND PAD 3.2 mm (.125 in)
H1 GND PAD

POWER TO PICO_VBUS. POWER FLOW

5VUSB GMEM
CORE MATRIX AND LED ARRAY
BOARD INTERCONNECTS

If Pico is not used, disregard

PICO_VBUS
PICO USB PORT PROVIDES
RASPBERRY PI PICO (PART 2 OF 2)

PICO VBUS BACKFLOW PREVENTER

SENSE SIGNAL OUTPUT LATCH

CORE MATRIX BOTTOM COLUMN DRIVERS

ROW 1,5 ROW 3,7 CORE MATRIX ENABLE

USER-PROVIDED OPTIONAL ADD-ONS
SEE CORE64 HACKER GUIDE

CM DRIVER IO EXPANDER

RASPBERRY PI PICO (PART 1 OF 2) See Core64 User Manual for more
TP5 BOOTSEL TP6 GNDD
TP4 GPIO25/LED
TP3 GPIO/SMPS
TP2 USB_DP
TP1 USB_DM
D3 GND
D2 SWDIO
SWCLK D1 GND

OLED ON
THIS SIDE OF HEADER

4 SDA 5 SCL 6 ~{WC}7 VCC

than 0x07 and less than 0x78 (120).

AMBIENT LIGHT SENSOR
HALL SENSOR 1 HALL SENSOR 2 HALL SENSOR 3 HALL SENSOR 4 EEPROM (BOARD ID)

AMBIENT PROX. SENSOR OLED

Id: 1/1 Title: Core64c Logic Board - Raspberry Pi Pico W RP2040

AND!XOR IO Exp. MCP23017 AND!XOR EEPROM AT24C32r NFC CLICK PN7120

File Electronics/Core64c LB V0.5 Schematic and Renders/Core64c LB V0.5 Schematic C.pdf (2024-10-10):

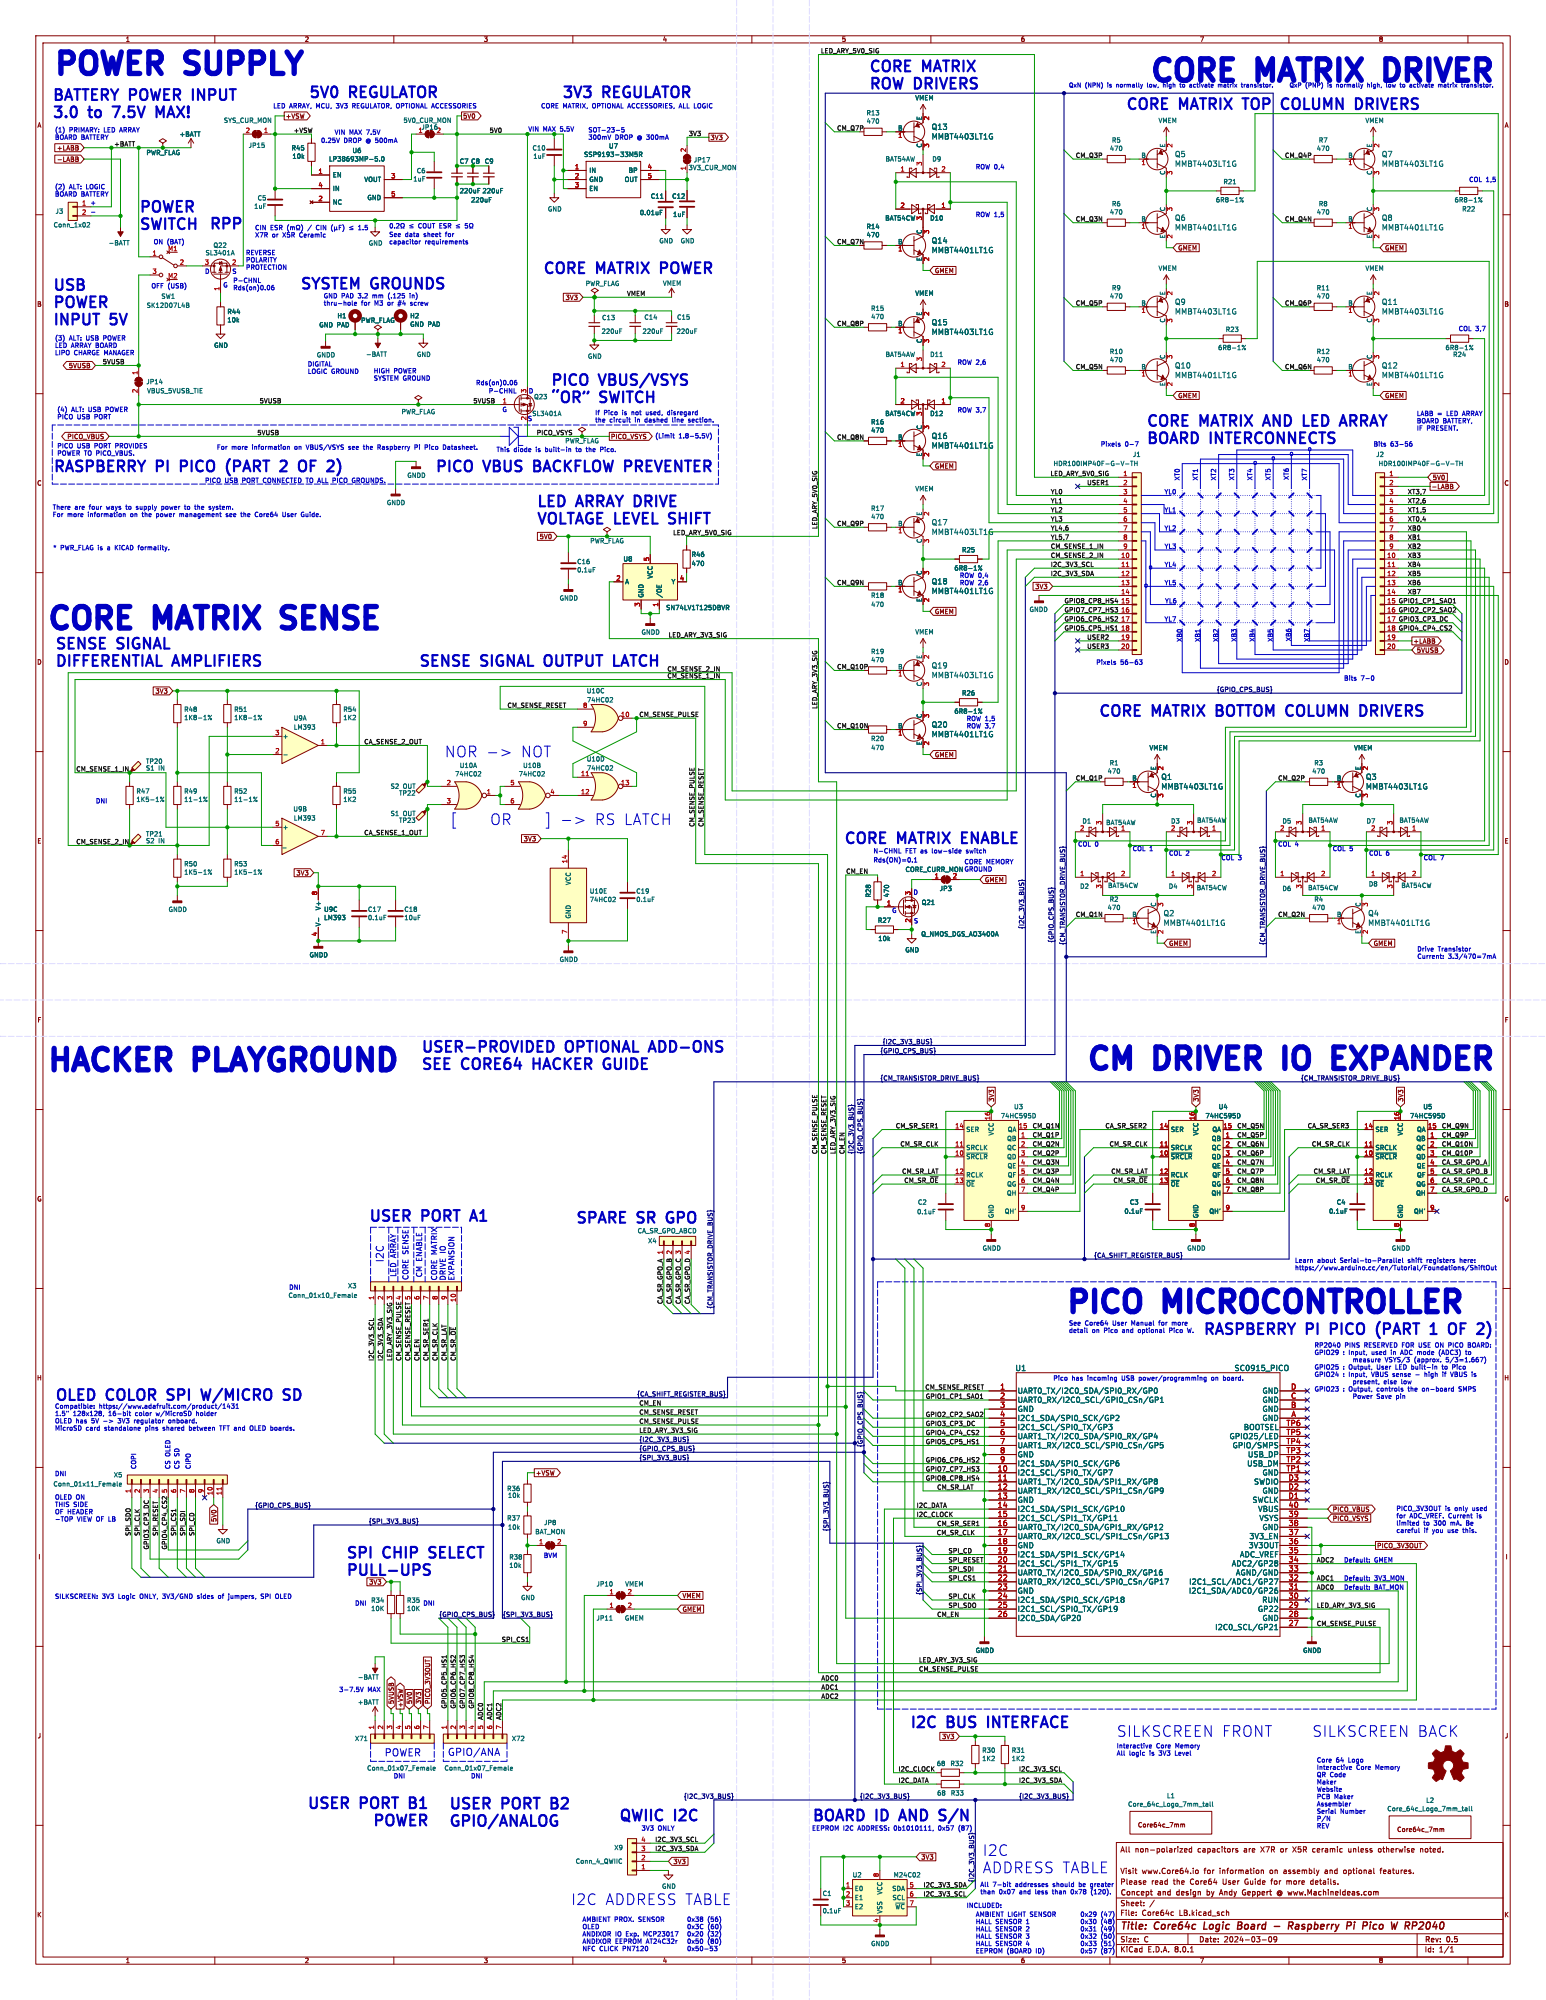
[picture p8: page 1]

LED ARRAY, MCU, 3V3 REGULATOR, OPTIONAL ACCESSORIES
+VSW

CORE MATRIX, OPTIONAL ACCESSORIES, ALL LOGIC

CORE MATRIX TOP COLUMN DRIVERS

ROW 1,5 SENSE SIGNAL OUTPUT LATCH

CIN ESR þÿ(m©) / CIN þÿ(¼F) þÿ"d1.5 X7R or X5R Ceramic

þÿ0.2©þÿ"dCOUT ESR þÿ"dþÿ5©

ROW 1,5 ROW 3,7 SYSTEM GROUNDS

GND PAD 3.2 mm (.125 in)

If Pico is not used, disregard

PICO_VBUS
* PWR_FLAG is a KiCAD formality. PICO USB PORT PROVIDES
POWER TO PICO_VBUS. SENSE SIGNAL

PICO VBUS BACKFLOW PREVENTER

LED_ARY_5V0_SIG
CORE MATRIX SENSE COPI

CORE MATRIX BOTTOM COLUMN DRIVERS

See Core64 User Manual for more
SPI_CLK GPIO1_CP1_SAO1

3V3 ONLY OLED COLOR SPI W/MICRO SD

OLED ON
THIS SIDE OF HEADER

4 SDA 5 SCL 6 ~{WC}7 VCC

than 0x07 and less than 0x78 (120).

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

AMBIENT PROX. SENSOR OLED

Id: 1/1 Title: Core64c Logic Board - Raspberry Pi Pico W RP2040

AND!XOR IO Exp. MCP23017 AND!XOR EEPROM AT24C32r NFC CLICK PN7120

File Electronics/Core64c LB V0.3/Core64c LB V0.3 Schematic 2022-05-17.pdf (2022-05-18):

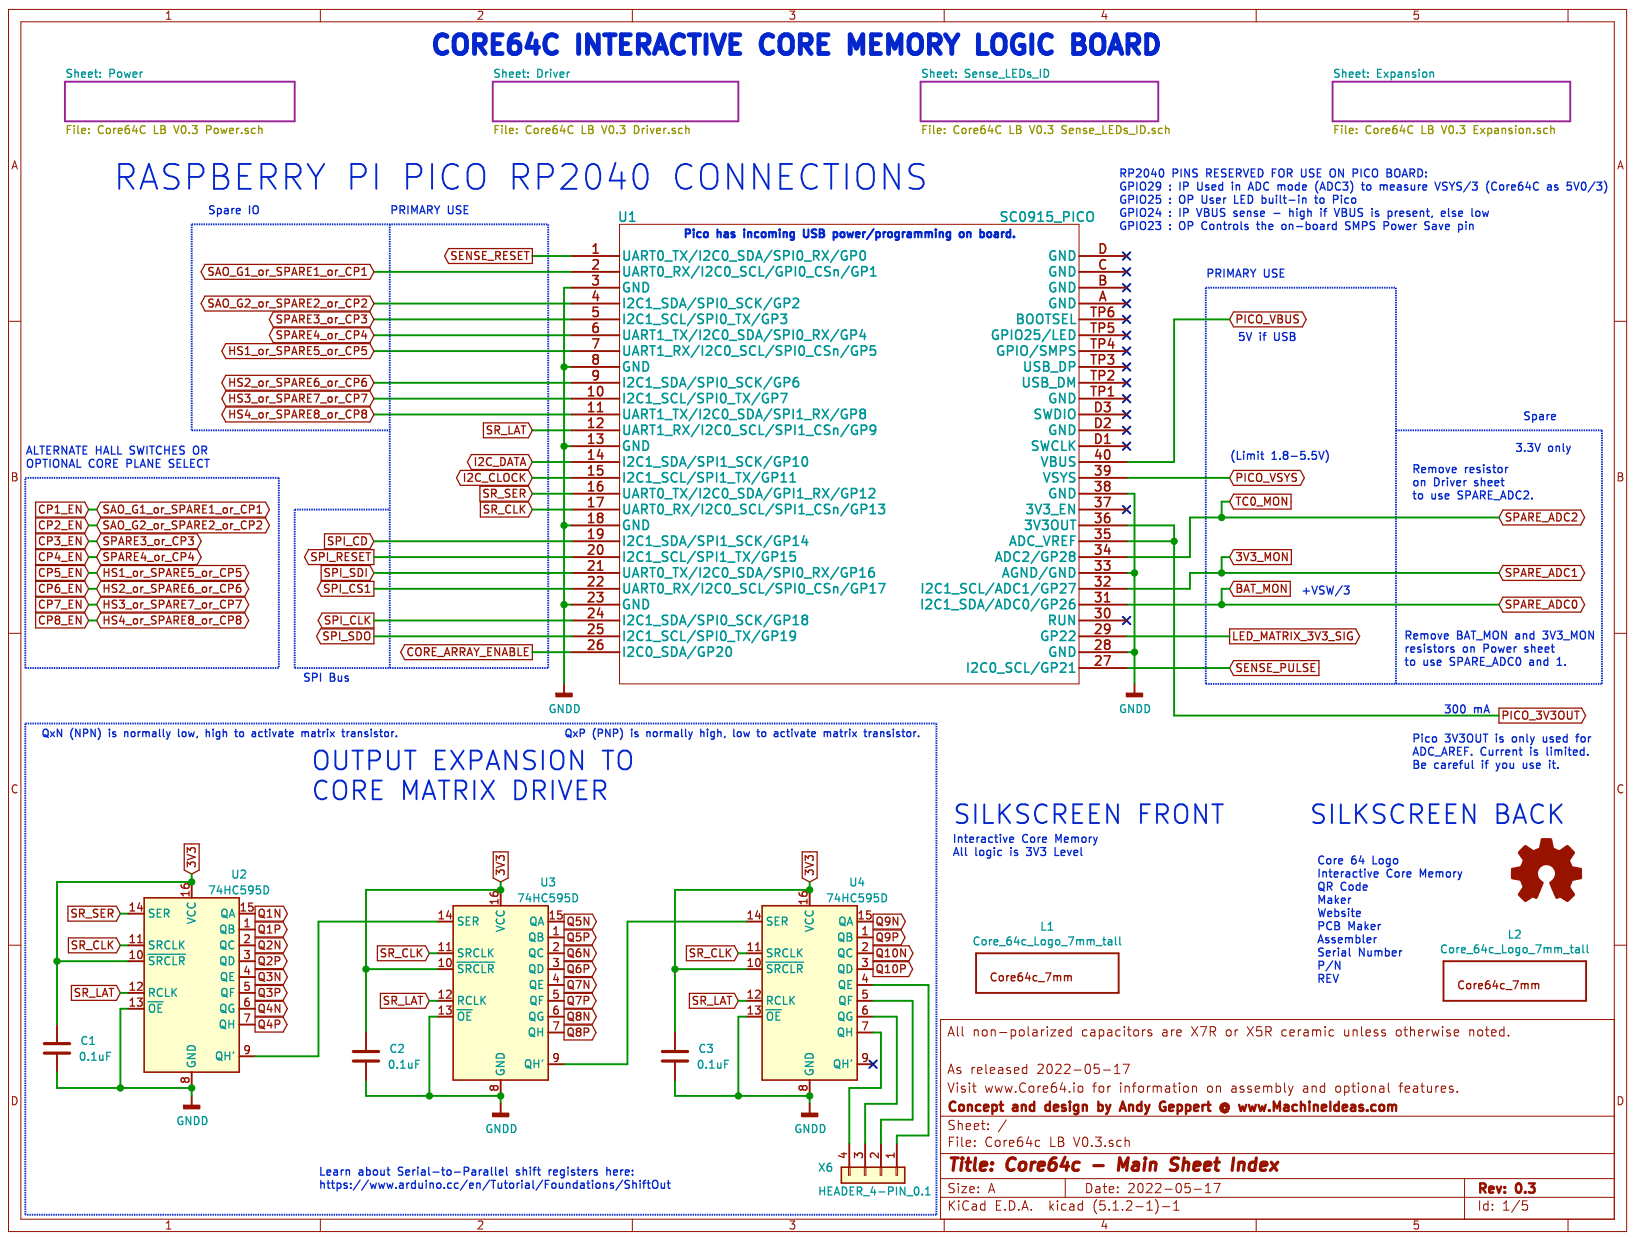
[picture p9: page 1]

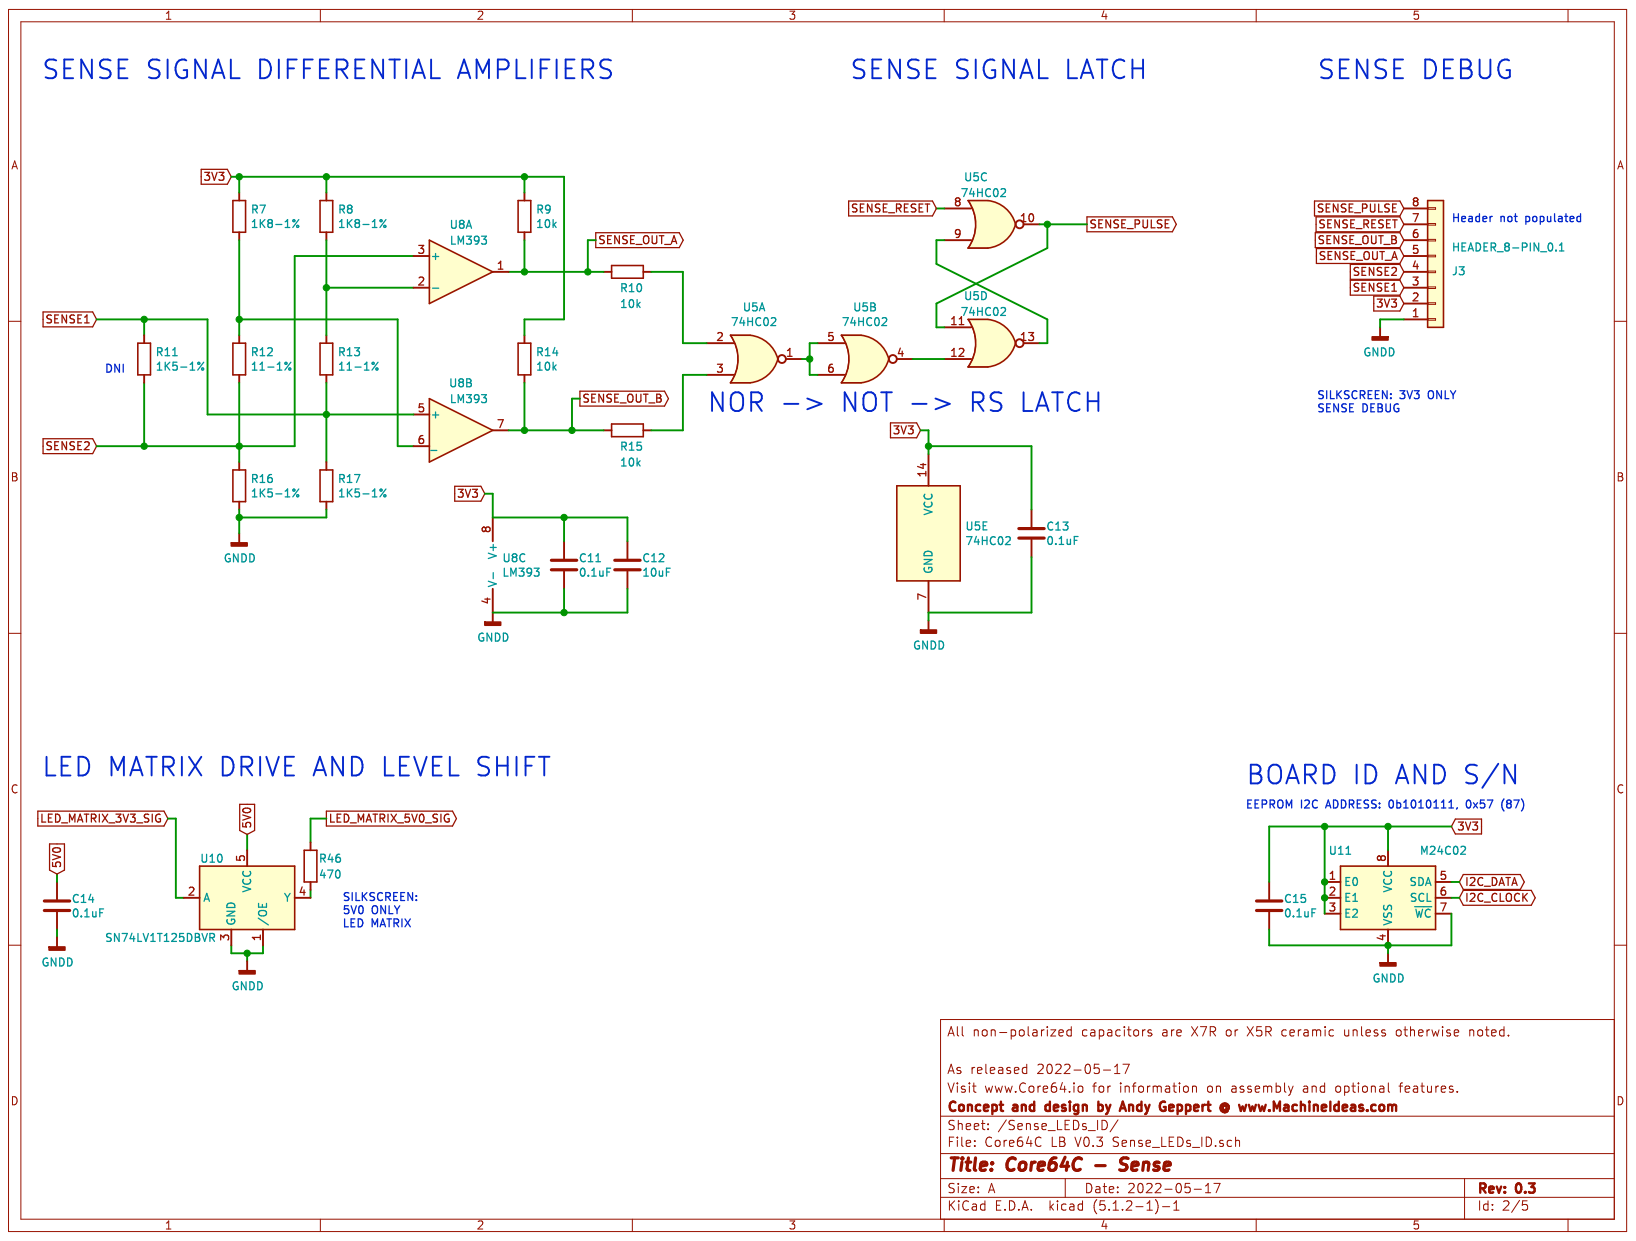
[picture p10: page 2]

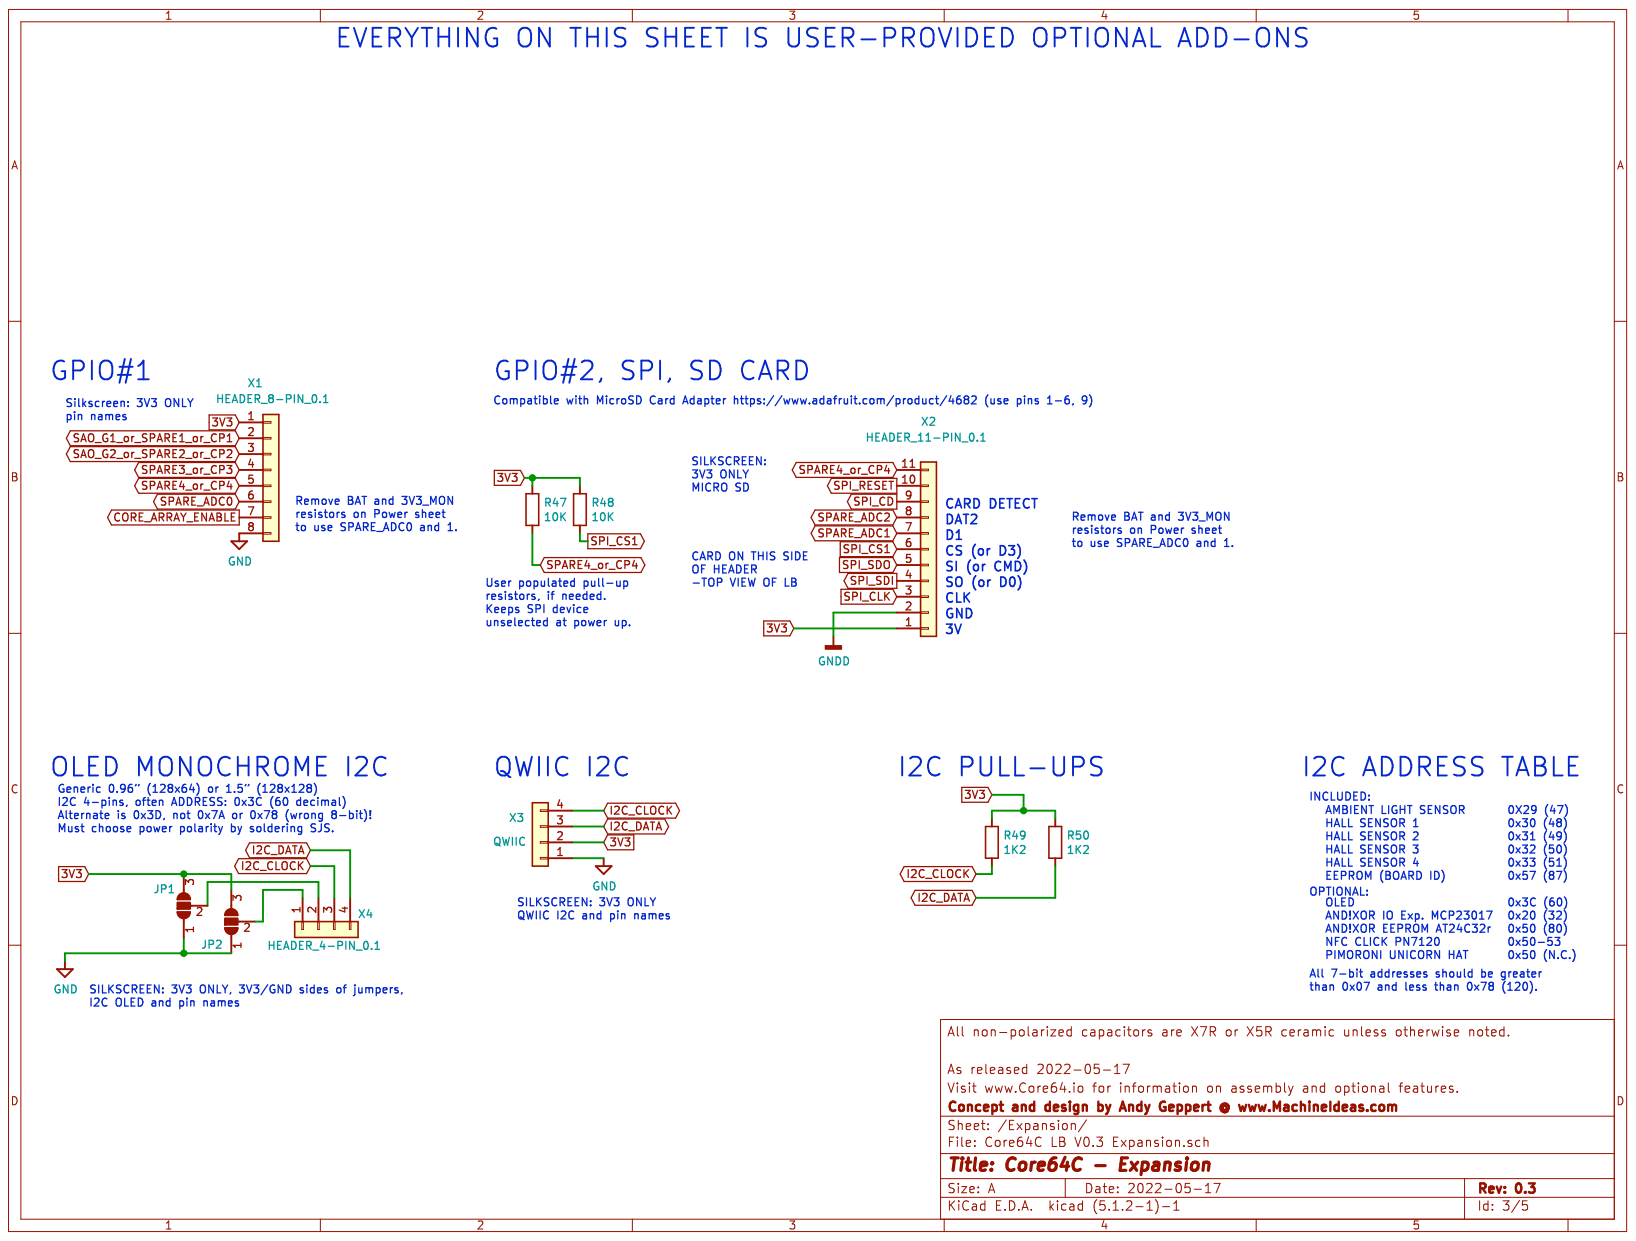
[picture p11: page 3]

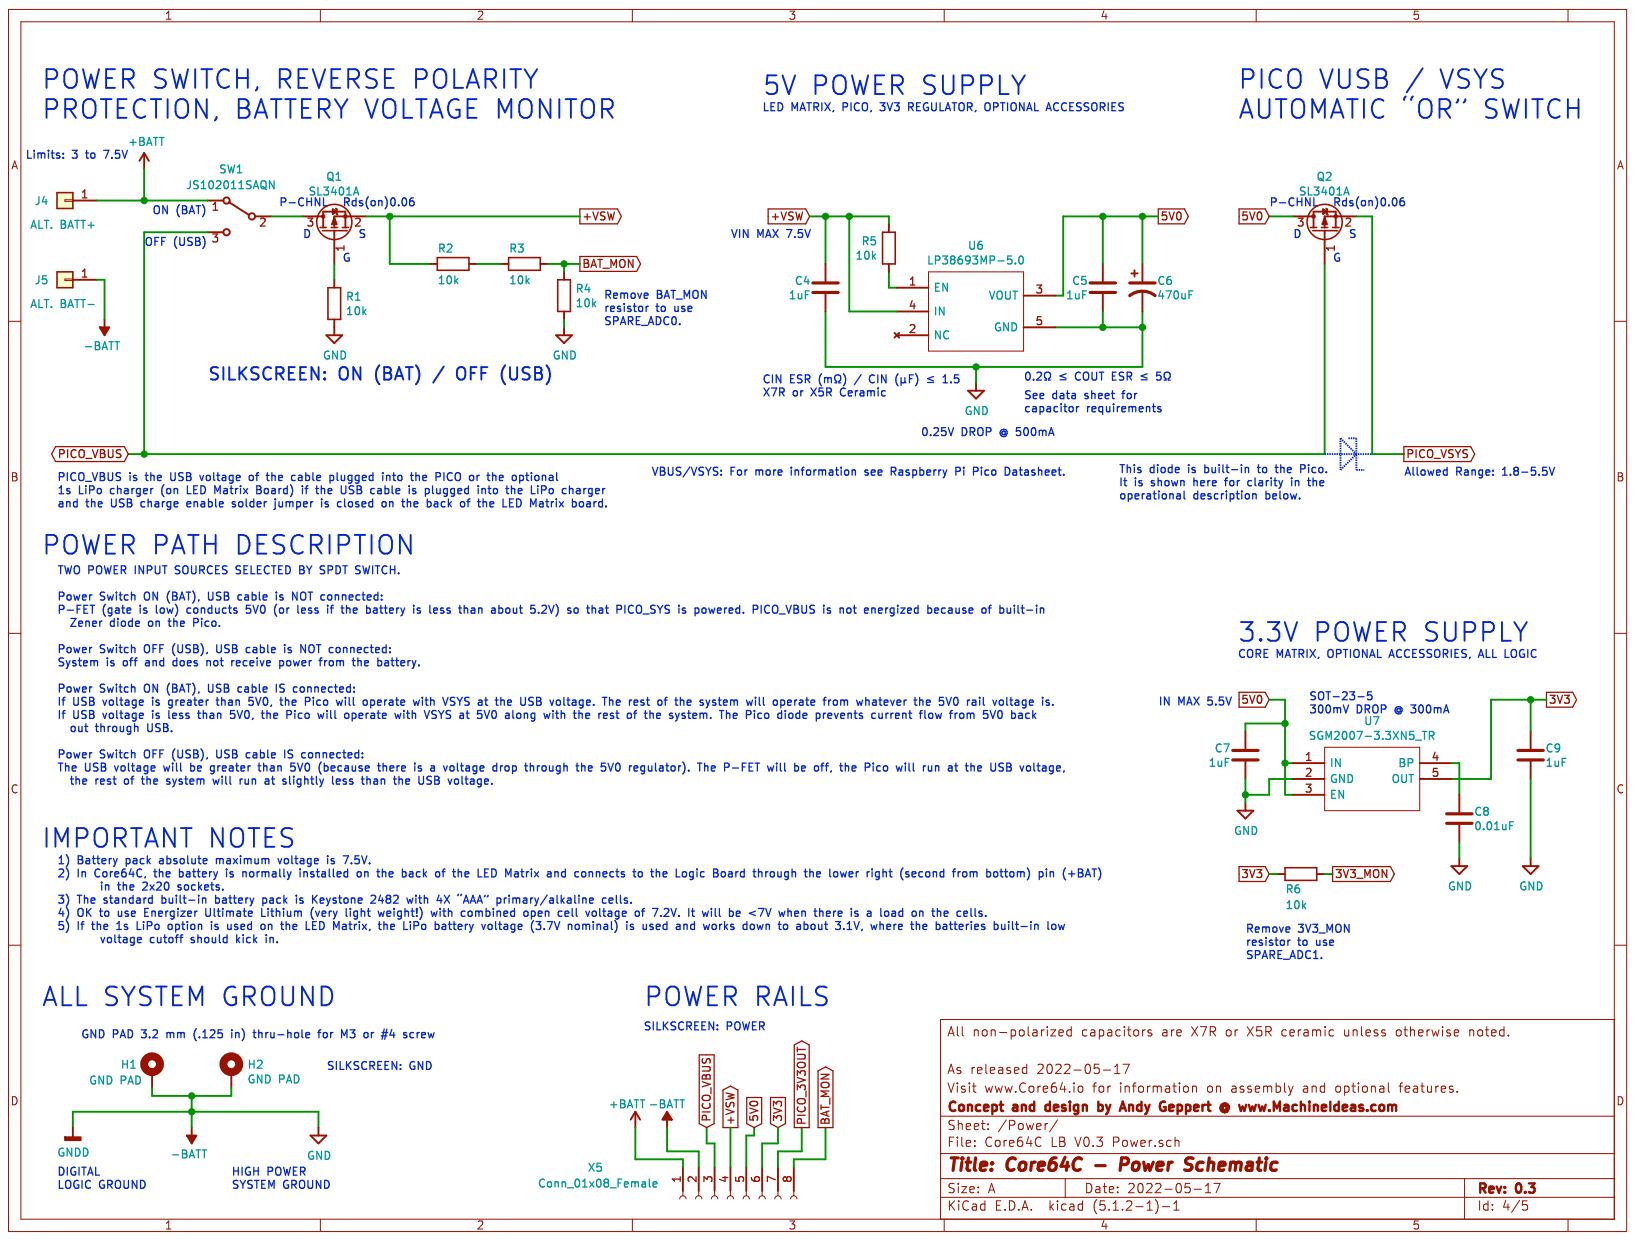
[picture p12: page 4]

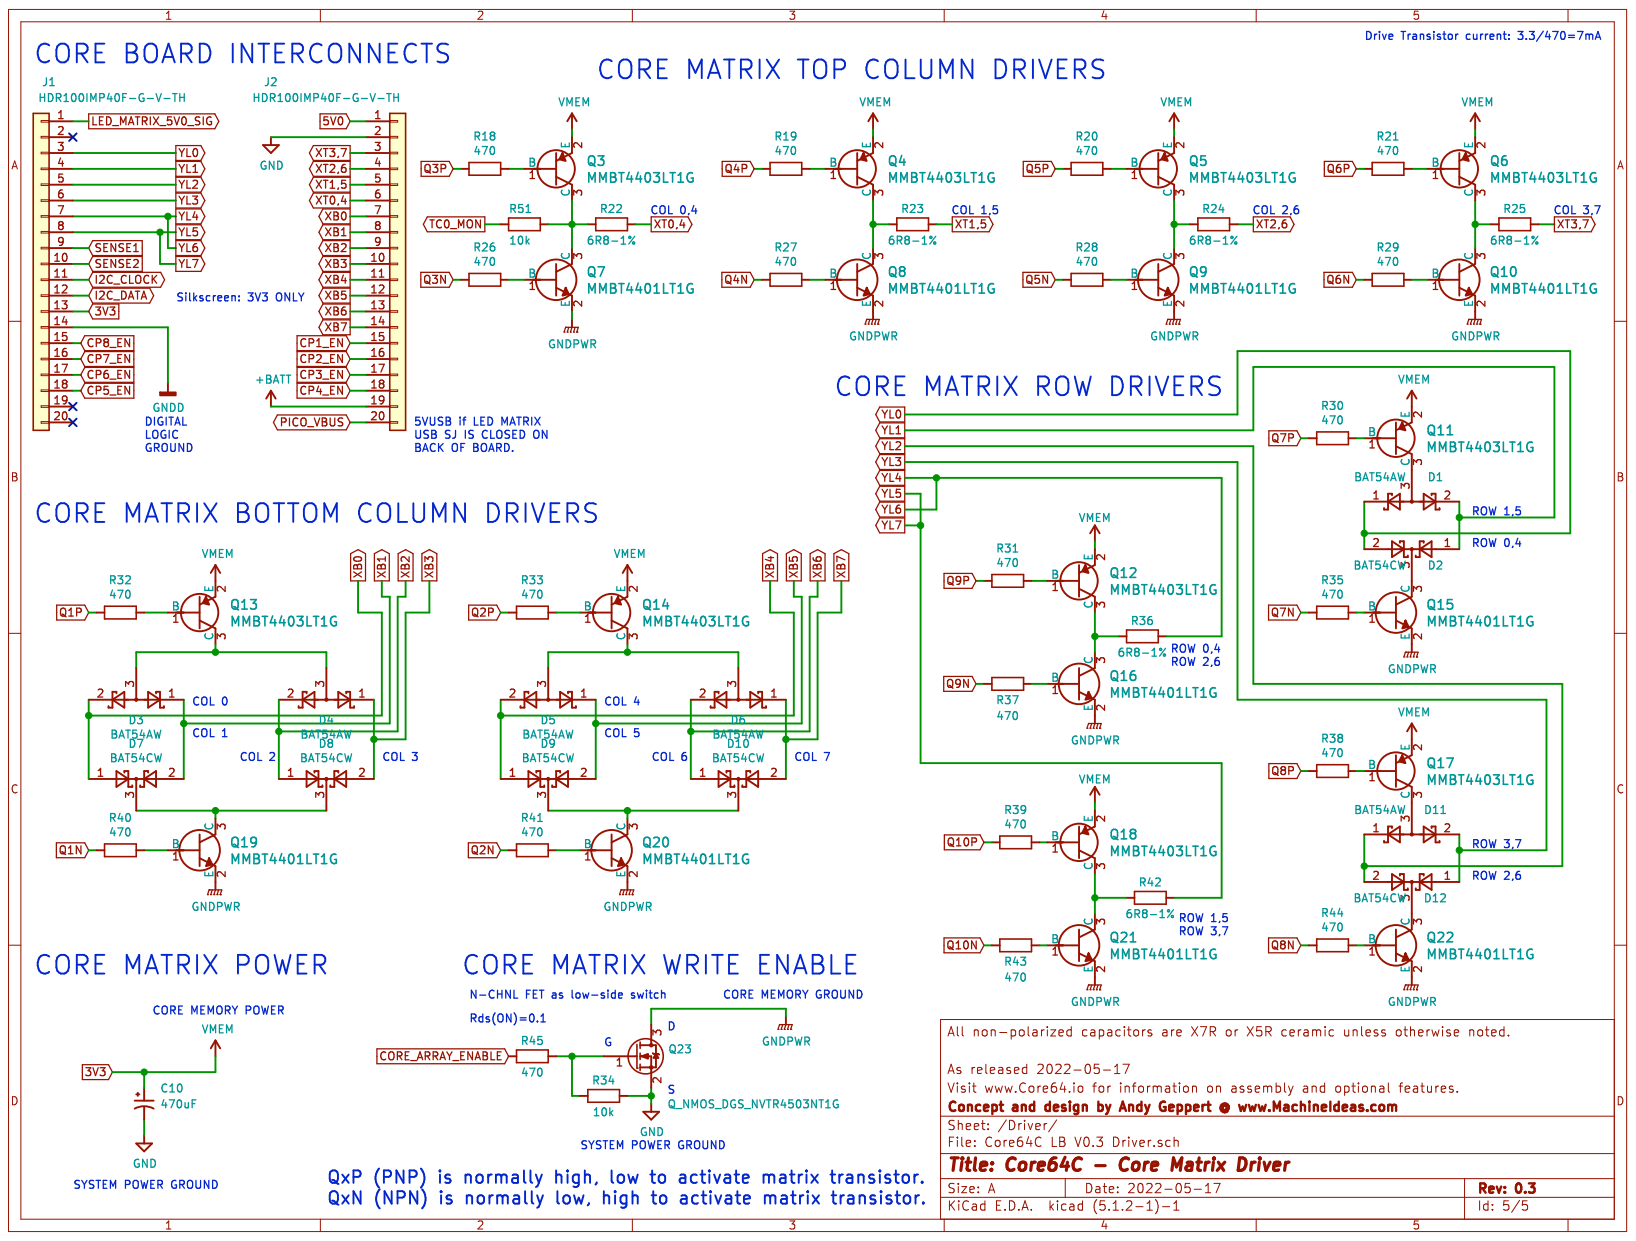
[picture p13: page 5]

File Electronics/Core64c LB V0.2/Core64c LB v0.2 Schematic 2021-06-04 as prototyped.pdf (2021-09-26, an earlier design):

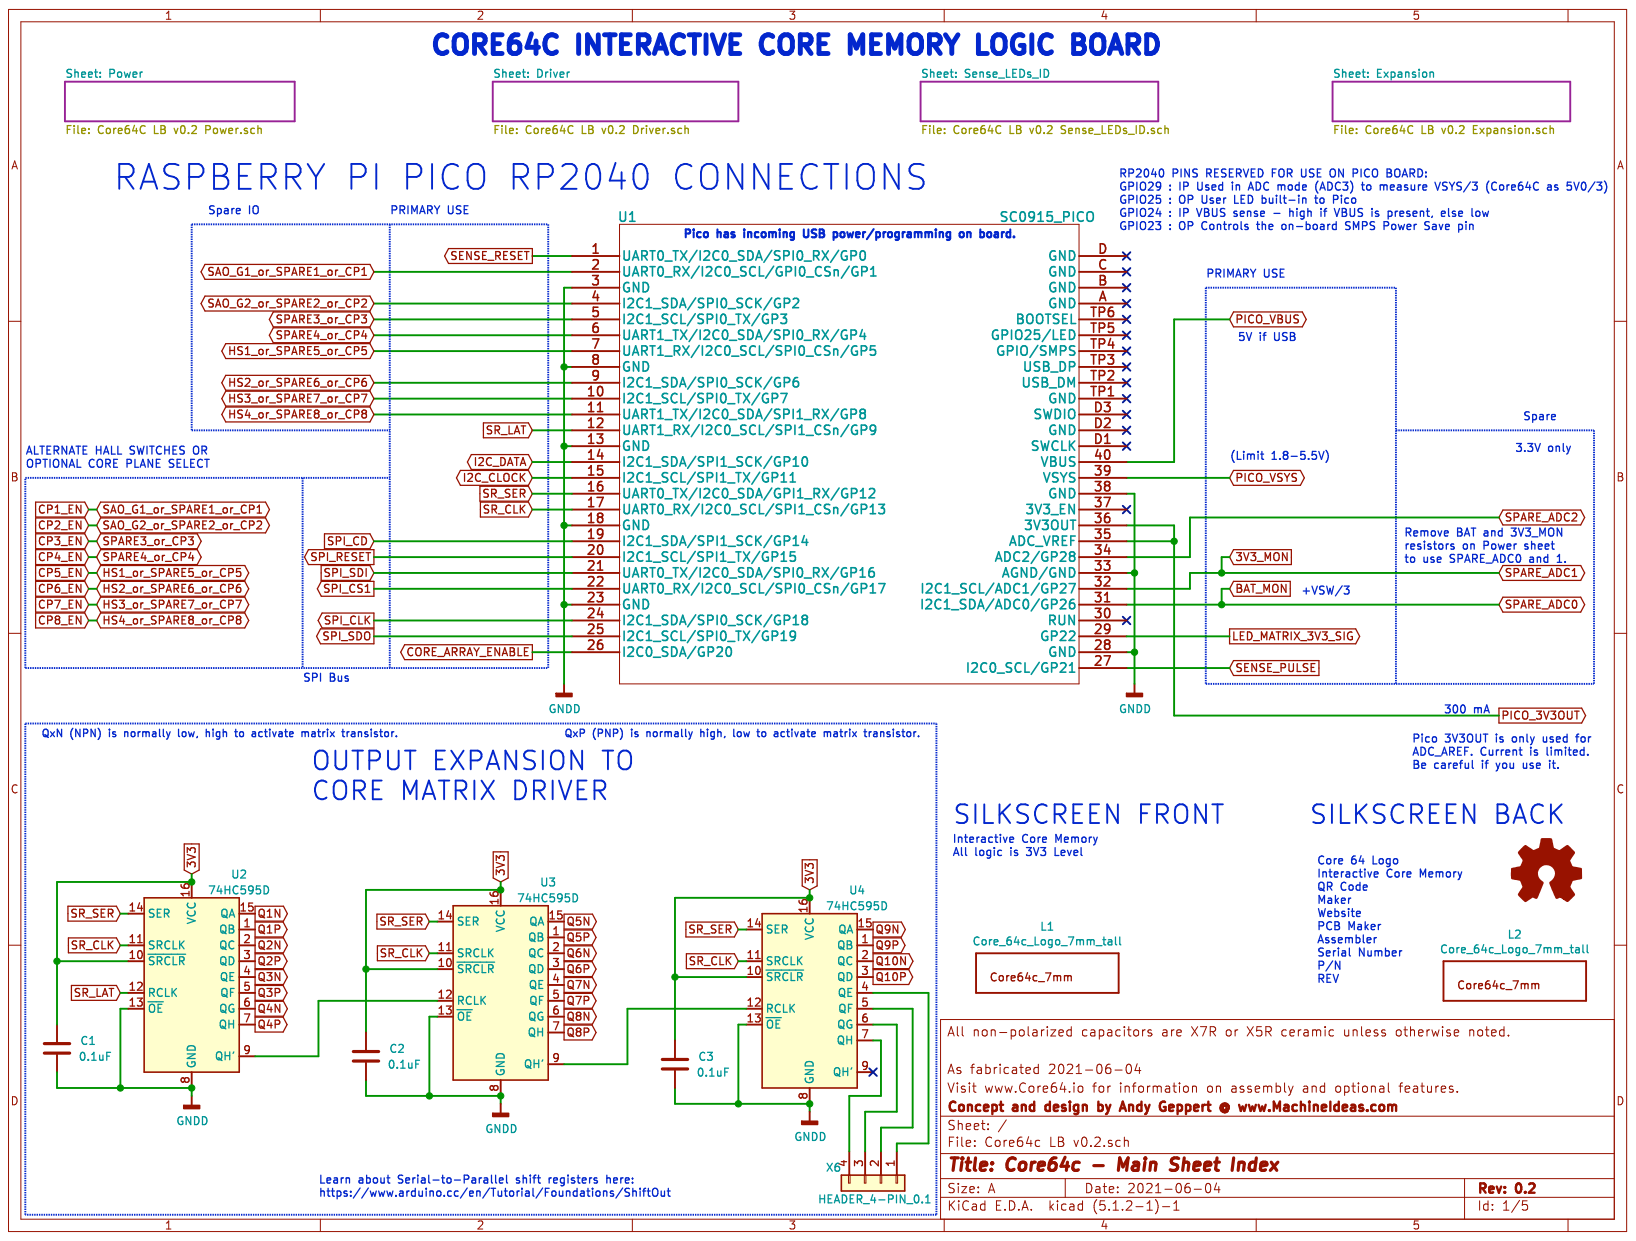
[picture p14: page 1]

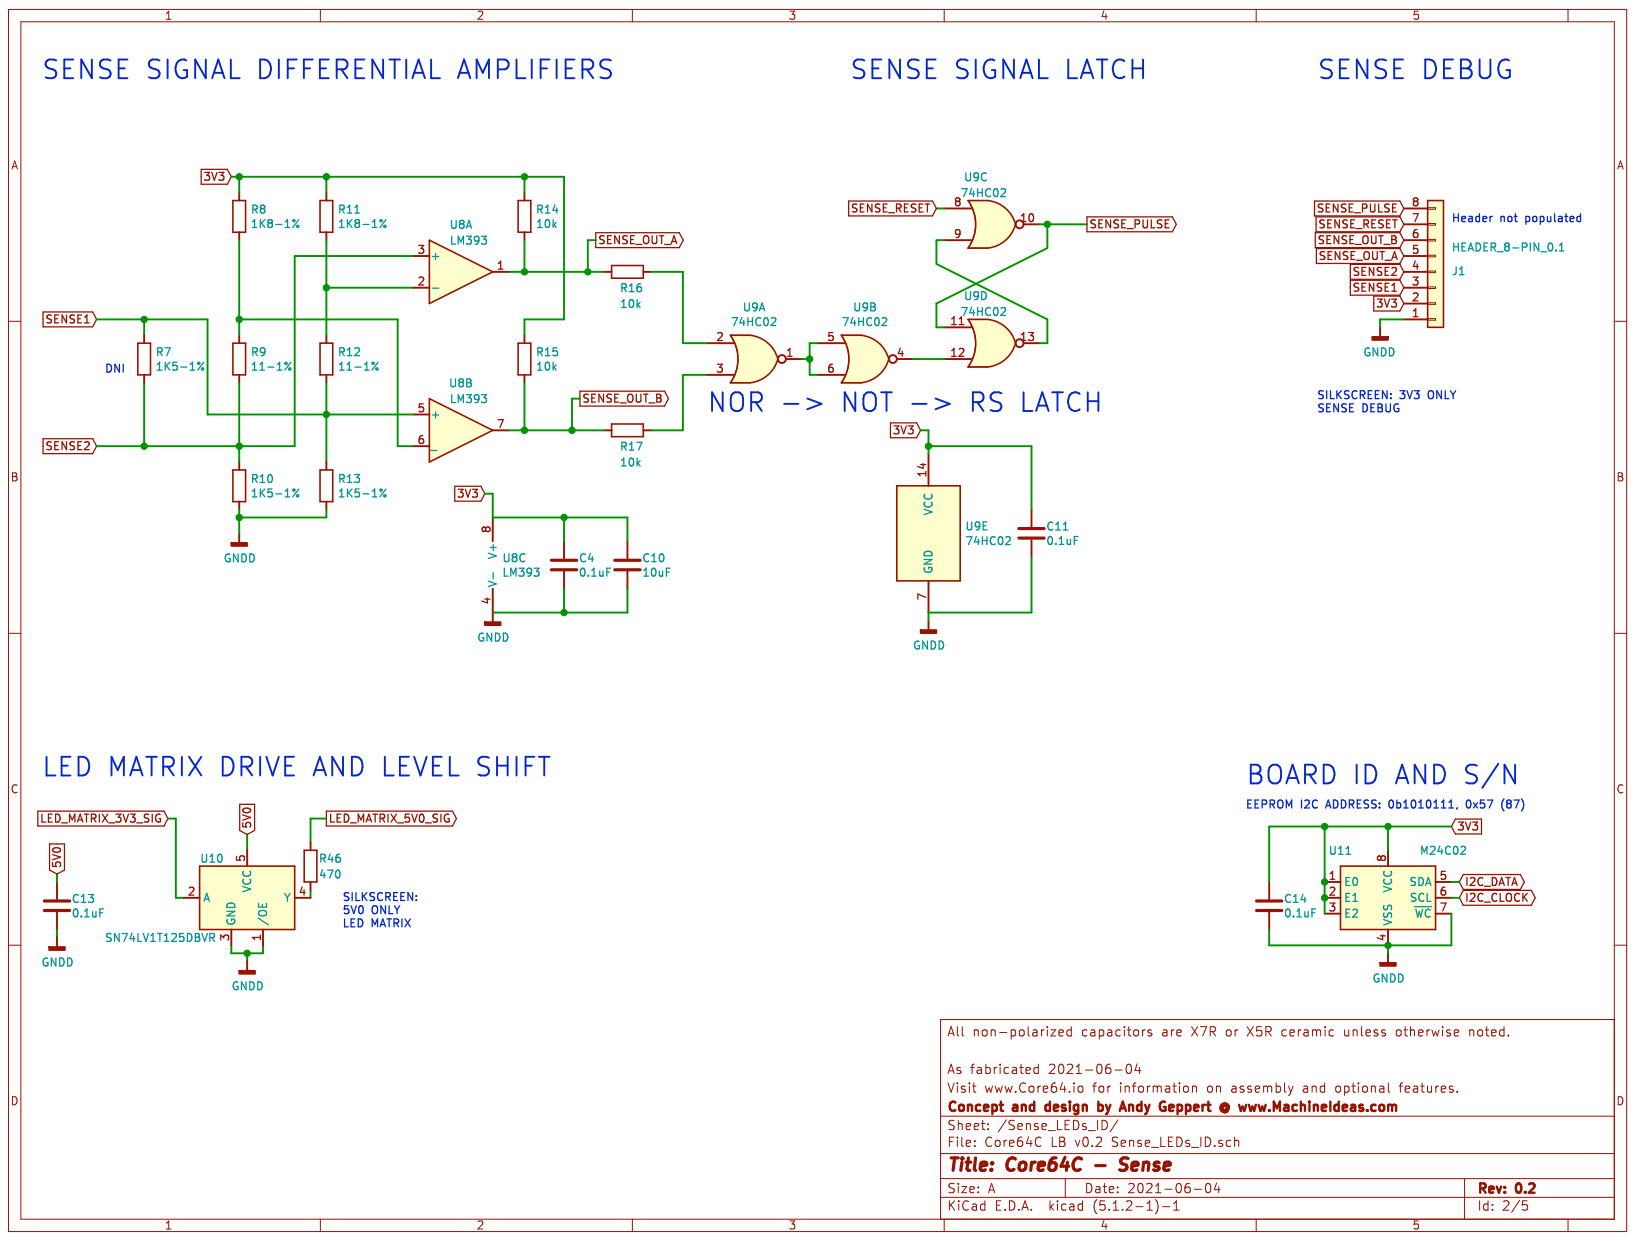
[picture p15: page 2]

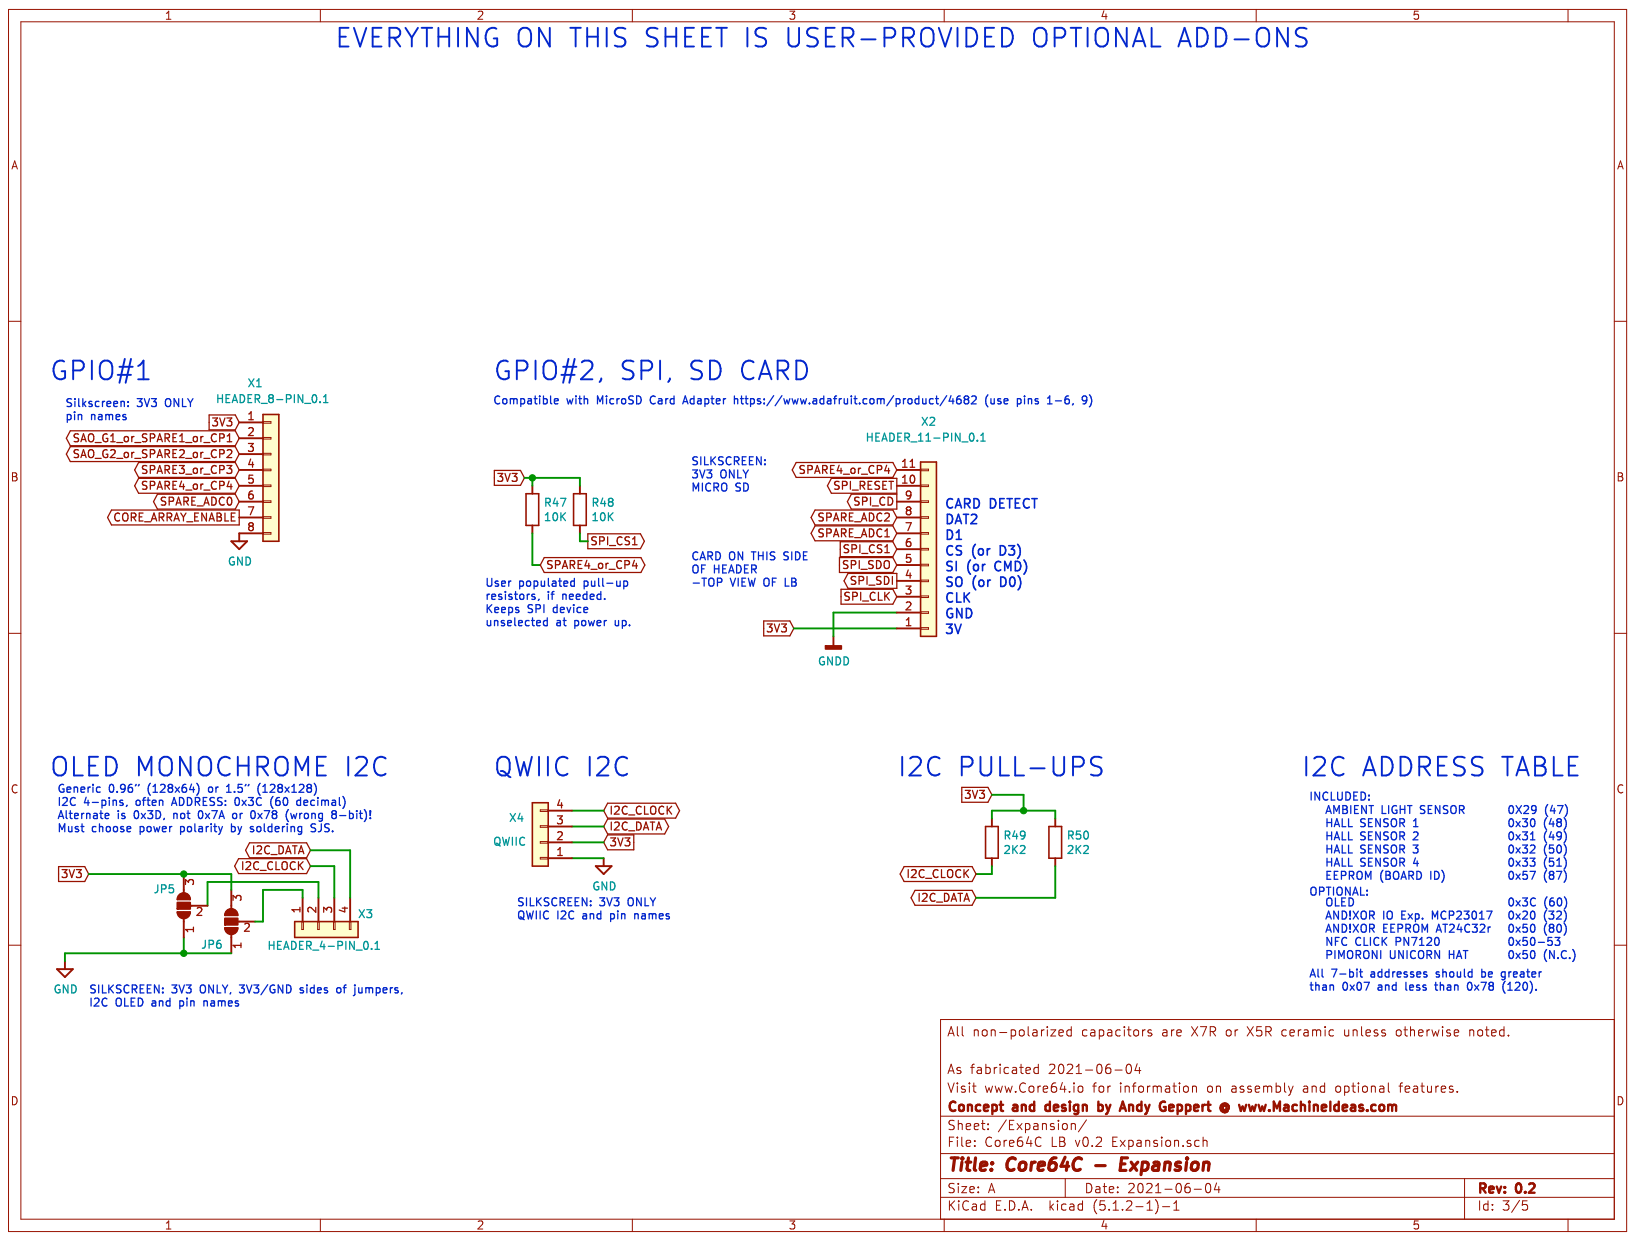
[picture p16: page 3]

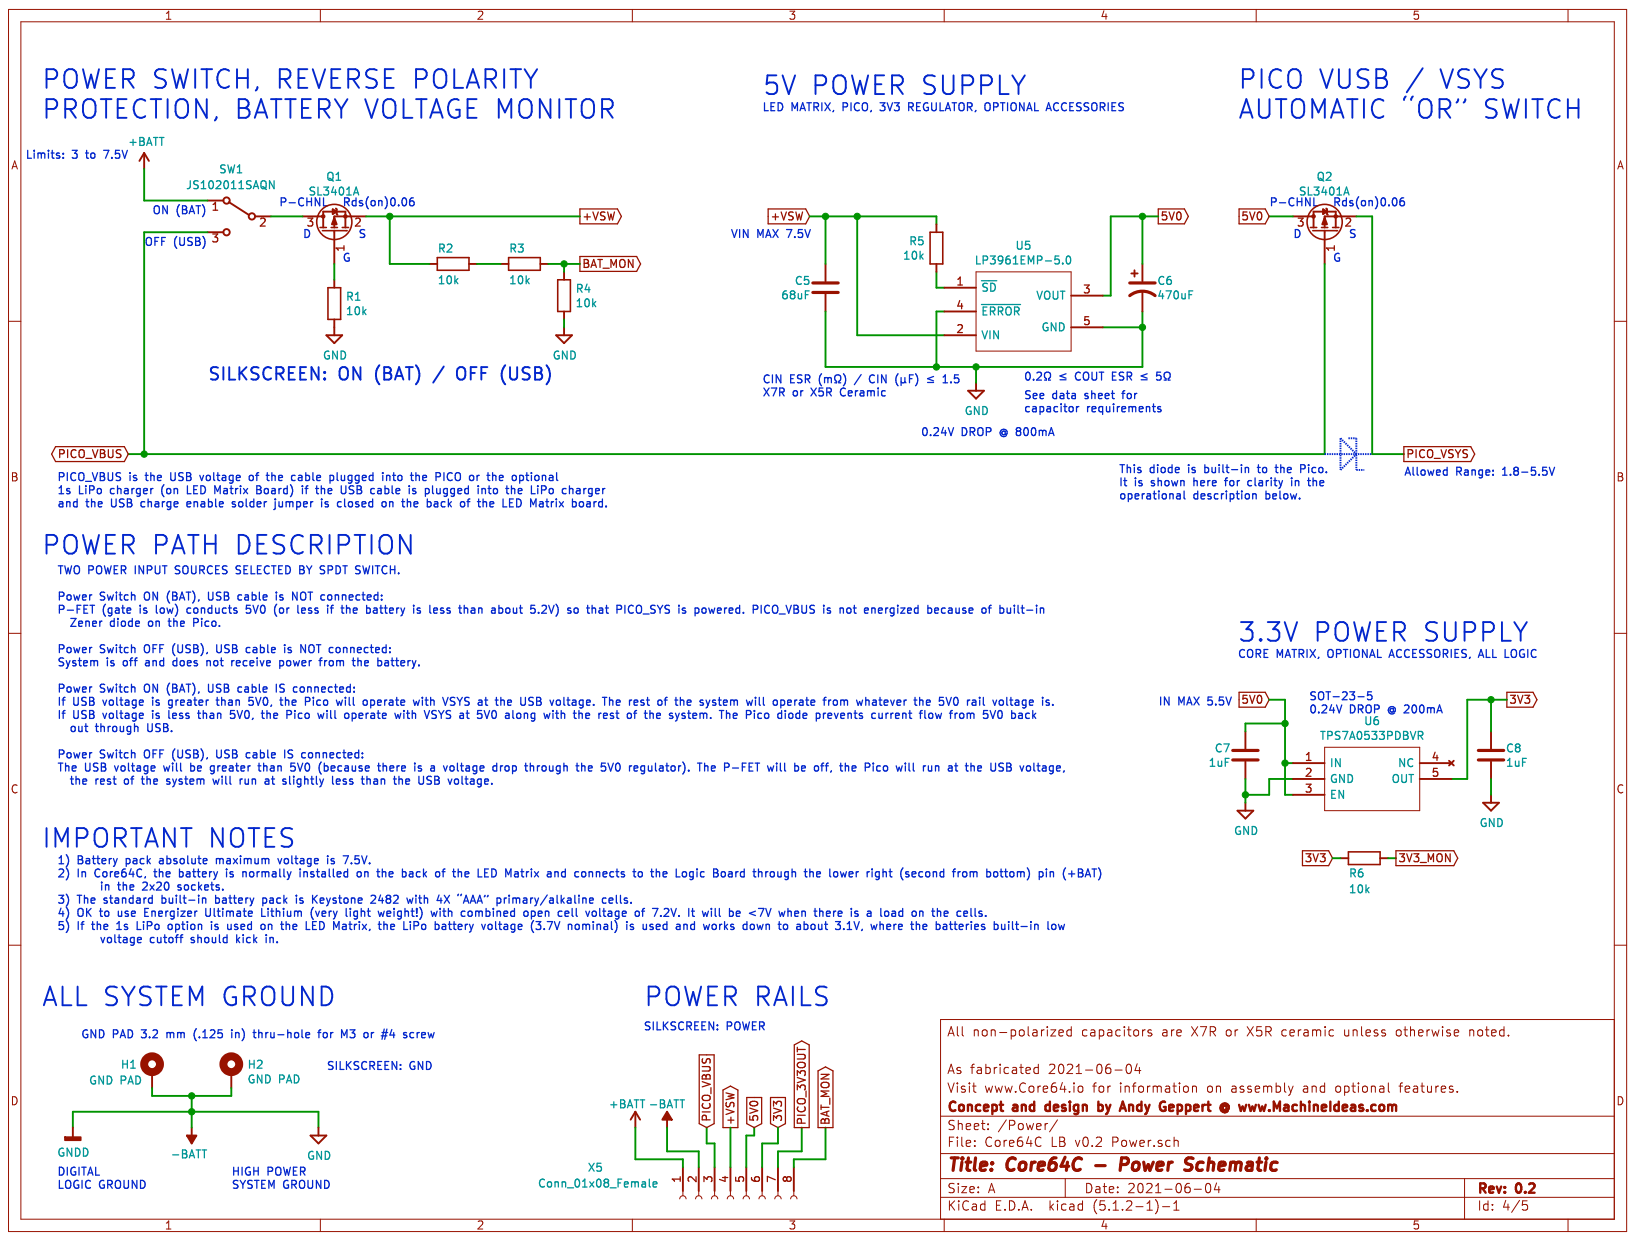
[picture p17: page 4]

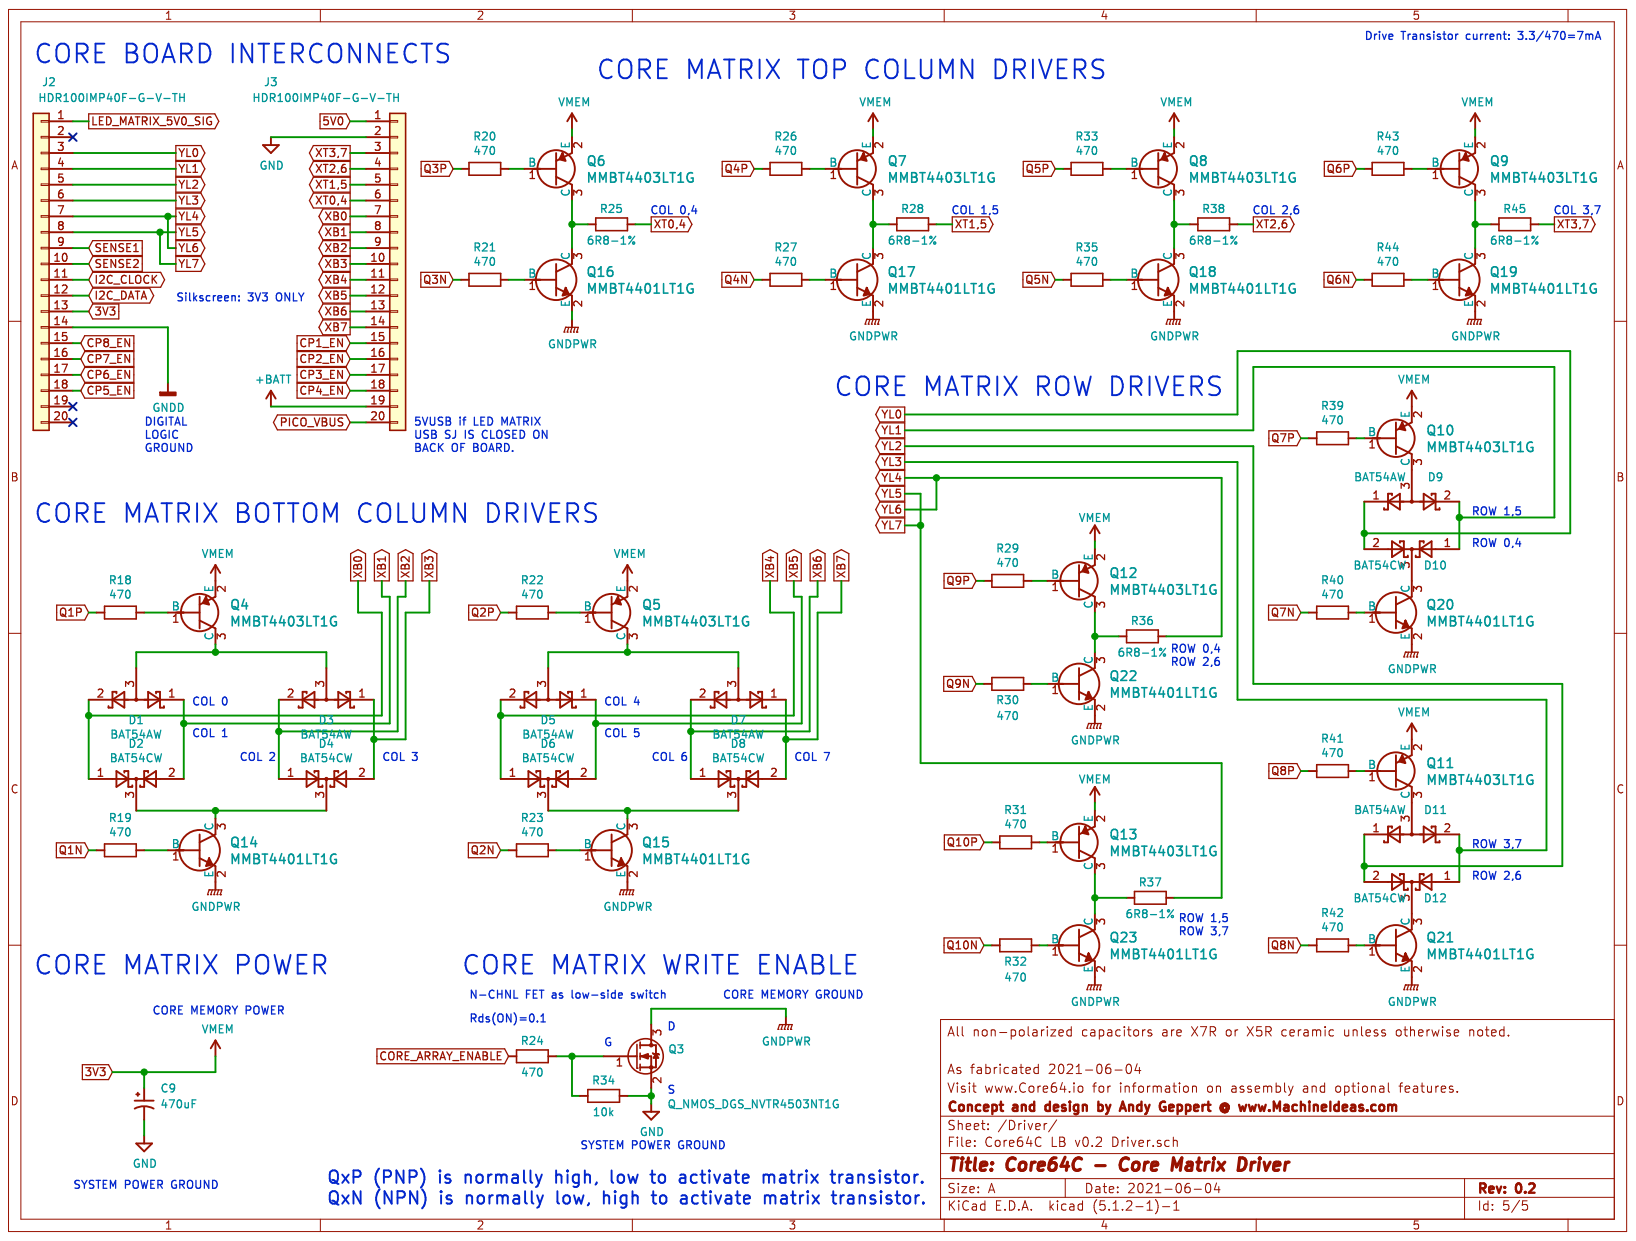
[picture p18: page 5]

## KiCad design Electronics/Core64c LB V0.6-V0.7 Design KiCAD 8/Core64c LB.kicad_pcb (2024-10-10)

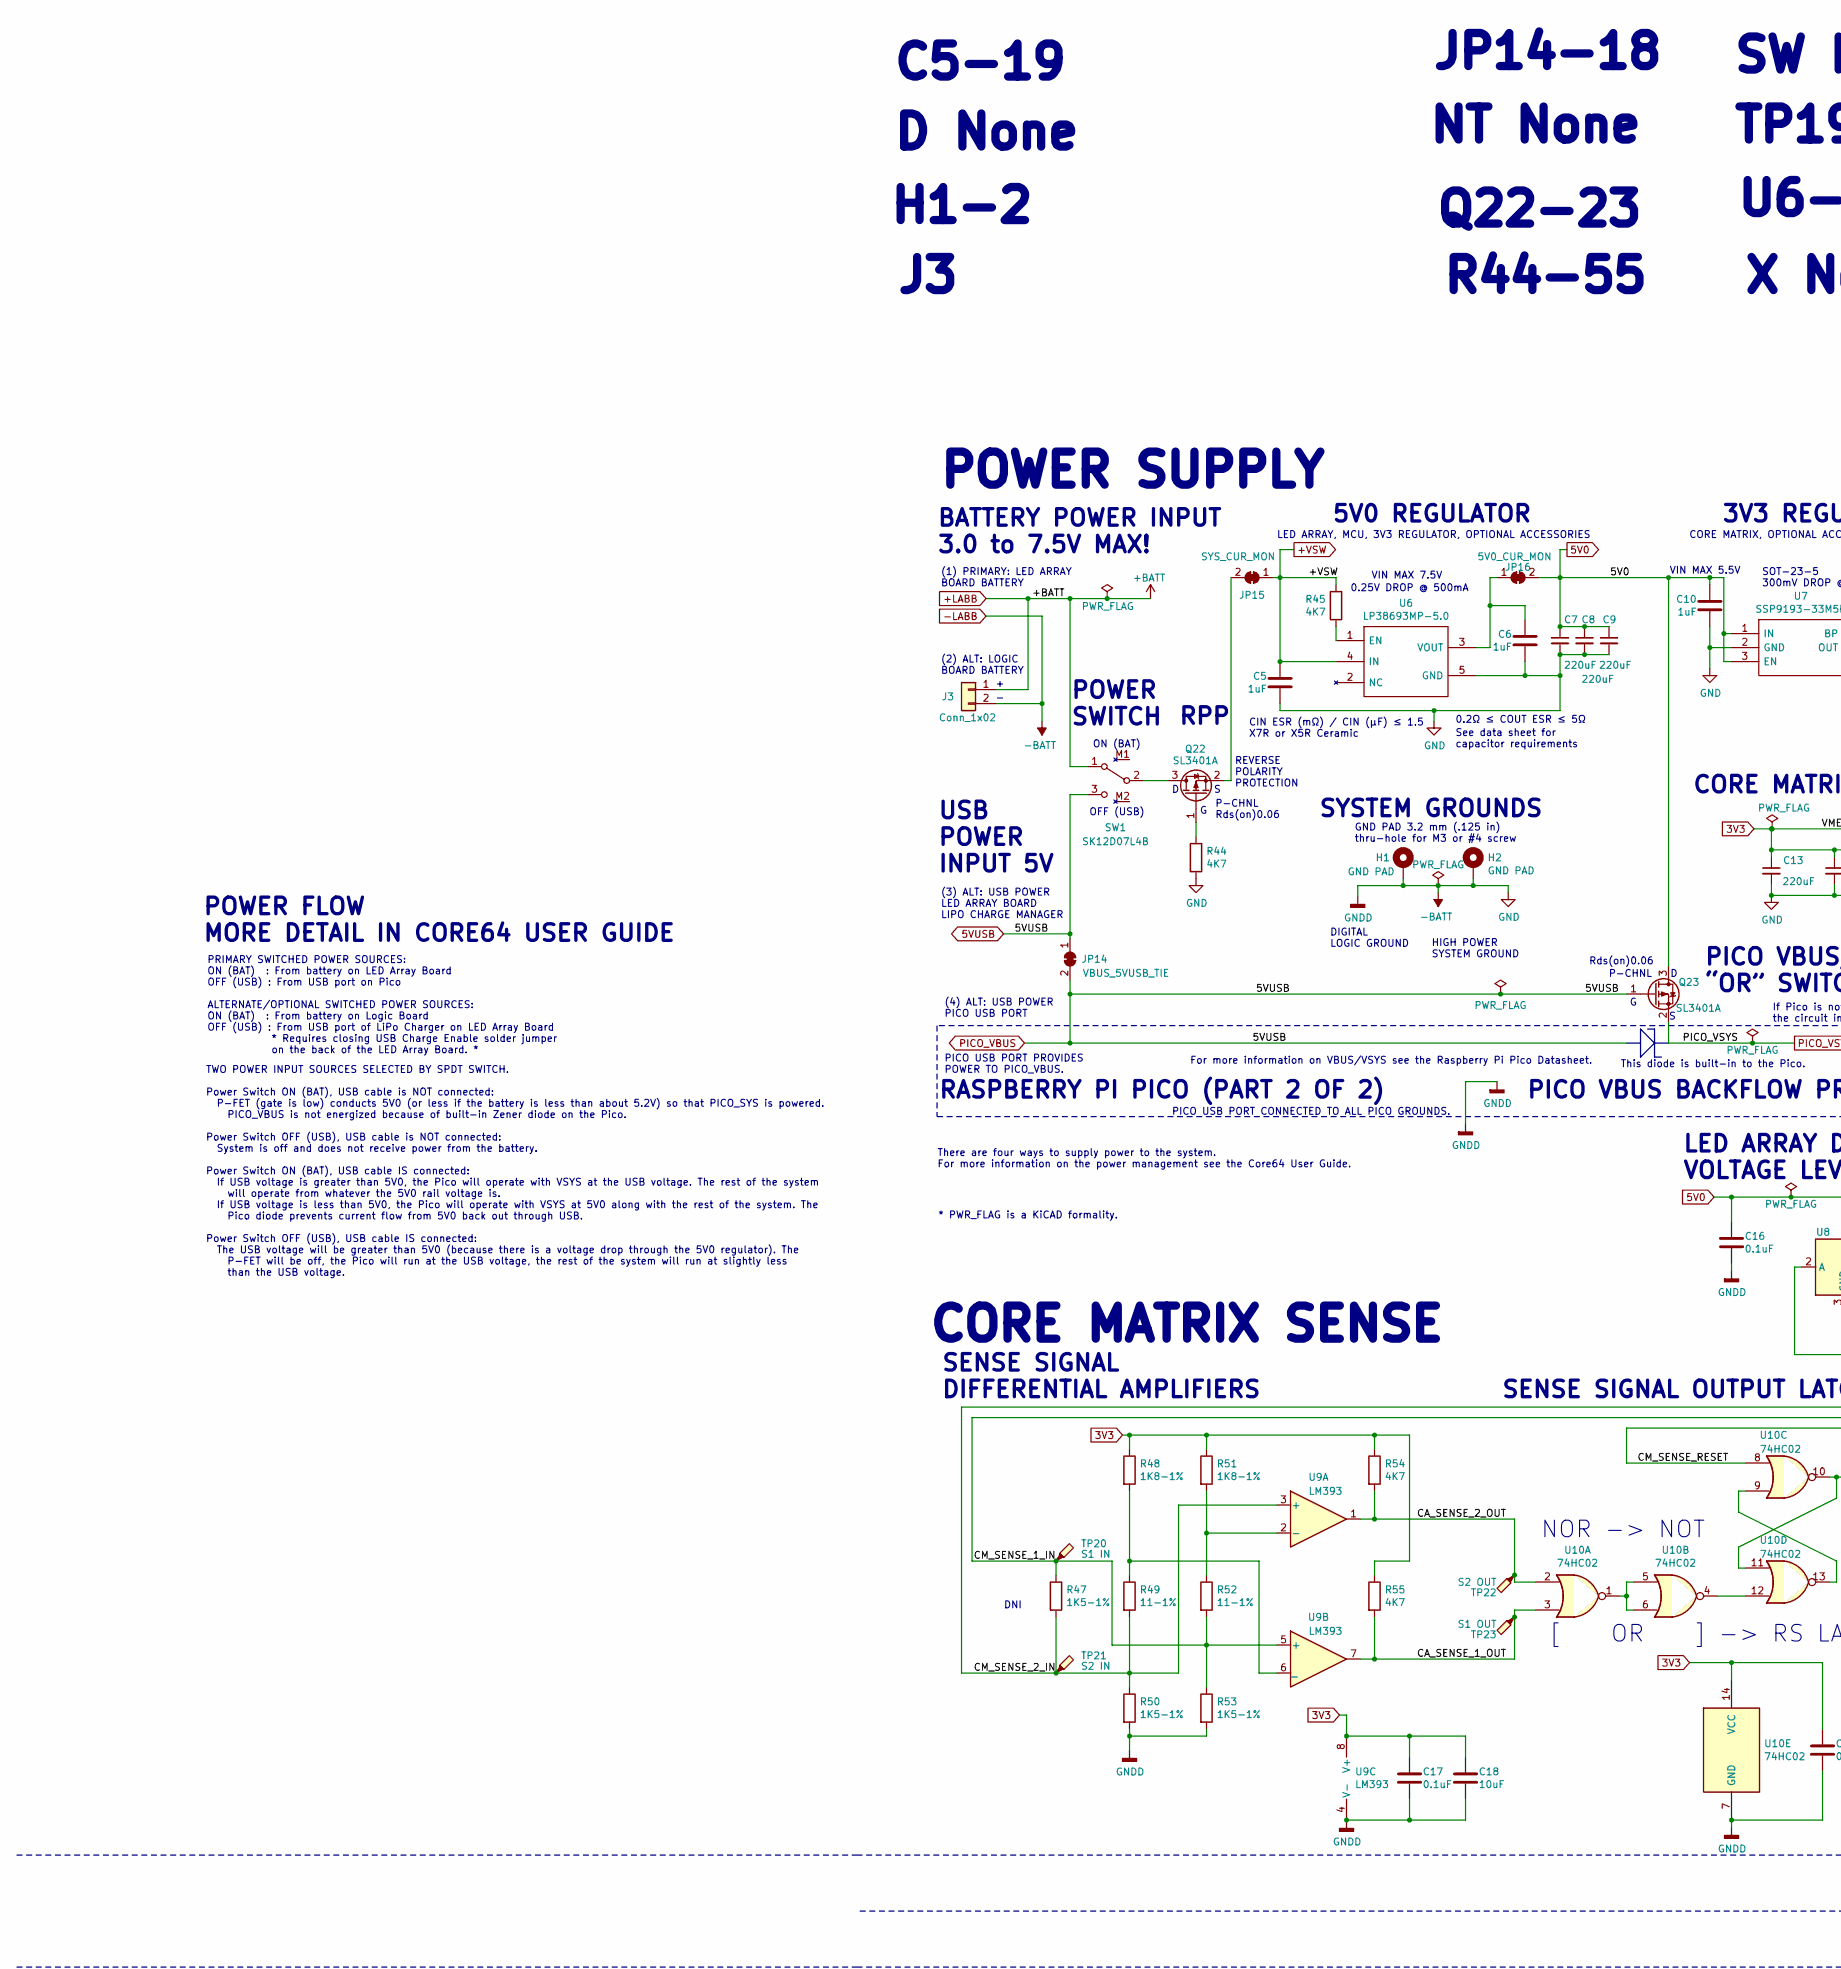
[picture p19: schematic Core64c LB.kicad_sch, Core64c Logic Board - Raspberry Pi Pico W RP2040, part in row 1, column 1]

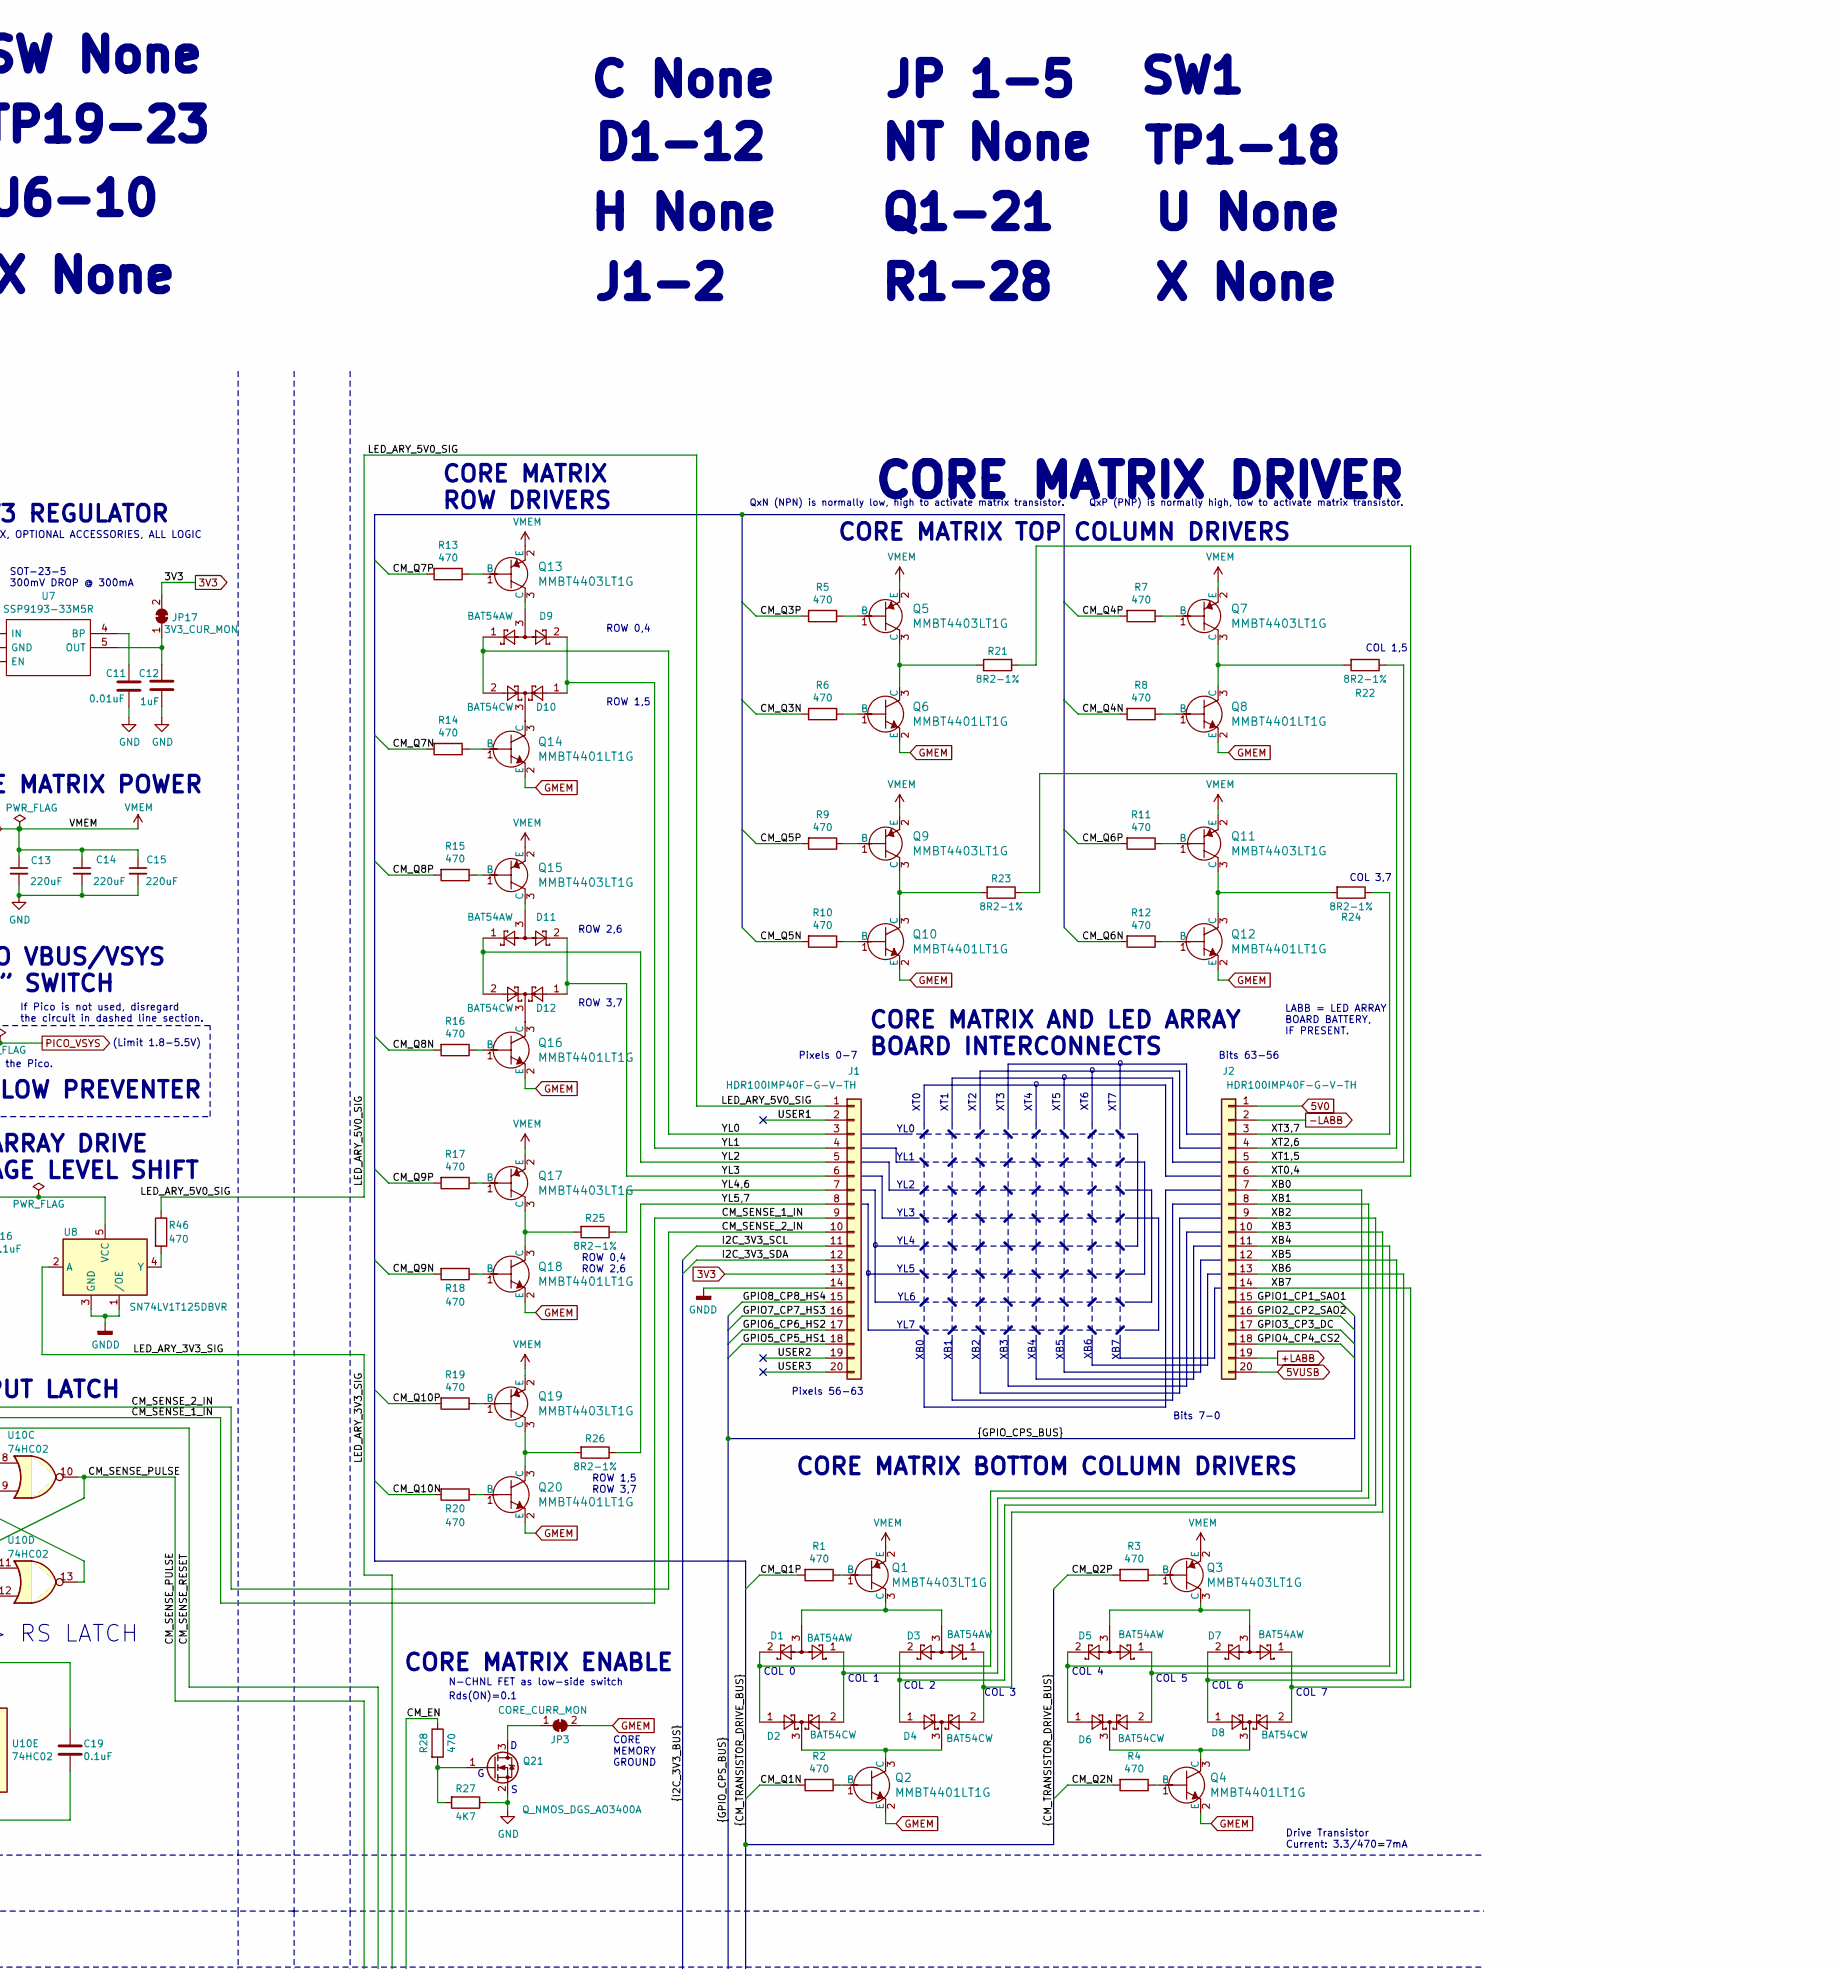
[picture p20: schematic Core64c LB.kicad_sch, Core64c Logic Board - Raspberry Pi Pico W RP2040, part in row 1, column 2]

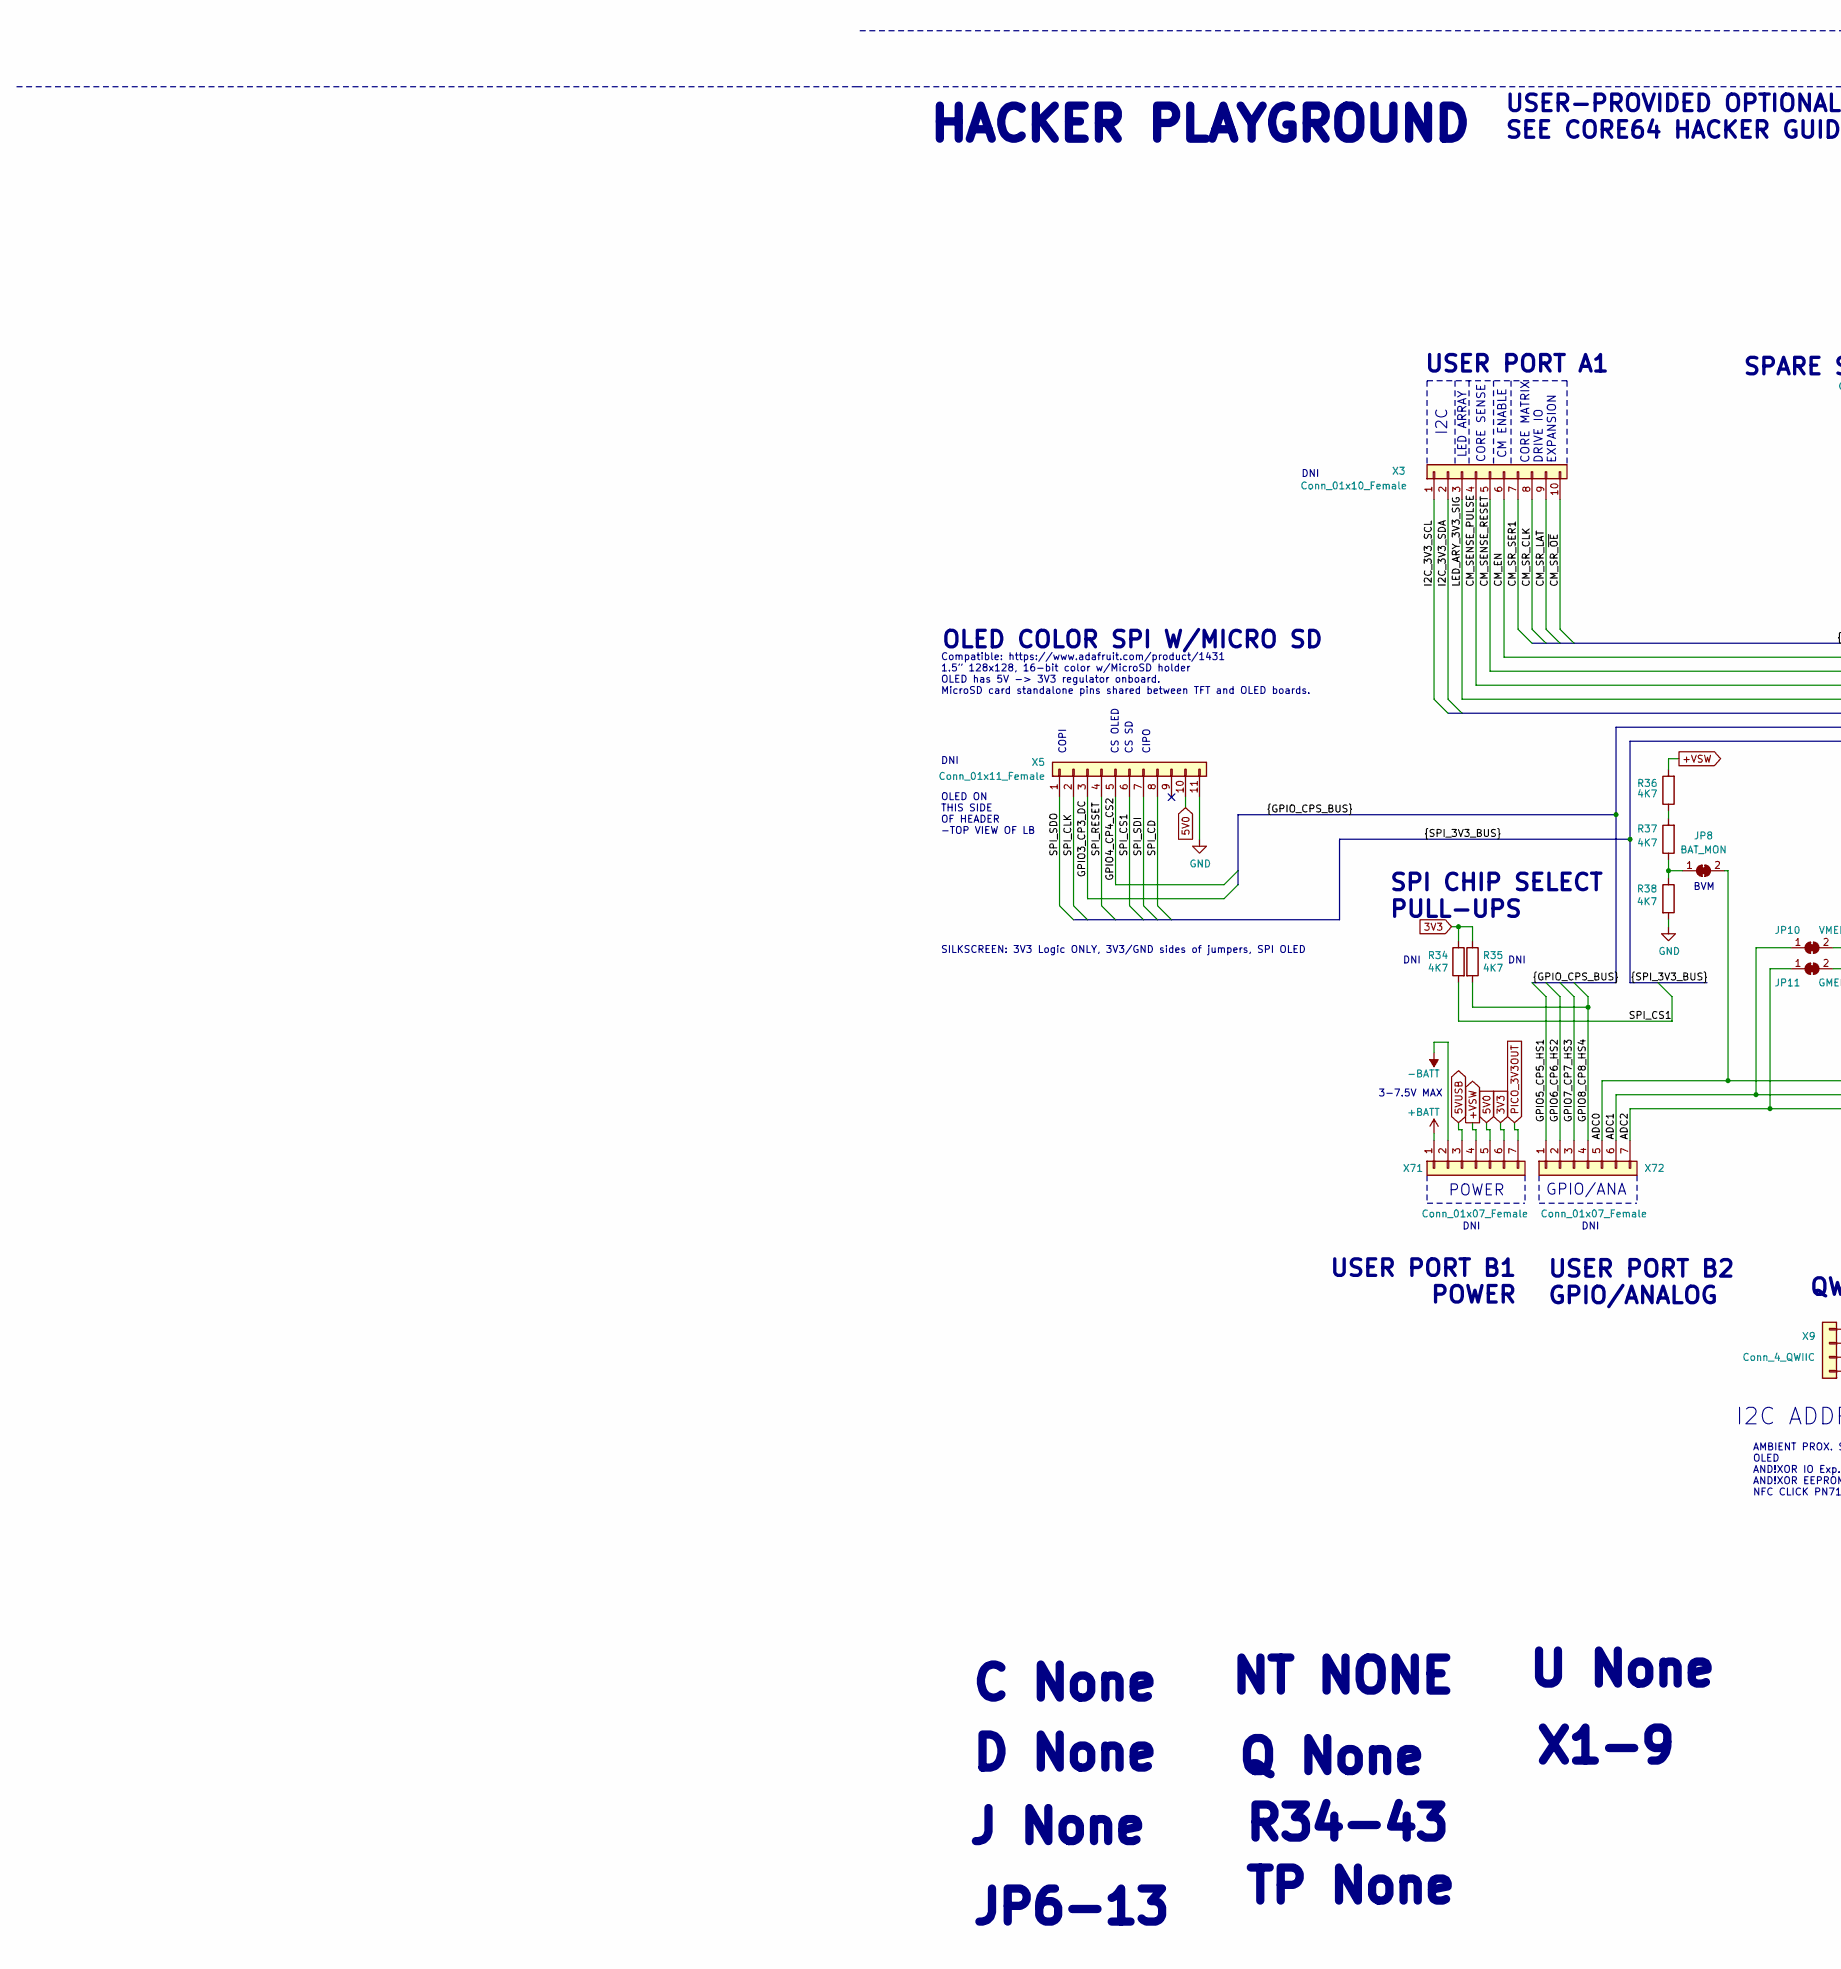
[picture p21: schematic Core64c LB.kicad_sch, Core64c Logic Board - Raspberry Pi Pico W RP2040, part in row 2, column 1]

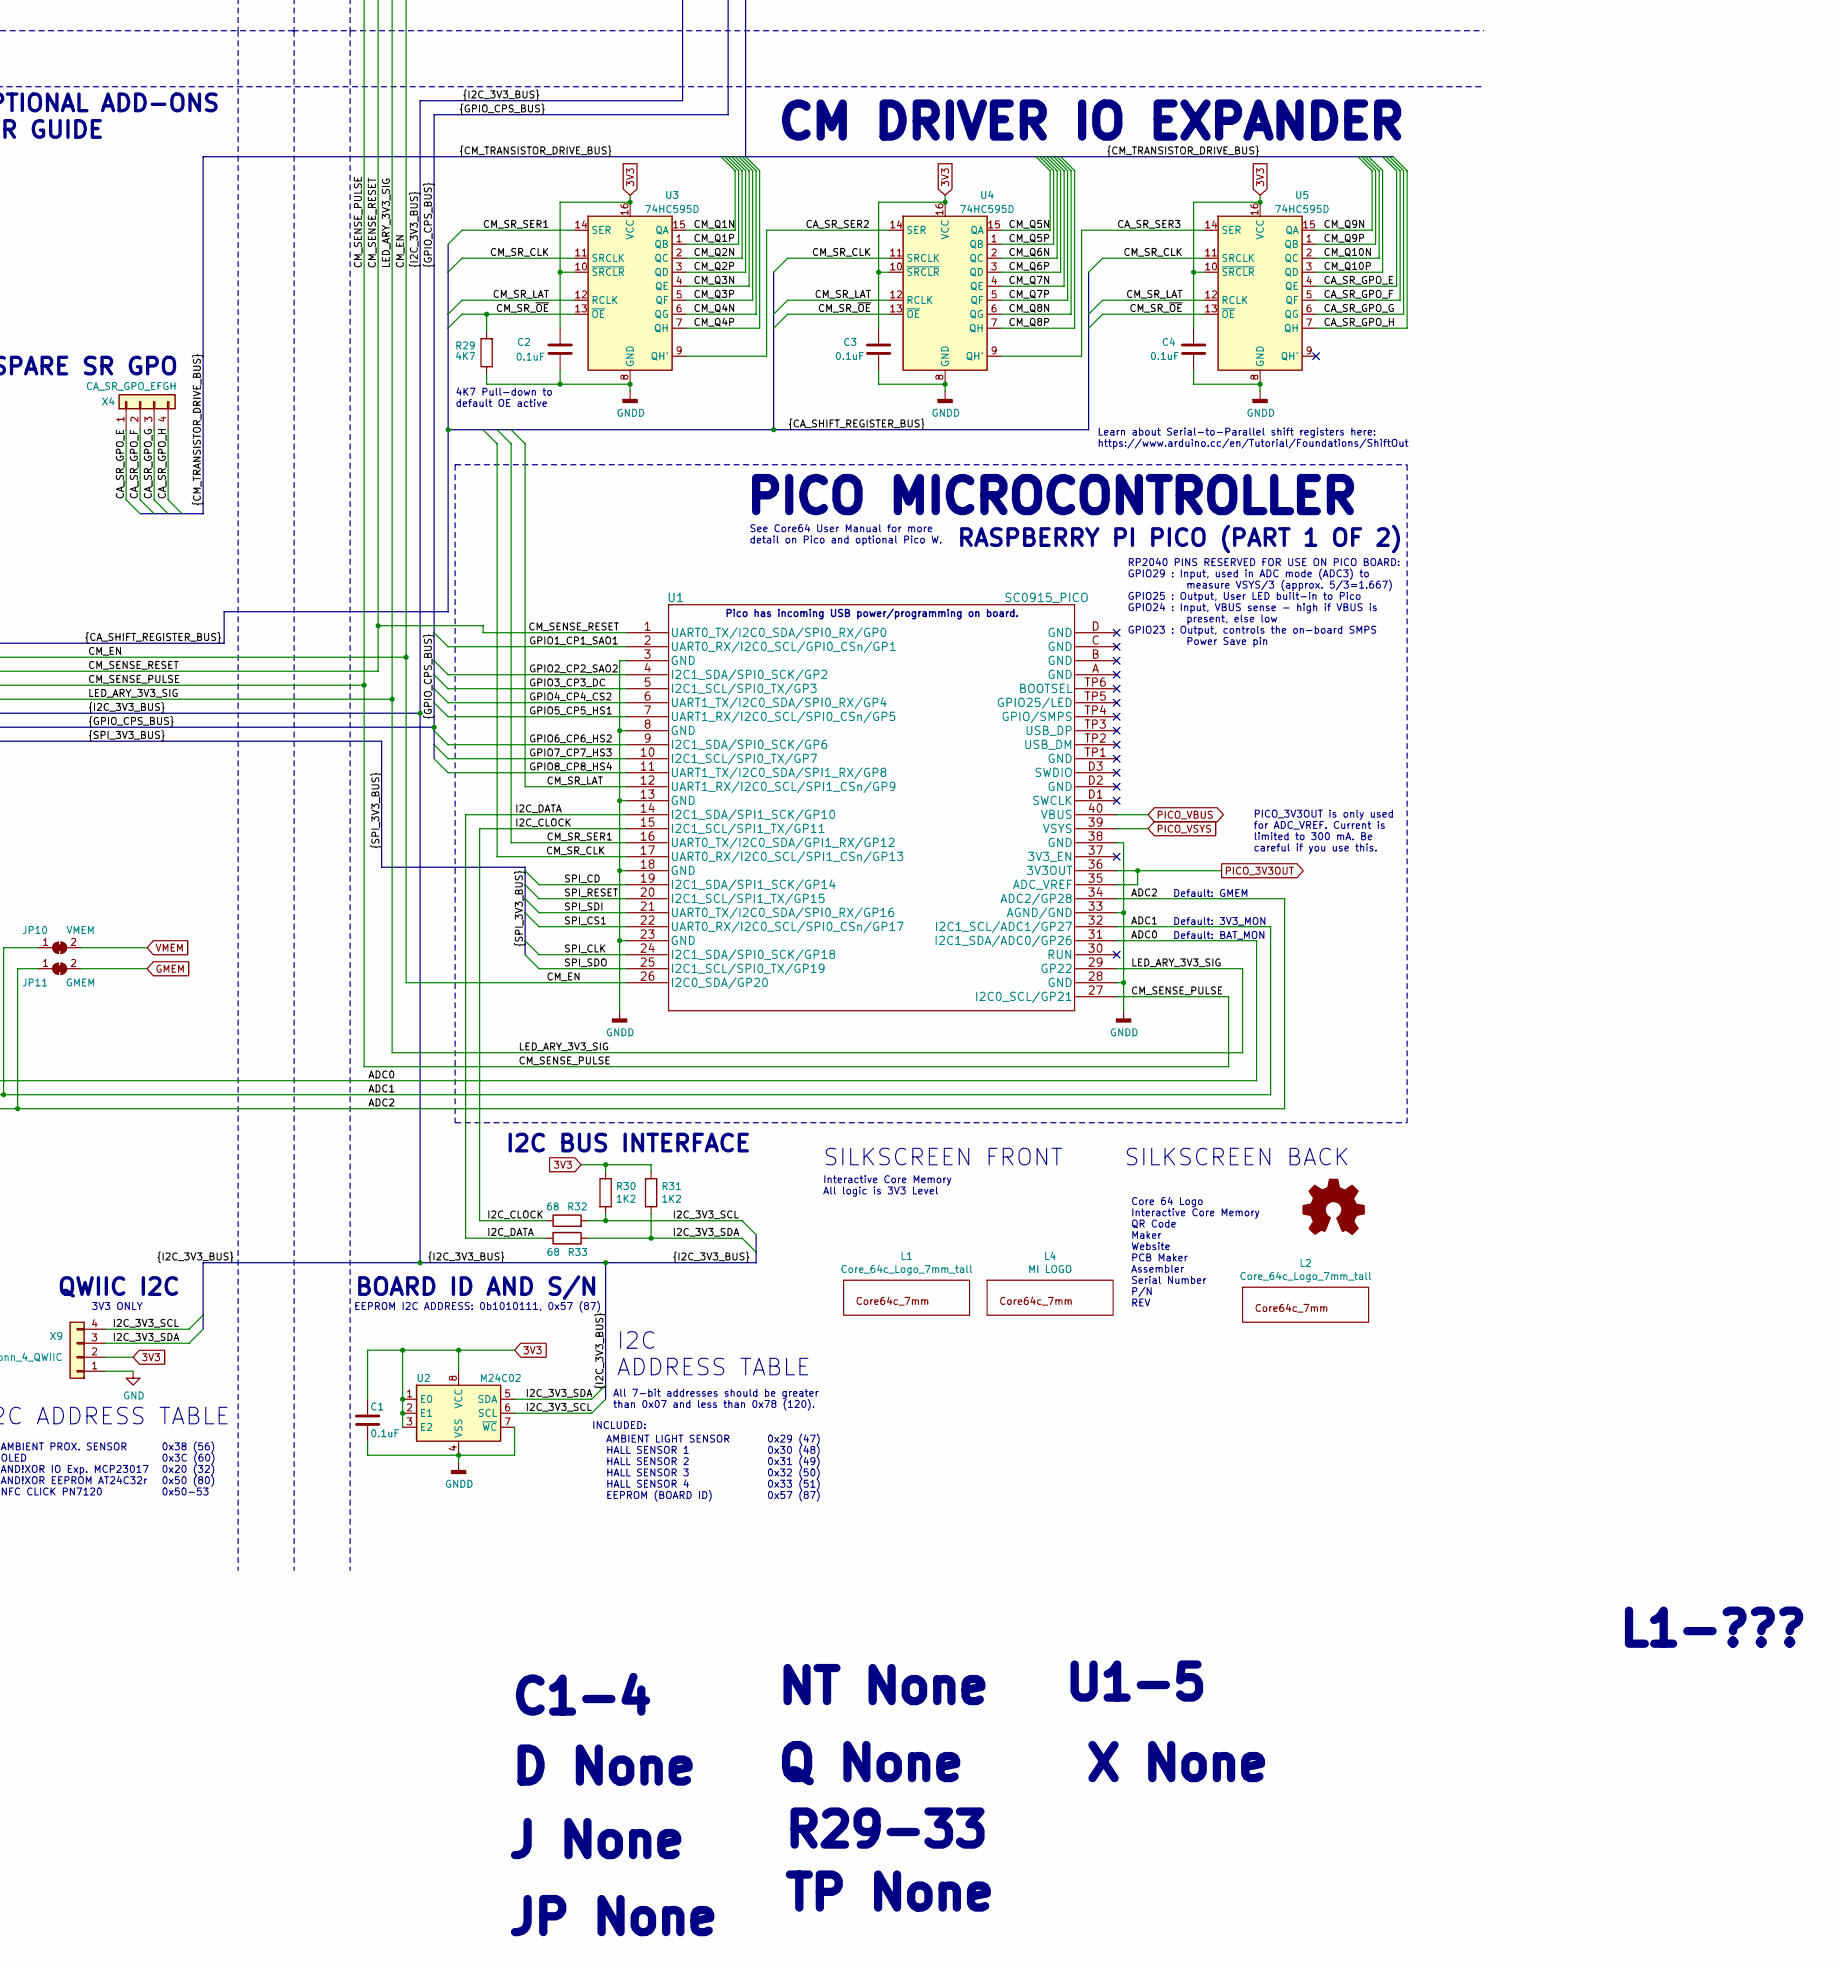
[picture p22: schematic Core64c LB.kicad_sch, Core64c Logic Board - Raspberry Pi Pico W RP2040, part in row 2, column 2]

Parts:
C1, C2, C3, C4, C16, C17, C19: 0.1uF; C_0805_2012Metric; LCSC C28233
C5, C6, C10, C12: 1uF; C_0805_2012Metric; LCSC C28323
C7, C8, C9, C13, C14, C15: 220uF; C_1206_3216Metric; LCSC C412252
C11: 0.01uF; C_0805_2012Metric; LCSC C1710
C18: 10uF; C_0805_2012Metric; LCSC C17024
D1, D3, D5, D7, D9, D11: BAT54AW; SOT-323_SC-70; LCSC C78261
D2, D4, D6, D8, D10, D12: BAT54CW; SOT-323_SC-70; LCSC C83573
H1, H2: GND PAD; MountingHole_3.2mm_M3_Pad_Via
J1, J2: HDR100IMP40F-G-V-TH; PinSocket_1x20_P2.54mm_Vertical
J3: Conn_1x02; PinSocket_1x02_P2.54mm_Vertical
JP3: CORE_CURR_MON; SolderJumper-2_P1.3mm_Bridged_RoundedPad1.0x1.5mm
JP8: BAT_MON; SolderJumper-2_P1.3mm_Bridged_RoundedPad1.0x1.5mm
JP10: VMEM; SolderJumper-2_P1.3mm_Bridged_RoundedPad1.0x1.5mm
JP11: GMEM; SolderJumper-2_P1.3mm_Bridged_RoundedPad1.0x1.5mm
JP14: VBUS_5VUSB_TIE; SolderJumper-2_P1.3mm_Bridged_RoundedPad1.0x1.5mm
JP15: SYS_CUR_MON; SolderJumper-2_P1.3mm_Bridged_RoundedPad1.0x1.5mm
JP16: 5V0_CUR_MON; SolderJumper-2_P1.3mm_Bridged_RoundedPad1.0x1.5mm
JP17: 3V3_CUR_MON; SolderJumper-2_P1.3mm_Bridged_RoundedPad1.0x1.5mm
L1, L2: Core_64c_Logo_7mm_tall; Core64c_Logo_7mm
L3: Logo_Open_Hardware_Small; OSHW-Logo2_9.8x8mm_SilkScreen
L4: MI LOGO; Machine_Ideas_logo_1
Q1, Q3, Q5, Q7, Q9, Q11, Q13, Q15, Q17, Q19: MMBT4403LT1G; SOT-23-3; MPN MMBT4403LT1G; LCSC C78864
Q2, Q4, Q6, Q8, Q10, Q12, Q14, Q16, Q18, Q20: MMBT4401LT1G; SOT-23-3; MPN MMBT4401LT1G; LCSC C31776
Q21: Q_NMOS_DGS_AO3400A; SOT-23-3; LCSC C20917
Q22, Q23: SL3401A; SOT-23-3; LCSC C350311
R1, R2, R3, R4, R5, R6, R7, R8, R9, R10, R11, R12, R13, R14, R15, R16, R17, R18, R19, R20, R28, R46: 470; R_0805_2012Metric; LCSC C17710
R21, R22, R23, R24, R25, R26: 8R2-1%; R_0805_2012Metric; LCSC C17830
R27, R29, R34, R35, R36, R37, R38, R44, R45, R54, R55: 4K7; R_0805_2012Metric; LCSC C17673
R30, R31: 1K2; R_0805_2012Metric; LCSC C17379
R32, R33: 68; R_0805_2012Metric; LCSC C17802
R47, R50, R53: 1K5-1%; R_0805_2012Metric; LCSC C4310
R48, R51: 1K8-1%; R_0805_2012Metric; LCSC C17398
R49, R52: 11-1%; R_0805_2012Metric; LCSC C17430
SW1: SK12D07L4B; SK12D07VG4; LCSC C480340
TP20: S1 IN; TestPoint_THTPad_D1.5mm_Drill1.0mm
TP21: S2 IN; TestPoint_THTPad_D1.5mm_Drill1.0mm
TP22: S2 OUT; TestPoint_THTPad_D1.5mm_Drill1.0mm
TP23: S1 OUT; TestPoint_THTPad_D1.5mm_Drill1.0mm
U1: SC0915_PICO; Pico_W_SC0915
U2: M24C02; SOIC-8_3.9x4.9mm_P1.27mm; LCSC C7562
U3, U4, U5: 74HC595D; SOIC-16_W3.90mm; MPN SN74HC595DR; LCSC C5947
U6: LP38693MP-5.0; SOT-223-5; Manufacturer_Part_Number LP38693MP-5.0; Mouser Part Number LP38693MP-5.0
U7: SSP9193-33M5R; SOT-23-5; Manufacturer_Part_Number SGM2007-3.3XN5/TR; Mouser Part Number SGM2007-3.3XN5/TR
U8: SN74LV1T125DBVR; SOT-23-5; LCSC C473338
U9: LM393; SOIC-8_W3.9mm; LCSC C7955
U10: 74HC02; SOIC-14_3.9x8.7mm_P1.27mm; LCSC C350559
X3: Conn_01x10_Female; PinSocket_1x10_P2.54mm_Vertical
X4: CA_SR_GPO_EFGH; PinSocket_1x04_P2.54mm_Vertical
X5: Conn_01x11_Female; PinSocket_1x11_P2.54mm_Vertical
X9: Conn_4_QWIIC; JST_SH_SM04B-SRSS-TB_1x04-1MP_P1.00mm_Horizontal; MPN SM04B-SRSS-TB(LF)(SN); Digi-Key_PN 455-1804-1-ND
X71, X72: Conn_01x07_Female; PinSocket_1x07_P2.54mm_Vertical

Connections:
3V3: C1.1, C2.1, C3.1, C4.1, C13.1, C14.1, C15.1, C17.1, C18.1, C19.1, J1.13, JP10.2 (B), JP17.2 (B), Q1.2 (E), Q3.2 (E), Q5.2 (E), Q7.2 (E), Q9.2 (E), Q11.2 (E), Q13.2 (E), Q15.2 (E), Q17.2 (E), Q19.2 (E), R30.1, R31.1, R34.1, R35.1, R48.1, R51.1, R54.1, R55.1, U2.1 (E0), U2.2 (E1), U2.3 (E2), U2.8 (VCC), U3.10 (~SRCLR), U3.16 (VCC), U4.10 (~SRCLR), U4.16 (VCC), U5.10 (~SRCLR), U5.16 (VCC), U9.8 (V+), U10.14 (VCC), X9.2, X71.6
5V0: C7.1, C8.1, C9.1, C10.1, C16.1, J2.1, JP16.2 (B), Q23.3 (D), U7.1 (IN), U7.3 (EN), U8.5 (VCC), X5.10, X71.5
5VUSB: J2.20, JP14.1 (A), JP14.2 (B), Q23.1 (G), SW1.3 (C), U1.40 (VBUS), X71.3
+LABB: J2.19, J3.1, SW1.1 (A), X71.1
+VSW: C5.1, JP15.1 (A), R36.2, R45.1, U6.4 (IN), X71.4
-LABB: C1.2, C2.2, C3.2, C4.2, C5.2, C6.2, C7.2, C8.2, C9.2, C10.2, C11.2, C12.2, C13.2, C14.2, C15.2, C16.2, C17.2, C18.2, C19.2, H1.1, H2.1, J1.14, J2.2, J3.2, Q21.2 (S), R27.1, R29.1, R38.2, R44.2, R50.2, R53.2, U1.3 (GND), U1.8 (GND), U1.13 (GND), U1.18 (GND), U1.23 (GND), U1.28 (GND), U1.33 (AGND/GND), U1.38 (GND), U2.4 (VSS), U2.7 (~WC), U3.8 (GND), U4.8 (GND), U5.8 (GND), U6.5 (GND), U7.2 (GND), U8.1 (/OE), U8.3 (GND), U9.4 (V-), U10.7 (GND), X5.11, X9.1, X71.2
/ADC0: JP8.2 (B), U1.31 (I2C1_SDA/ADC0/GP26), X72.5
/ADC1: JP10.1 (A), U1.32 (I2C1_SCL/ADC1/GP27), X72.6
/ADC2: JP11.1 (A), U1.34 (ADC2/GP28), X72.7
/CA_SENSE_1_OUT: R55.2, TP23.1, U9.7, U10.3
/CA_SENSE_2_OUT: R54.2, TP22.1, U9.1, U10.2
/CA_SR_GPO_E: U5.4 (QE), X4.1
/CA_SR_GPO_F: U5.5 (QF), X4.2
/CA_SR_GPO_G: U5.6 (QG), X4.3
/CA_SR_GPO_H: U5.7 (QH), X4.4
/CA_SR_SER2: U3.9 (QH'), U4.14 (SER)
/CA_SR_SER3: U4.9 (QH'), U5.14 (SER)
/CM_EN: R28.1, U1.26 (I2C0_SDA/GP20), X3.6
/CM_Q1N: R2.2, U3.15 (QA)
/CM_Q1P: R1.2, U3.1 (QB)
/CM_Q2N: R4.2, U3.2 (QC)
/CM_Q2P: R3.2, U3.3 (QD)
/CM_Q3N: R6.2, U3.4 (QE)
/CM_Q3P: R5.2, U3.5 (QF)
/CM_Q4N: R8.2, U3.6 (QG)
/CM_Q4P: R7.2, U3.7 (QH)
/CM_Q5N: R10.2, U4.15 (QA)
/CM_Q5P: R9.2, U4.1 (QB)
/CM_Q6N: R12.2, U4.2 (QC)
/CM_Q6P: R11.2, U4.3 (QD)
/CM_Q7N: R14.2, U4.4 (QE)
/CM_Q7P: R13.2, U4.5 (QF)
/CM_Q8N: R16.2, U4.6 (QG)
/CM_Q8P: R15.2, U4.7 (QH)
/CM_Q9N: R18.2, U5.15 (QA)
/CM_Q9P: R17.2, U5.1 (QB)
/CM_Q10N: R20.2, U5.2 (QC)
/CM_Q10P: R19.2, U5.3 (QD)
/CM_SENSE_1_IN: J1.9, R47.1, R52.2, R53.1, TP20.1, U9.5 (+)
/CM_SENSE_2_IN: J1.10, R47.2, R49.2, R50.1, TP21.1, U9.3 (+)
/CM_SENSE_PULSE: U1.27 (I2C0_SCL/GP21), U10.10, U10.11, X3.4
/CM_SENSE_RESET: U1.1 (UART0_TX/I2C0_SDA/SPI0_RX/GP0), U10.8, X3.5
/CM_SR_CLK: U1.17 (UART0_RX/I2C0_SCL/SPI1_CSn/GP13), U3.11 (SRCLK), U4.11 (SRCLK), U5.11 (SRCLK), X3.8
/CM_SR_LAT: U1.12 (UART1_RX/I2C0_SCL/SPI1_CSn/GP9), U3.12 (RCLK), U4.12 (RCLK), U5.12 (RCLK), X3.9
/CM_SR_SER1: U1.16 (UART0_TX/I2C0_SDA/GPI1_RX/GP12), U3.14 (SER), X3.7
/CM_SR_~OE: R29.2, U3.13 (~OE), U4.13 (~OE), U5.13 (~OE), X3.10
/GPIO1_CP1_SAO1: J2.15, U1.2 (UART0_RX/I2C0_SCL/GPI0_CSn/GP1)
/GPIO2_CP2_SAO2: J2.16, U1.4 (I2C1_SDA/SPI0_SCK/GP2)
/GPIO3_CP3_DC: J2.17, U1.5 (I2C1_SCL/SPI0_TX/GP3), X5.3
/GPIO4_CP4_CS2: J2.18, U1.6 (UART1_TX/I2C0_SDA/SPI0_RX/GP4), X5.5
/GPIO5_CP5_HS1: J1.18, U1.7 (UART1_RX/I2C0_SCL/SPI0_CSn/GP5), X72.1
/GPIO6_CP6_HS2: J1.17, U1.9 (I2C1_SDA/SPI0_SCK/GP6), X72.2
/GPIO7_CP7_HS3: J1.16, U1.10 (I2C1_SCL/SPI0_TX/GP7), X72.3
/GPIO8_CP8_HS4: J1.15, R35.2, U1.11 (UART1_TX/I2C0_SDA/SPI1_RX/GP8), X72.4
/I2C_3V3_SCL: J1.11, R30.2, R32.2, U2.6 (SCL), X3.1, X9.4
/I2C_3V3_SDA: J1.12, R31.2, R33.1, U2.5 (SDA), X3.2, X9.3
/I2C_CLOCK: R32.1, U1.15 (I2C1_SCL/SPI1_TX/GP11)
/I2C_DATA: R33.2, U1.14 (I2C1_SDA/SPI1_SCK/GP10)
/LED_ARY_3V3_SIG: U1.29 (GP22), U8.2 (A), X3.3
/LED_ARY_5V0_SIG: J1.1, R46.1
/SPI_CD: U1.19 (I2C1_SDA/SPI1_SCK/GP14), X5.8
/SPI_CLK: U1.24 (I2C1_SDA/SPI0_SCK/GP18), X5.2
/SPI_CS1: R34.2, U1.22 (UART0_RX/I2C0_SCL/SPI0_CSn/GP17), X5.6
/SPI_RESET: U1.20 (I2C1_SCL/SPI1_TX/GP15), X5.4
/SPI_SDI: U1.21 (UART0_TX/I2C0_SDA/SPI0_RX/GP16), X5.7
/SPI_SDO: U1.25 (I2C1_SCL/SPI0_TX/GP19), X5.1
/USER1: J1.2
/USER2: J1.19
/USER3: J1.20
/XB0: D1.2, D2.1, J2.7
/XB1: D1.1, D2.2, J2.8
/XB2: D3.2, D4.1, J2.9
/XB3: D3.1, D4.2, J2.10
/XB4: D5.2, D6.1, J2.11
/XB5: D5.1, D6.2, J2.12
/XB6: D7.2, D8.1, J2.13
/XB7: D7.1, D8.2, J2.14
/XT0,4: J2.6, R21.2
/XT1,5: J2.5, R22.1
/XT2,6: J2.4, R23.1
/XT3,7: J2.3, R24.1
/YL0: D9.1, D10.2, J1.3
/YL1: D9.2, D10.1, J1.4
/YL2: D11.1, D12.2, J1.5
/YL3: D11.2, D12.1, J1.6
/YL4,6: J1.7, R25.1
/YL5,7: J1.8, R26.1
GMEM: JP3.2 (B), JP11.2 (B), Q2.2 (E), Q4.2 (E), Q6.2 (E), Q8.2 (E), Q10.2 (E), Q12.2 (E), Q14.2 (E), Q16.2 (E), Q18.2 (E), Q20.2 (E)
unnamed: JP3.1 (A), Q21.3 (D)
unnamed: JP8.1 (A), R37.1, R38.1
unnamed: JP15.2 (B), Q22.2 (S)
unnamed: C6.1, JP16.1 (A), U6.3 (VOUT)
unnamed: C12.1, JP17.1 (A), U7.5 (OUT)
unnamed: Q1.1 (B), R1.1
unnamed: D1.3, D3.3, Q1.3 (C)
unnamed: Q2.1 (B), R2.1
unnamed: D2.3, D4.3, Q2.3 (C)
unnamed: Q3.1 (B), R3.1
unnamed: D5.3, D7.3, Q3.3 (C)
unnamed: Q4.1 (B), R4.1
unnamed: D6.3, D8.3, Q4.3 (C)
unnamed: Q5.1 (B), R5.1
unnamed: Q5.3 (C), Q6.3 (C), R21.1
unnamed: Q6.1 (B), R6.1
unnamed: Q7.1 (B), R7.1
unnamed: Q7.3 (C), Q8.3 (C), R22.2
unnamed: Q8.1 (B), R8.1
unnamed: Q9.1 (B), R9.1
unnamed: Q10.1 (B), R10.1
unnamed: Q9.3 (C), Q10.3 (C), R23.2
unnamed: Q11.1 (B), R11.1
unnamed: Q11.3 (C), Q12.3 (C), R24.2
unnamed: Q12.1 (B), R12.1
unnamed: Q13.1 (B), R13.1
unnamed: D9.3, Q13.3 (C)
unnamed: Q14.1 (B), R14.1
unnamed: D10.3, Q14.3 (C)
unnamed: Q15.1 (B), R15.1
unnamed: D11.3, Q15.3 (C)
unnamed: Q16.1 (B), R16.1
unnamed: D12.3, Q16.3 (C)
unnamed: Q17.1 (B), R17.1
unnamed: Q17.3 (C), Q18.3 (C), R25.2
unnamed: Q18.1 (B), R18.1
unnamed: Q19.1 (B), R19.1
unnamed: Q19.3 (C), Q20.3 (C), R26.2
unnamed: Q20.1 (B), R20.1
unnamed: Q21.1 (G), R27.2, R28.2
unnamed: Q22.3 (D), SW1.2 (B)
unnamed: Q22.1 (G), R44.1
unnamed: R36.1, R37.2
unnamed: R45.2, U6.1 (EN)
unnamed: C11.1, U7.4 (BP)
unnamed: R46.2, U8.4 (Y)
unnamed: R51.2, R52.1, U9.2 (-)
unnamed: R48.2, R49.1, U9.6 (_)
unnamed: U10.1, U10.5, U10.6
unnamed: U10.4, U10.12
unnamed: U10.9, U10.13
PICO_3V3OUT: U1.35 (ADC_VREF), U1.36 (3V3OUT), X71.7
PICO_VSYS: Q23.2 (S), U1.39 (VSYS)

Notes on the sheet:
Bits 63-56
BATTERY POWER INPUT 3.0 to 7.5V MAX!
Pico has incoming USB power/programming on board.
SENSE SIGNAL OUTPUT LATCH
NT None
XT5
XT6
ROW 0,4
COL 3
YL4
3V3 REGULATOR
C None
NT NONE
SOT-23-5 300mV DROP @ 300mA
COL 1
TP None
HACKER PLAYGROUND
Default: GMEM
USER PORT B1 POWER
DNI
U None
SW1
ROW 1,5
PICO MICROCONTROLLER
PRIMARY SWITCHED POWER SOURCES: ON (BAT) : From battery on LED Array Board OFF (USB) : From USB port on Pico ALTERNATE/OPTIONAL SWITCHED POWER SOURCES: ON (BAT) : From battery on Logic Board OFF (USB) : From USB port of LiPo Charger on LED Array Board * Requires closing USB Charge Enable solder jum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
0x38 (56) 0x3C (60) 0x20 (32) 0x50 (80) 0x50-53
VIN MAX 5.5V
Bits 7-0
COL 1,5
N-CHNL FET as low-side switch
Rds(on)0.06
0.2Ω ≤ COUT ESR ≤ 5Ω
See Core64 User Manual for more detail on Pico and optional Pico W.
USER PORT B2 GPIO/ANALOG
0.25V DROP @ 500mA
CORE MATRIX, OPTIONAL ACCESSORIES, ALL LOGIC
LED ARRAY, MCU, 3V3 REGULATOR, OPTIONAL ACCESSORIES
OLED ON THIS SIDE OF HEADER -TOP VIEW OF LB
X None
Q None

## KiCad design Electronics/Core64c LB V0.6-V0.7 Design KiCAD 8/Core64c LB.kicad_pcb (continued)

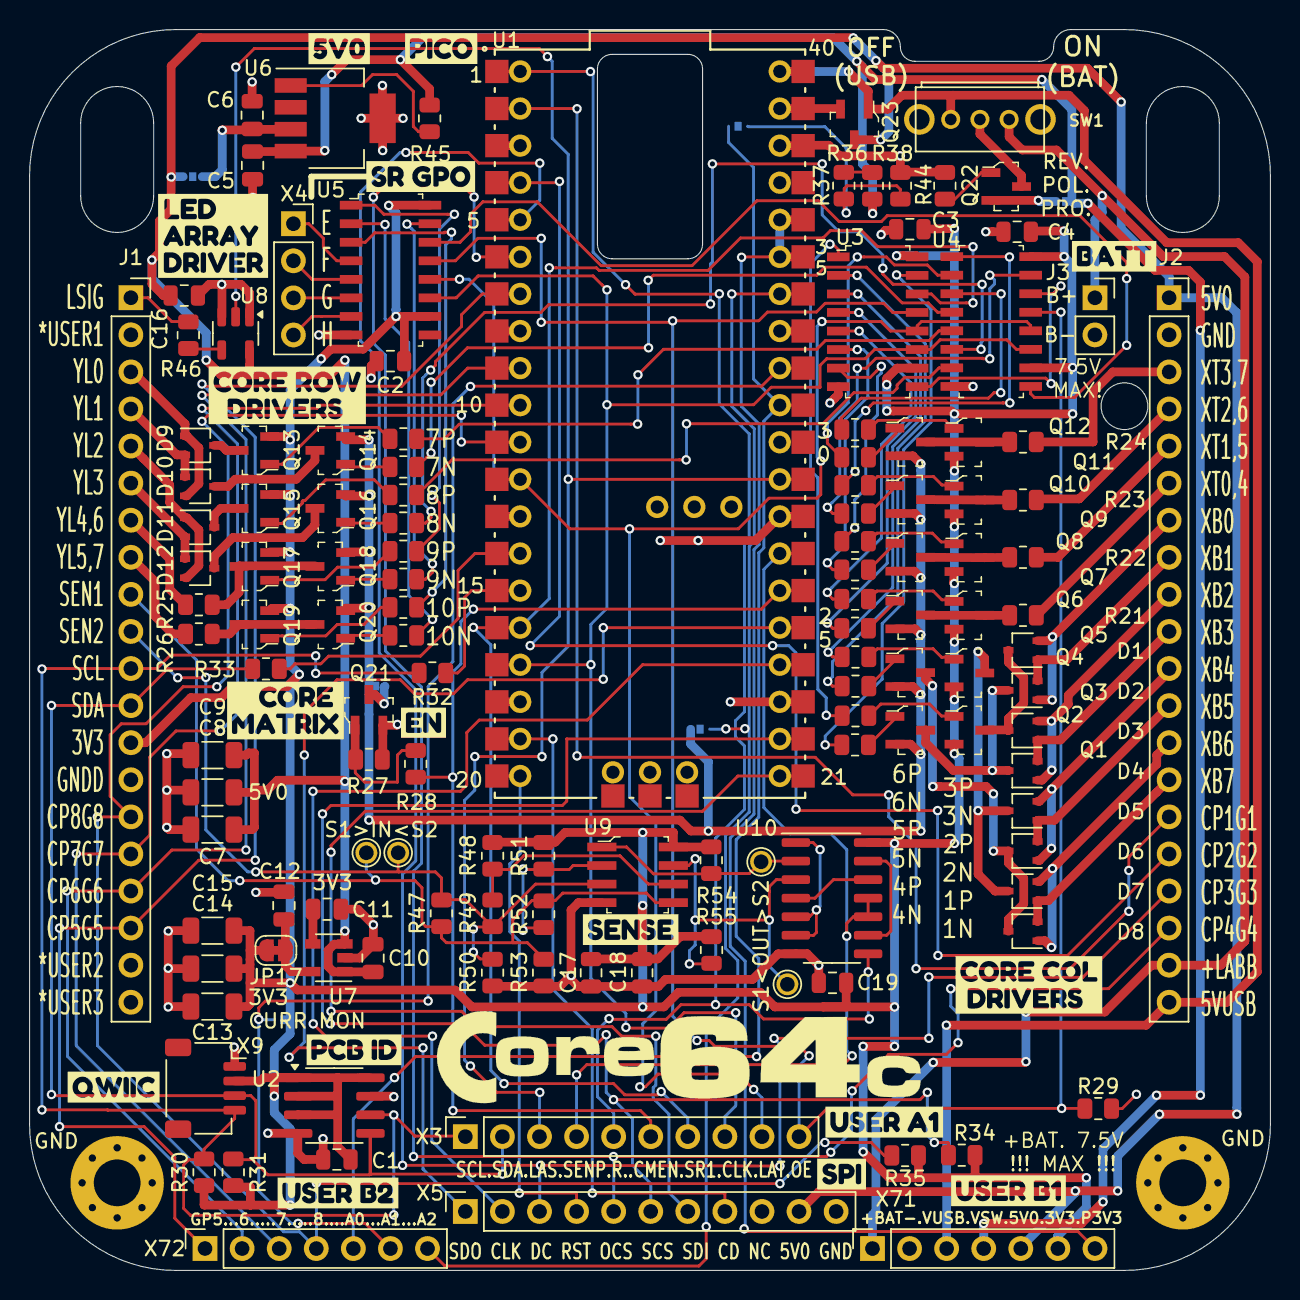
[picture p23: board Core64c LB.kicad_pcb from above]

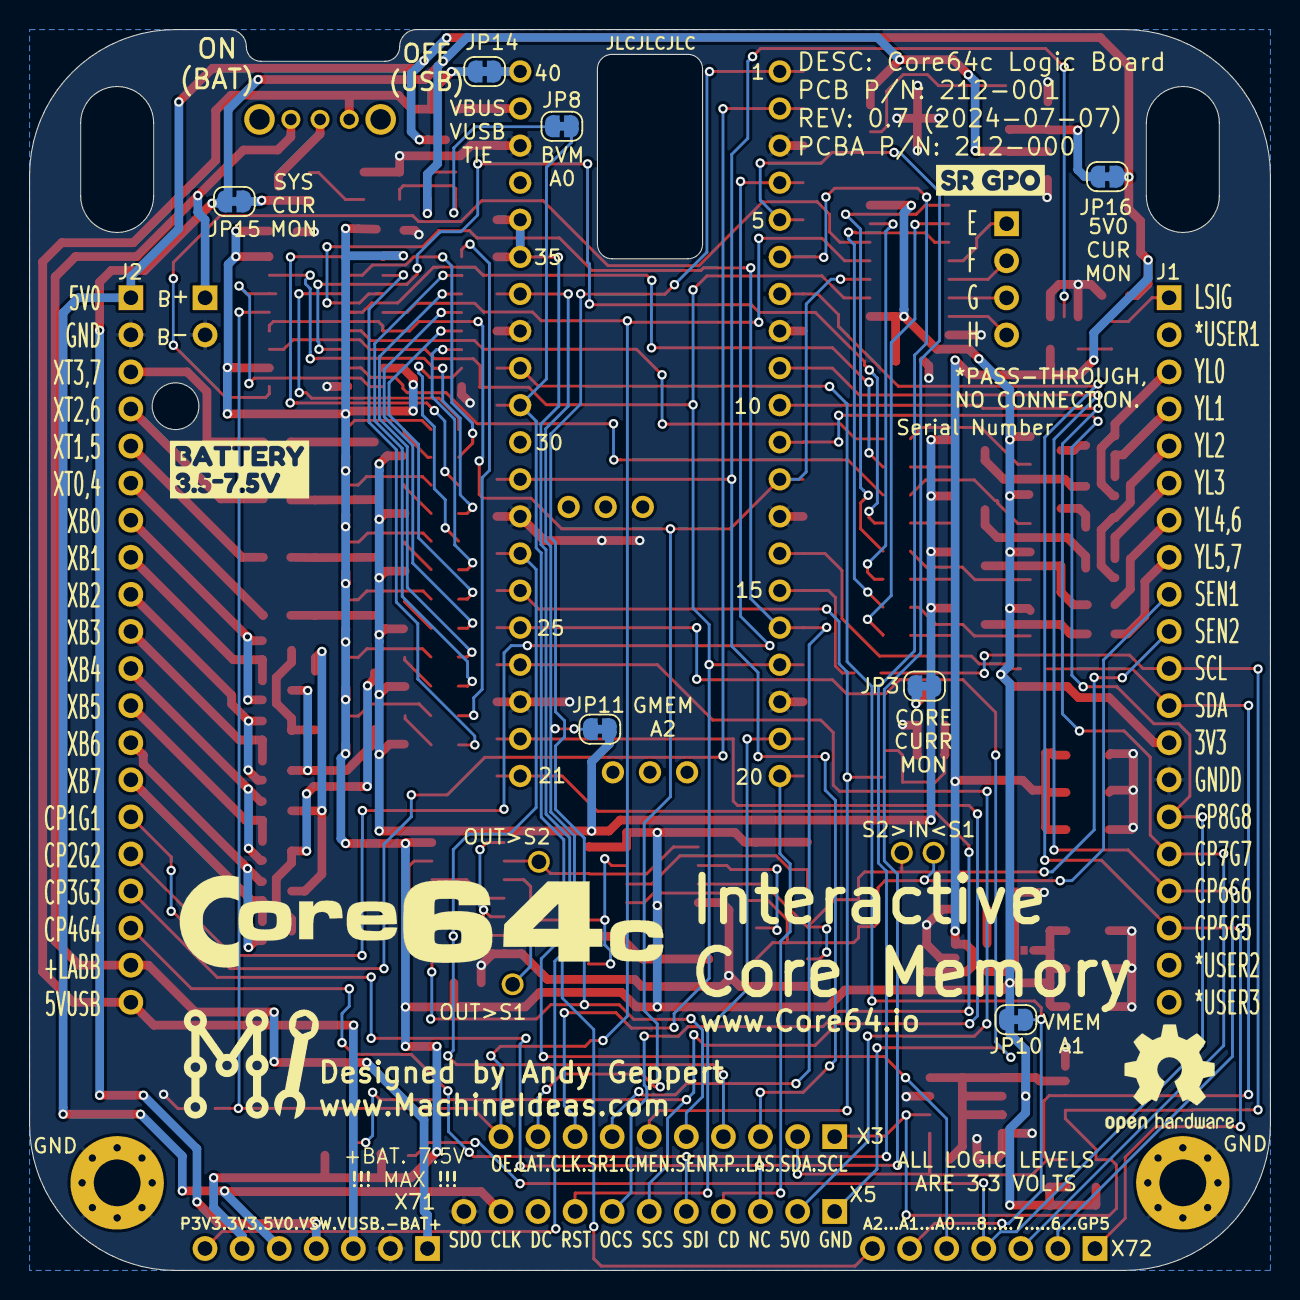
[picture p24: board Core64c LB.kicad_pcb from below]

Board: 2 copper layers, 85.0 x 85.0 mm, 161 parts (11 on the bottom side), 138 nets.

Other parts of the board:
L3#2: Logo_Open_Hardware_Small; OSHW-Logo2_9.8x8mm_SilkScreen
kibuzzard-668B4A9A: G***; kibuzzard-668B4A9A
kibuzzard-668B4AC0: G***; kibuzzard-668B4AC0
kibuzzard-668B4B17: G***; kibuzzard-668B4B17
kibuzzard-668B4C2C: G***; kibuzzard-668B4C2C
kibuzzard-668B4C14: G***; kibuzzard-668B4C14
kibuzzard-668B4C20: G***; kibuzzard-668B4C20
kibuzzard-668B4CFD: G***; kibuzzard-668B4CFD
kibuzzard-668B5F7C: G***; kibuzzard-668B5F7C
kibuzzard-668B48EA: G***; kibuzzard-668B48EA
kibuzzard-668B48F5: G***; kibuzzard-668B48F5
kibuzzard-668B48FD: G***; kibuzzard-668B48FD
kibuzzard-668B4889: G***; kibuzzard-668B4889
kibuzzard-668B4910: G***; kibuzzard-668B4910
kibuzzard-668B4919: G***; kibuzzard-668B4919
kibuzzard-668B4920: G***; kibuzzard-668B4920
kibuzzard-668B4929: G***; kibuzzard-668B4929
kibuzzard-668B4946: G***; kibuzzard-668B4946
kibuzzard-668B5072: G***; kibuzzard-668B5072

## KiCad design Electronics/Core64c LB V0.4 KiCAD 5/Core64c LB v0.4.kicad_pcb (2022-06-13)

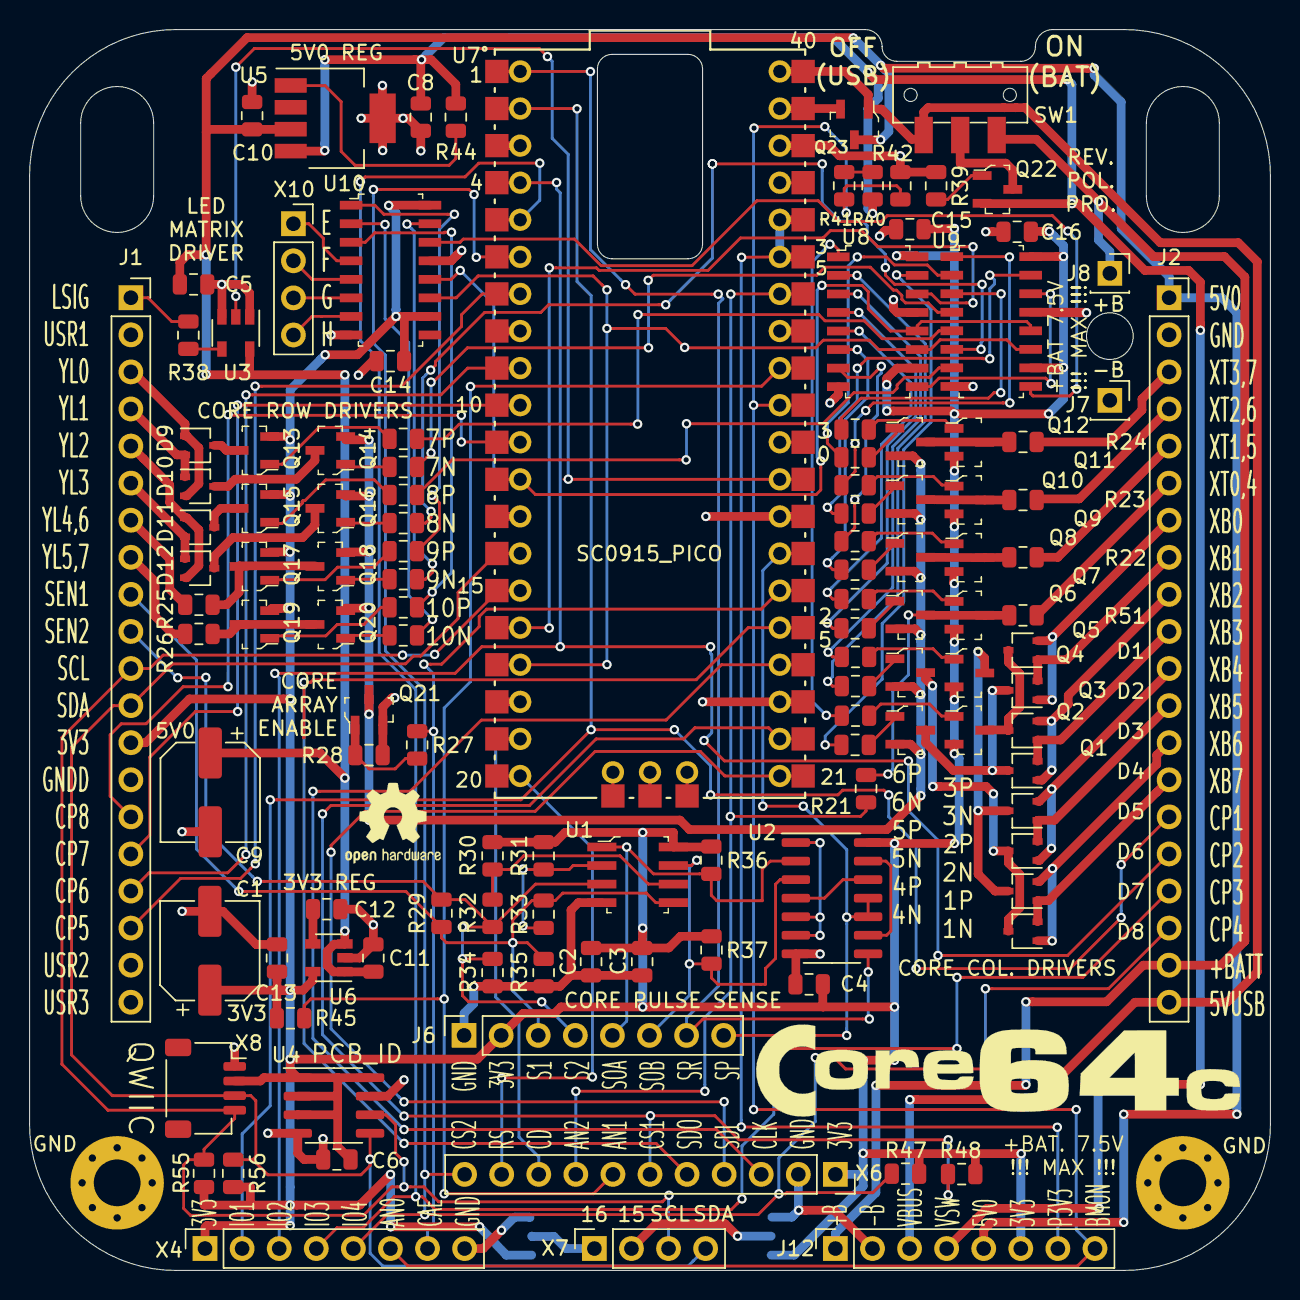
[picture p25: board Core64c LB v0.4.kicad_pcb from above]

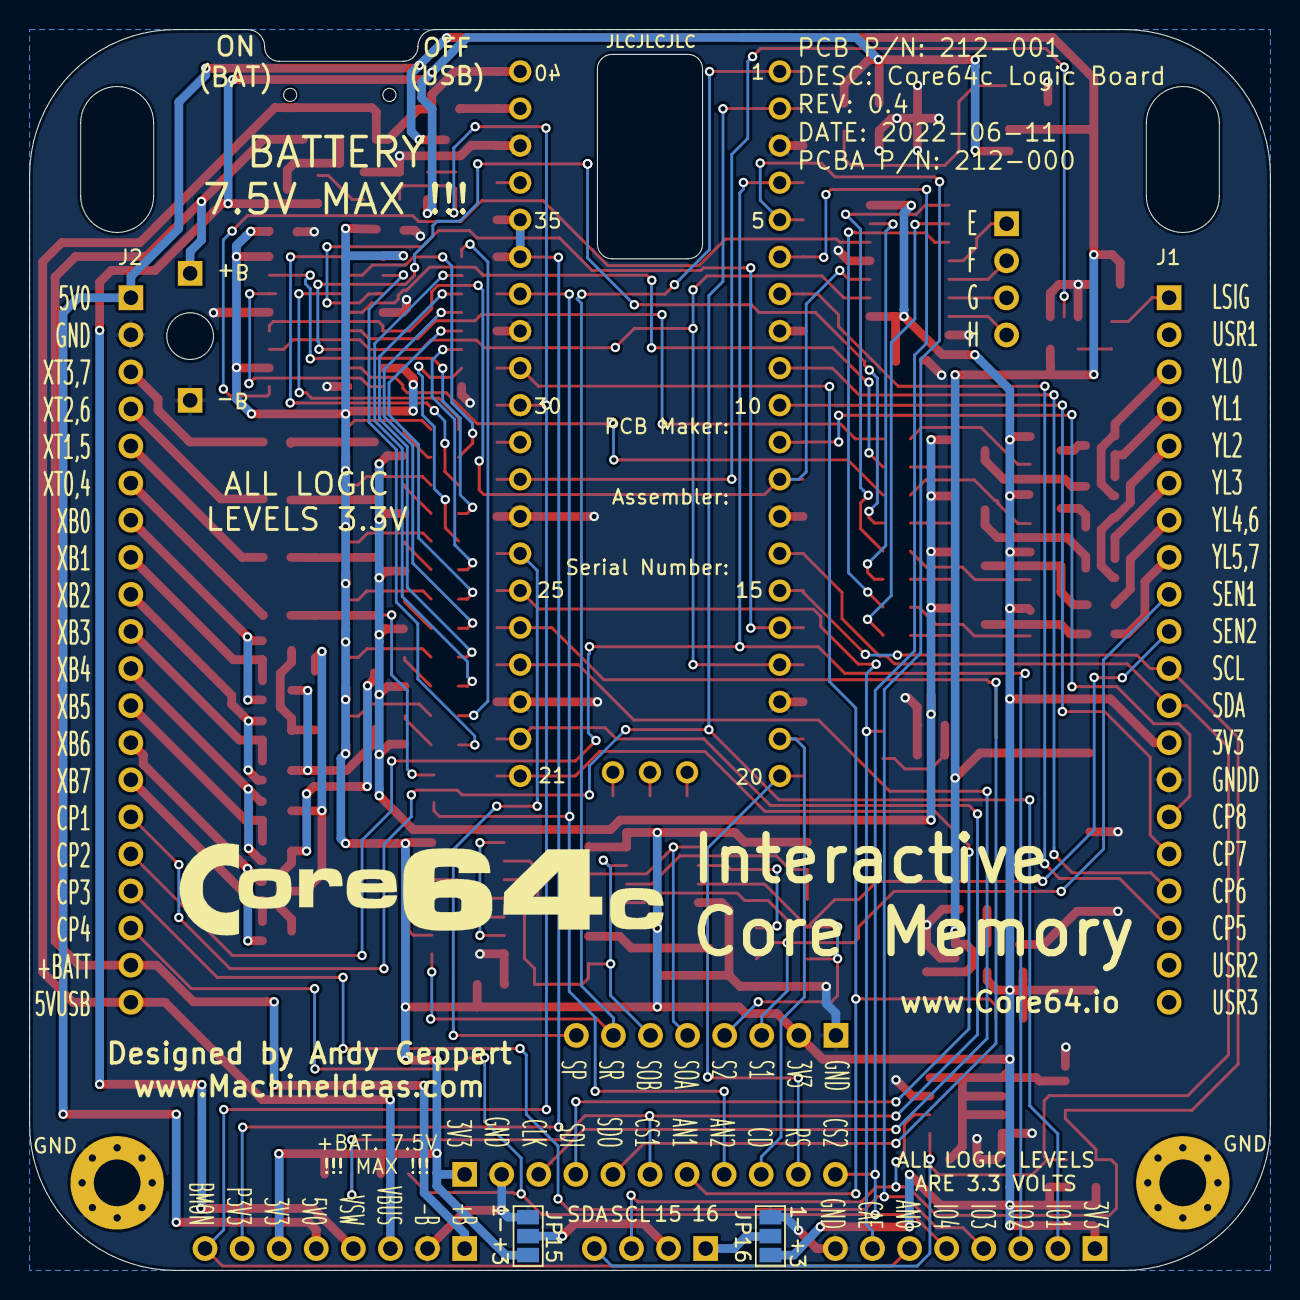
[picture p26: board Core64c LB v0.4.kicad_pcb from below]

Board: 2 copper layers, 85.0 x 85.0 mm, 128 parts (3 on the bottom side), 132 nets.

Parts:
C1, C9: 470uF; CP_Elec_6.3x7.7
C2, C4, C5, C6, C14, C15, C16: 0.1uF; C_0805_2012Metric
C3: 10uF; C_0805_2012Metric
C8, C10, C11, C13: 1uF; C_0805_2012Metric
C12: 0.01uF; C_0805_2012Metric
D1, D3, D5, D7, D9, D11: BAT54AW; SOT-323_SC-70
D2, D4, D6, D8, D10, D12: BAT54CW; SOT-323_SC-70
H1, H2: GND PAD; MountingHole_3.2mm_M3_Pad_Via
J1, J2: HDR100IMP40F-G-V-TH; PinSocket_1x20_P2.54mm_Vertical
J6: SENSE DEBUG; PinSocket_1x08_P2.54mm_Vertical
J7: ALT. BATT-; PinSocket_1x01_P2.54mm_Vertical
J8: ALT. BATT+; PinSocket_1x01_P2.54mm_Vertical
J12: Conn_01x08_Female; PinSocket_1x08_P2.54mm_Vertical
JP15, JP16: SolderJumper_3_Open; SolderJumper-3_P1.3mm_Open_Pad1.0x1.5mm_NumberLabels
L1, L2: Core_64c_Logo_7mm_tall; Core64c_Logo_7mm
L3: Logo_Open_Hardware_Small; OSHW-Logo2_7.3x6mm_SilkScreen
Q1, Q3, Q5, Q7, Q9, Q11, Q13, Q15, Q17, Q19: MMBT4403LT1G; SOT-23-3
Q2, Q4, Q6, Q8, Q10, Q12, Q14, Q16, Q18, Q20: MMBT4401LT1G; SOT-23-3
Q21: Q_NMOS_DGS_AO3400A; SOT-23-3
Q22, Q23: SL3401A; SOT-23-3
R1, R2, R3, R4, R5, R6, R7, R8, R9, R10, R11, R12, R13, R14, R15, R16, R17, R18, R19, R20, R27, R38: 470; R_0805_2012Metric
R21, R28, R39, R40, R41, R42, R44, R45: 10k; R_0805_2012Metric
R22, R23, R24, R25, R26, R51: 6R8-1%; R_0805_2012Metric
R29, R34, R35: 1K5-1%; R_0805_2012Metric
R30, R31: 1K8-1%; R_0805_2012Metric
R32, R33: 11-1%; R_0805_2012Metric
R36, R37, R55, R56: 1K2; R_0805_2012Metric
R47, R48: 10K; R_0805_2012Metric
SW1: JS102011SAQN; SW_SPDT_CK-JS102011SAQN_Core64_Recessed
U1: LM393; SOIC-8_W3.9mm
U2: 74HC02; SOIC-14_3.9x8.7mm_P1.27mm
U3: SN74LV1T125DBVR; SOT-23-5
U4: M24C02; SOIC-8_3.9x4.9mm_P1.27mm
U5: LP38693MP-5.0; SOT-223-5
U6: SGM2007-3.3XN5_TR; SOT-23-5
U7: SC0915_PICO; Pico_SC0915_THRUHOLE_CUTOUTS
U8, U9, U10: 74HC595D; SOIC-16_W3.90mm
X4: HEADER_8-PIN_0.1; PinSocket_1x08_P2.54mm_Vertical
X6: HEADER_11-PIN_0.1; PinSocket_1x11_P2.54mm_Vertical
X7, X10: HEADER_4-PIN_0.1; PinSocket_1x04_P2.54mm_Vertical
X8: QWIIC; JST_SH_SM04B-SRSS-TB_1x04-1MP_P1.00mm_Horizontal

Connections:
3V3: C1.1, C2.1, C3.1, C4.1, C6.1, C13.1, C14.1, C15.1, C16.1, J1.13, J6.2, J12.6, JP15.3, JP16.3, Q1.2, Q3.2, Q5.2, Q7.2, Q9.2, Q11.2, Q13.2, Q15.2, Q17.2, Q19.2, R30.1, R31.1, R36.1, R37.1, R45.2, R47.1, R48.1, R55.1, R56.1, U1.8, U2.14, U4.1, U4.2, U4.3, U4.8, U6.5, U8.10, U8.16, U9.10, U9.16, U10.10, U10.16, X4.1, X6.1, X8.2
3V3_MON: R45.1, U7.32, X6.7
5V0: C5.1, C9.1, C10.1, C11.1, J2.1, J12.5, Q23.3, U3.5, U5.3, U6.1, U6.3
+BATT: J2.19, J8.1, J12.1, SW1.1
+VSW: C8.1, J12.4, Q22.2, R40.2, R44.1, U5.4
-BATT: C1.2, C2.2, C3.2, C4.2, C5.2, C6.2, C8.2, C9.2, C10.2, C11.2, C12.2, C13.2, C14.2, C15.2, C16.2, H1.1, H2.1, J1.14, J2.2, J6.1, J7.1, J12.2, JP15.1, JP16.1, Q21.2, R28.1, R34.2, R35.2, R39.2, R42.2, U1.4, U2.7, U3.1, U3.3, U4.4, U4.7, U5.5, U6.2, U7.3, U7.8, U7.13, U7.18, U7.23, U7.28, U7.33, U7.38, U8.8, U8.13, U9.8, U9.13, U10.8, U10.13, X4.8, X6.2, X8.1
BAT_MON: J12.8, R41.1, R42.1, U7.31, X4.6
CORE_ARRAY_ENABLE: R27.2, U7.26, X4.7
CP1_EN: J2.15, U7.2, X4.2
CP2_EN: J2.16, U7.4, X4.3
CP3_EN: J2.17, U7.5, X4.4
CP4_EN: J2.18, R47.2, U7.6, X4.5, X6.11
CP5_EN: J1.18, U7.7
CP6_EN: J1.17, U7.9
CP7_EN: J1.16, U7.10
CP8_EN: J1.15, U7.11
GNDPWR: Q2.2, Q4.2, Q6.2, Q8.2, Q10.2, Q12.2, Q14.2, Q16.2, Q18.2, Q20.2, Q21.3
I2C_CLOCK: J1.11, R55.2, U4.6, U7.15, X7.3, X8.4
I2C_DATA: J1.12, R56.2, U4.5, U7.14, X7.4, X8.3
LED_MATRIX_3V3_SIG: U3.2, U7.29
LED_MATRIX_5V0_SIG: J1.1, R38.1
unnamed: C12.1, U6.4
unnamed: D1.3, D3.3, Q1.3
unnamed: D2.3, D4.3, Q2.3
unnamed: D5.3, D7.3, Q3.3
unnamed: D6.3, D8.3, Q4.3
unnamed: D9.3, Q13.3
unnamed: D10.3, Q14.3
unnamed: D11.3, Q15.3
unnamed: D12.3, Q16.3
unnamed: JP15.2, X7.2
unnamed: JP16.2, X7.1
unnamed: Q1.1, R1.1
unnamed: Q2.1, R2.1
unnamed: Q3.1, R3.1
unnamed: Q4.1, R4.1
unnamed: Q5.1, R5.1
unnamed: Q5.3, Q6.3, R21.1, R51.1
unnamed: Q6.1, R6.1
unnamed: Q7.1, R7.1
unnamed: Q7.3, Q8.3, R22.2
unnamed: Q8.1, R8.1
unnamed: Q9.1, R9.1
unnamed: Q10.1, R10.1
unnamed: Q9.3, Q10.3, R23.2
unnamed: Q11.1, R11.1
unnamed: Q11.3, Q12.3, R24.2
unnamed: Q12.1, R12.1
unnamed: Q13.1, R13.1
unnamed: Q14.1, R14.1
unnamed: Q15.1, R15.1
unnamed: Q16.1, R16.1
unnamed: Q17.1, R17.1
unnamed: Q17.3, Q18.3, R25.2
unnamed: Q18.1, R18.1
unnamed: Q19.1, R19.1
unnamed: Q19.3, Q20.3, R26.2
unnamed: Q20.1, R20.1
unnamed: Q21.1, R27.1, R28.2
unnamed: Q22.1, R39.1
unnamed: Q22.3, SW1.2
unnamed: R30.2, R32.1, U1.6
unnamed: R31.2, R33.1, U1.2
unnamed: R38.2, U3.4
unnamed: R40.1, R41.2
unnamed: R44.2, U5.1
unnamed: U2.1, U2.5, U2.6
unnamed: U2.4, U2.12
unnamed: U2.9, U2.13
unnamed: U8.9, U9.14
unnamed: U10.4, X10.1
unnamed: U10.5, X10.2
unnamed: U10.6, X10.3
unnamed: U10.7, X10.4
unnamed: U9.9, U10.14
PICO_3V3OUT: J12.7, U7.35, U7.36
PICO_VBUS: J2.20, J12.3, Q23.1, SW1.3, U7.40
PICO_VSYS: Q23.2, U7.39
Q1N: R2.2, U8.15
Q1P: R1.2, U8.1
Q2N: R4.2, U8.2
Q2P: R3.2, U8.3
Q3N: R6.2, U8.4
Q3P: R5.2, U8.5
Q4N: R8.2, U8.6
Q4P: R7.2, U8.7
Q5N: R10.2, U9.15
Q5P: R9.2, U9.1
Q6N: R12.2, U9.2
Q6P: R11.2, U9.3
Q7N: R14.2, U9.4
Q7P: R13.2, U9.5
Q8N: R16.2, U9.6
Q8P: R15.2, U9.7
Q9N: R18.2, U10.15
Q9P: R17.2, U10.1
Q10N: R20.2, U10.2
Q10P: R19.2, U10.3
SENSE1: J1.9, J6.3, R29.1, R33.2, R35.1, U1.5
SENSE2: J1.10, J6.4, R29.2, R32.2, R34.1, U1.3
SENSE_OUT_A: J6.5, R36.2, U1.1, U2.2
SENSE_OUT_B: J6.6, R37.2, U1.7, U2.3
SENSE_PULSE: J6.8, U2.10, U2.11, U7.27
SENSE_RESET: J6.7, U2.8, U7.1
SPARE_ADC2: R21.2, U7.34, X6.8
SPI_CD: U7.19, X6.9
SPI_CLK: U7.24, X6.3
SPI_CS1: R48.2, U7.22, X6.6
SPI_RESET: U7.20, X6.10
SPI_SDI: U7.21, X6.4
SPI_SDO: U7.25, X6.5
SR_CLK: U7.17, U8.11, U9.11, U10.11
SR_LAT: U7.12, U8.12, U9.12, U10.12
SR_SER: U7.16, U8.14
XB0: D1.2, D2.1, J2.7
XB1: D1.1, D2.2, J2.8
XB2: D3.2, D4.1, J2.9
XB3: D3.1, D4.2, J2.10
XB4: D5.2, D6.1, J2.11
XB5: D5.1, D6.2, J2.12
XB6: D7.2, D8.1, J2.13
XB7: D7.1, D8.2, J2.14
XT0,4: J2.6, R51.2
XT1,5: J2.5, R22.1
XT2,6: J2.4, R23.1
XT3,7: J2.3, R24.1
YL0: D9.1, D10.2, J1.3
YL1: D9.2, D10.1, J1.4
YL2: D11.1, D12.2, J1.5
YL3: D11.2, D12.1, J1.6
YL4: J1.7, R25.1
YL5: J1.8, R26.1

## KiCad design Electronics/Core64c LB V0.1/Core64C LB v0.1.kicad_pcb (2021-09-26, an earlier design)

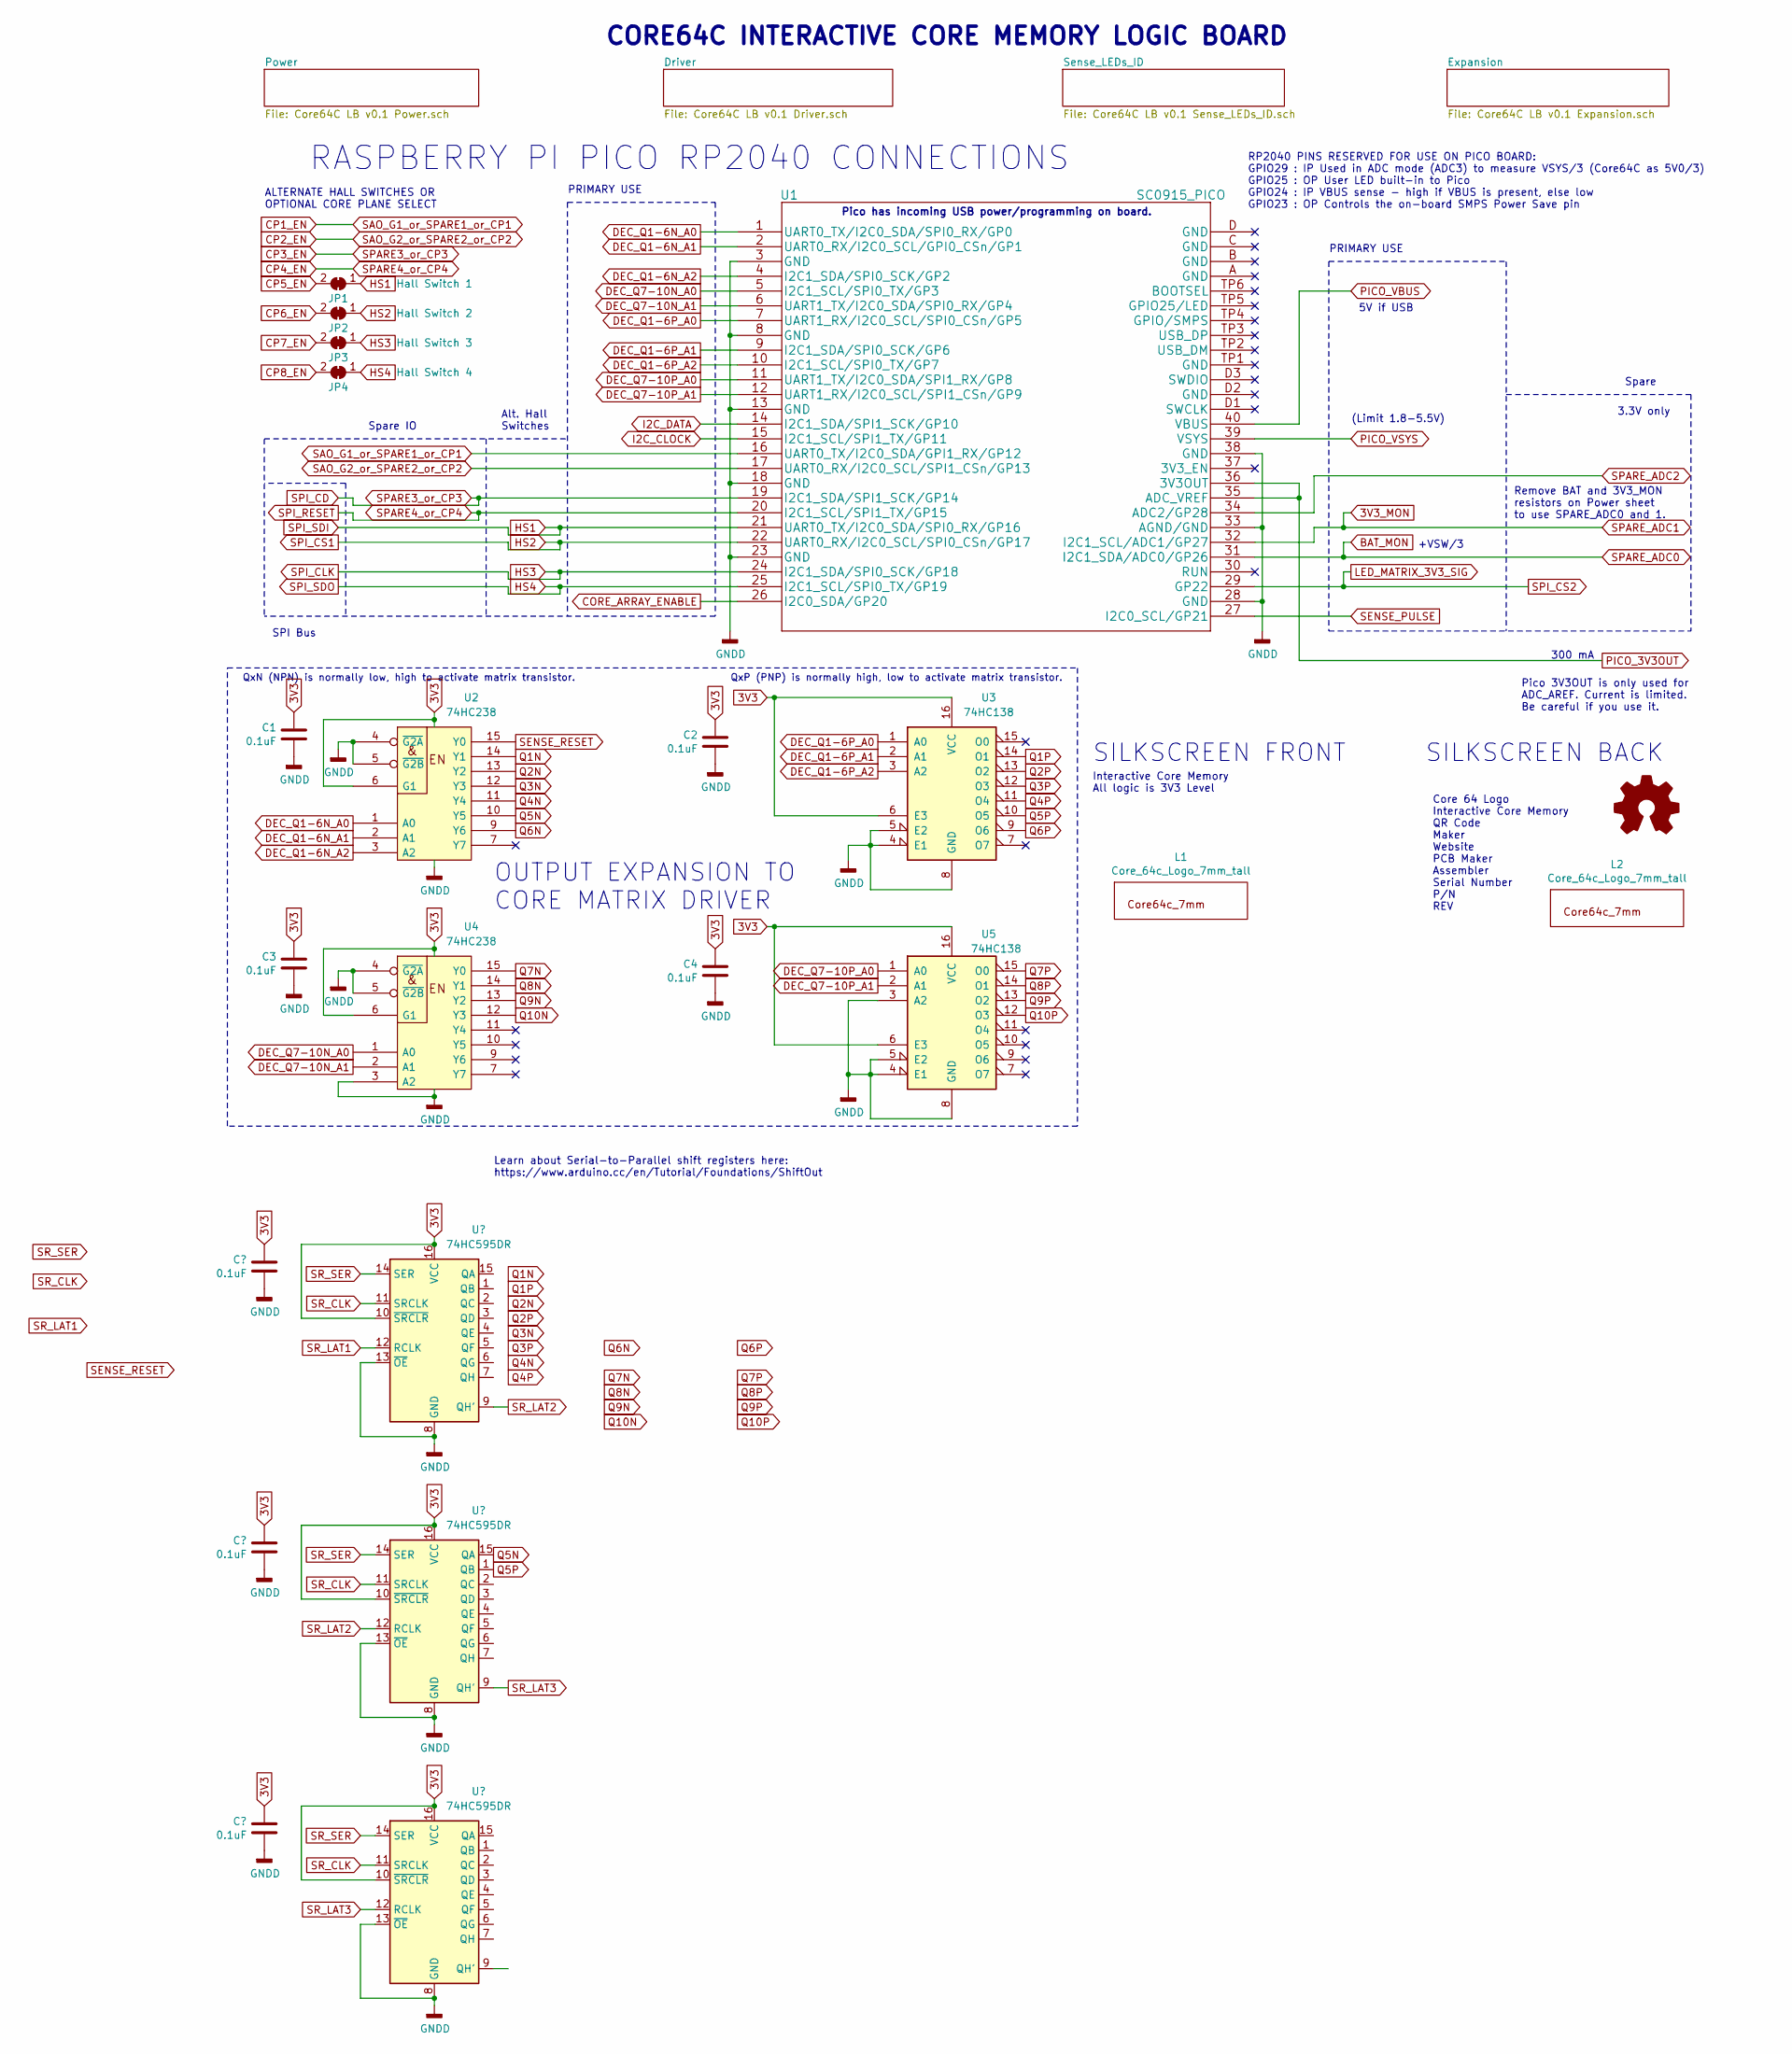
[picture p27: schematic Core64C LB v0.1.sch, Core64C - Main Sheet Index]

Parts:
C1, C2, C3, C4: 0.1uF; C_0805_2012Metric
JP1: Hall Switch 1; SolderJumper-2_P1.3mm_Bridged_RoundedPad1.0x1.5mm
JP2: Hall Switch 2; SolderJumper-2_P1.3mm_Bridged_RoundedPad1.0x1.5mm
JP3: Hall Switch 3; SolderJumper-2_P1.3mm_Bridged_RoundedPad1.0x1.5mm
JP4: Hall Switch 4; SolderJumper-2_P1.3mm_Bridged_RoundedPad1.0x1.5mm
L1, L2: Core_64c_Logo_7mm_tall; Core64c_Logo_7mm
L3: Logo_Open_Hardware_Small; OSHW-Logo2_7.3x6mm_SilkScreen
U1: SC0915_PICO; Pico_SC0915_THRUHOLE_CUTOUTS
U2, U4: 74HC238; SOIC-16_W3.90mm
U3, U5: 74HC138; SOIC-16_W3.90mm

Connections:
3V3: C1.1, C2.1, C3.1, C4.1, U2.6 (G1), U2.16 (VCC), U3.6 (_), U3.16 (VCC), U4.6 (G1), U4.16 (VCC), U5.6 (E3), U5.16 (VCC); also elsewhere on the board
3V3_MON: U1.32 (I2C1_SCL/ADC1/GP27); also elsewhere on the board
-BATT: C1.2, C2.2, C3.2, C4.2, U1.3 (GND), U1.8 (GND), U1.13 (GND), U1.18 (GND), U1.23 (GND), U1.28 (GND), U1.33 (AGND/GND), U1.38 (GND), U2.4 (~G2A), U2.5 (~G2B), U2.8 (GND), U3.4 (V-), U3.5 (+), U3.8 (V+), U4.3 (A2), U4.4 (~G2A), U4.5 (~G2B), U4.8 (GND), U5.3 (A2), U5.4 (E1), U5.5 (E2), U5.8 (GND); also elsewhere on the board
BAT_MON: U1.31 (I2C1_SDA/ADC0/GP26); also elsewhere on the board
CORE_ARRAY_ENABLE: U1.26 (I2C0_SDA/GP20); also elsewhere on the board
CP1_EN: U1.16 (UART0_TX/I2C0_SDA/GPI1_RX/GP12); also elsewhere on the board
CP2_EN: U1.17 (UART0_RX/I2C0_SCL/SPI1_CSn/GP13); also elsewhere on the board
CP3_EN: U1.19 (I2C1_SDA/SPI1_SCK/GP14); also elsewhere on the board
CP4_EN: U1.20 (I2C1_SCL/SPI1_TX/GP15); also elsewhere on the board
CP5_EN: JP1.2 (B); also elsewhere on the board
CP6_EN: JP2.2 (B); also elsewhere on the board
CP7_EN: JP3.2 (B); also elsewhere on the board
CP8_EN: JP4.2 (B); also elsewhere on the board
DEC_Q1-6N_A0: U1.1 (UART0_TX/I2C0_SDA/SPI0_RX/GP0), U2.1 (A0)
DEC_Q1-6N_A1: U1.2 (UART0_RX/I2C0_SCL/GPI0_CSn/GP1), U2.2 (A1)
DEC_Q1-6N_A2: U1.4 (I2C1_SDA/SPI0_SCK/GP2), U2.3 (A2)
DEC_Q7-10N_A0: U1.5 (I2C1_SCL/SPI0_TX/GP3), U4.1 (A0)
DEC_Q7-10N_A1: U1.6 (UART1_TX/I2C0_SDA/SPI0_RX/GP4), U4.2 (A1)
DEC_Q7-10P_A0: U1.11 (UART1_TX/I2C0_SDA/SPI1_RX/GP8), U5.1 (A0)
DEC_Q7-10P_A1: U1.12 (UART1_RX/I2C0_SCL/SPI1_CSn/GP9), U5.2 (A1)
HS1: JP1.1 (A), U1.21 (UART0_TX/I2C0_SDA/SPI0_RX/GP16); also elsewhere on the board
HS2: JP2.1 (A), U1.22 (UART0_RX/I2C0_SCL/SPI0_CSn/GP17); also elsewhere on the board
HS3: JP3.1 (A), U1.24 (I2C1_SDA/SPI0_SCK/GP18); also elsewhere on the board
HS4: JP4.1 (A), U1.25 (I2C1_SCL/SPI0_TX/GP19); also elsewhere on the board
I2C_CLOCK: U1.15 (I2C1_SCL/SPI1_TX/GP11); also elsewhere on the board
I2C_DATA: U1.14 (I2C1_SDA/SPI1_SCK/GP10); also elsewhere on the board
LED_MATRIX_3V3_SIG: U1.29 (GP22); also elsewhere on the board
PICO_3V3OUT: U1.35 (ADC_VREF), U1.36 (3V3OUT); also elsewhere on the board
PICO_VBUS: U1.40 (VBUS); also elsewhere on the board
PICO_VSYS: U1.39 (VSYS); also elsewhere on the board
Q1N: U2.14 (Y1); also elsewhere on the board
Q1P: U3.14 (O1); also elsewhere on the board
Q2N: U2.13 (Y2); also elsewhere on the board
Q2P: U3.13 (O2); also elsewhere on the board
Q3N: U2.12 (Y3); also elsewhere on the board
Q3P: U3.12 (O3); also elsewhere on the board
Q4N: U2.11 (Y4); also elsewhere on the board
Q4P: U3.11 (O4); also elsewhere on the board
Q5N: U2.10 (Y5); also elsewhere on the board
Q5P: U3.10 (O5); also elsewhere on the board
Q6N: U2.9 (Y6); also elsewhere on the board
Q6P: U3.9 (O6); also elsewhere on the board
Q7N: U4.15 (Y0); also elsewhere on the board
Q7P: U5.15 (O0); also elsewhere on the board
Q8N: U4.14 (Y1); also elsewhere on the board
Q8P: U5.14 (O1); also elsewhere on the board
Q9N: U4.13 (Y2); also elsewhere on the board
Q9P: U5.13 (O2); also elsewhere on the board
Q10N: U4.12 (Y3); also elsewhere on the board
Q10P: U5.12 (O3); also elsewhere on the board
SENSE_PULSE: U1.27 (I2C0_SCL/GP21); also elsewhere on the board
SENSE_RESET: U2.15 (Y0); also elsewhere on the board
SPARE_ADC2: U1.34 (ADC2/GP28); also elsewhere on the board

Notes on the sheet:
CORE64C INTERACTIVE CORE MEMORY LOGIC BOARD
+VSW/3
Pico has incoming USB power/programming on board.
RASPBERRY PI PICO RP2040 CONNECTIONS
Pico 3V3OUT is only used for ADC_AREF. Current is limited. Be careful if you use it.
PRIMARY USE
SILKSCREEN BACK
SILKSCREEN FRONT
Core 64 Logo Interactive Core Memory QR Code Maker Website PCB Maker Assembler Serial Number P/N REV
Interactive Core Memory All logic is 3V3 Level
Spare
Spare IO
SPI Bus
QxP (PNP) is normally high, low to activate matrix transistor.
OUTPUT EXPANSION TO CORE MATRIX DRIVER
RP2040 PINS RESERVED FOR USE ON PICO BOARD: GPIO29 : IP Used in ADC mode (ADC3) to measure VSYS/3 (Core64C as 5V0/3) GPIO25 : OP User LED built-in to Pico GPIO24 : IP VBUS sense - high if VBUS is present, else low GPIO23 : OP Controls the on-board SMPS Power Save pin
Alt. Hall Switches
3.3V only
300 mA
5V if USB
(Limit 1.8-5.5V)
QxN (NPN) is normally low, high to activate matrix transistor.
Remove BAT and 3V3_MON resistors on Power sheet to use SPARE_ADC0 and 1.
ALTERNATE HALL SWITCHES OR OPTIONAL CORE PLANE SELECT
Learn about Serial-to-Parallel shift registers here: https://www.arduino.cc/en/Tutorial/Foundations/ShiftOut

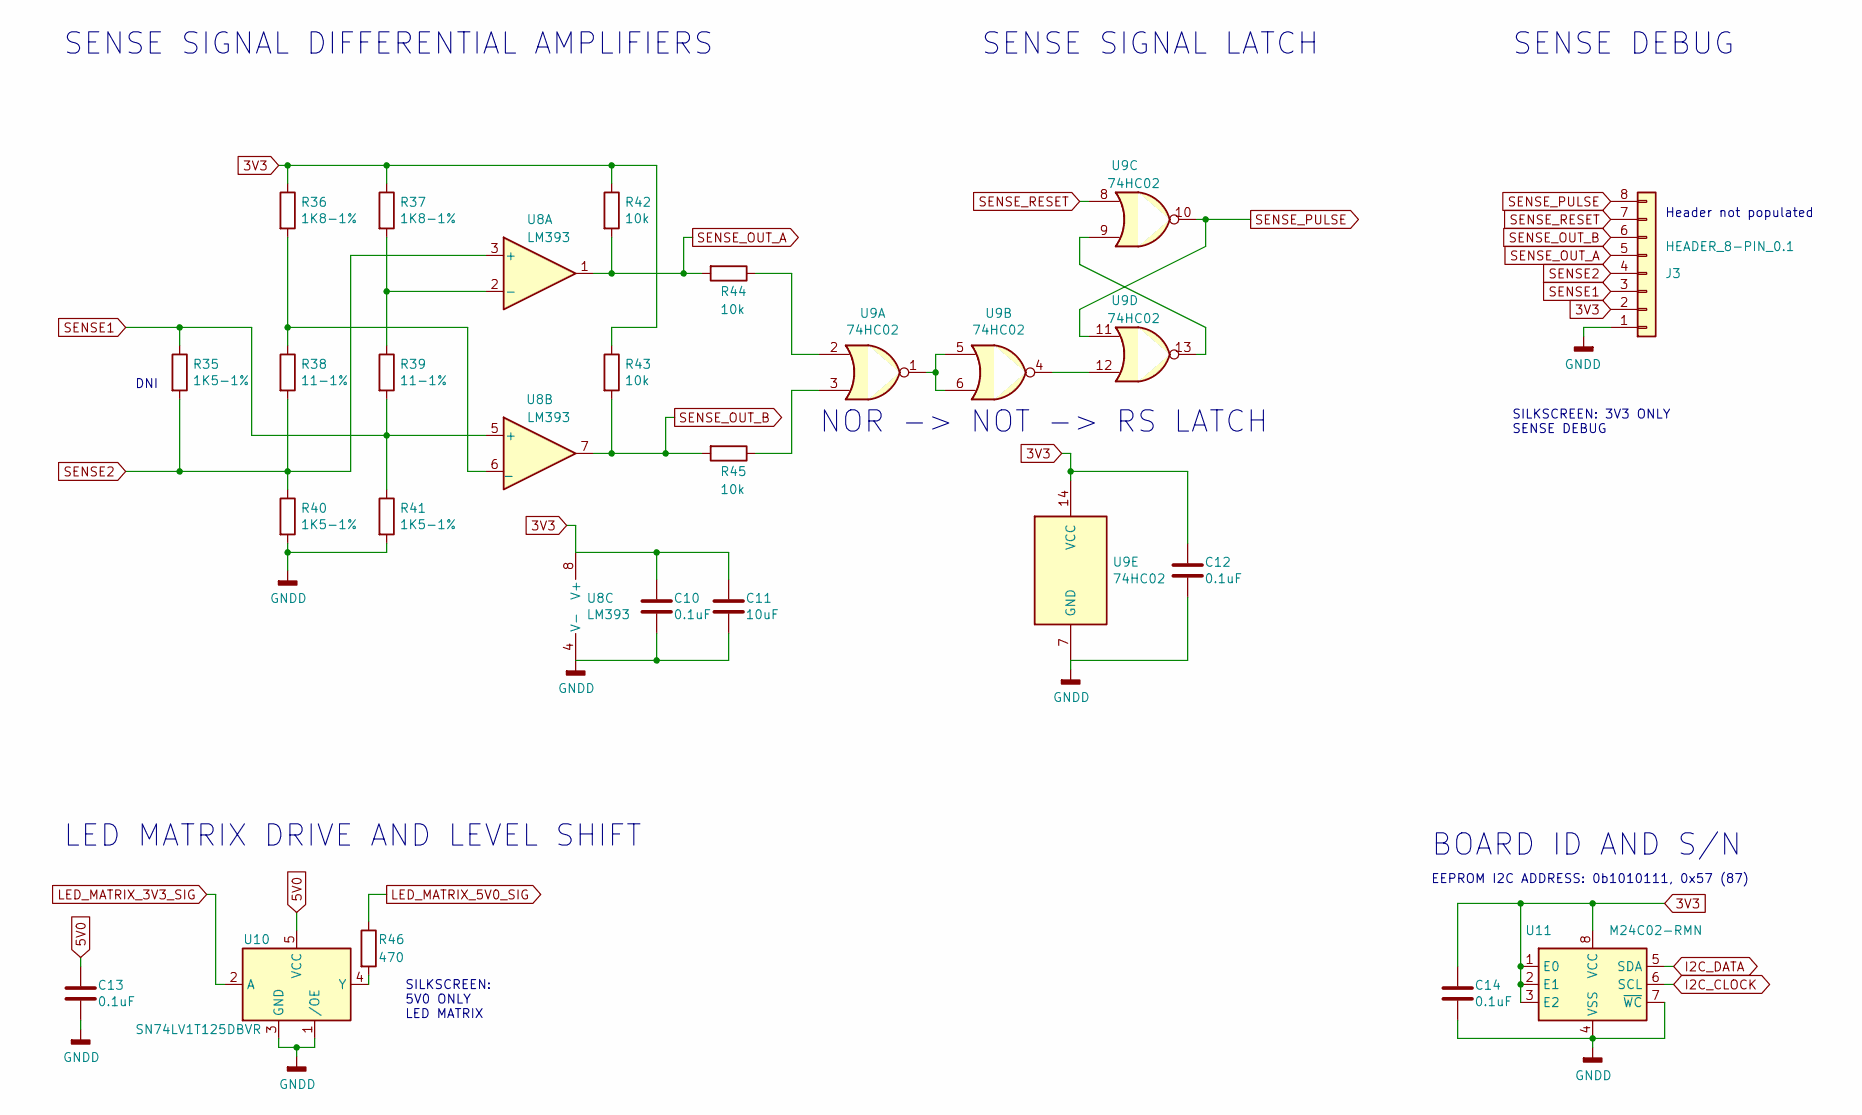
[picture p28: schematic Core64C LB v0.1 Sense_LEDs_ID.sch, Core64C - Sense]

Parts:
C10, C12, C13, C14: 0.1uF; C_0805_2012Metric
C11: 10uF; C_0805_2012Metric
J3: HEADER_8-PIN_0.1; PinSocket_1x08_P2.54mm_Vertical
R35, R40, R41: 1K5-1%; R_0805_2012Metric
R36, R37: 1K8-1%; R_0805_2012Metric
R38, R39: 11-1%; R_0805_2012Metric
R42, R43, R44, R45: 10k; R_0805_2012Metric
R46: 470; R_0805_2012Metric
U3, U8: LM393; SOIC-8_W3.9mm
U9: 74HC02; SOIC-14_3.9x8.7mm_P1.27mm
U10: SN74LV1T125DBVR; SOT-23-5; LCSC C473338
U11: M24C02-RMN; SOIC-8_3.9x4.9mm_P1.27mm

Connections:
3V3: C10.1, C11.1, C12.1, C14.1, J3.2, R36.1, R37.1, R42.1, R43.1, U8.8 (V+), U9.14 (VCC), U11.1 (E0), U11.2 (E1), U11.3 (E2), U11.8 (VCC); also elsewhere on the board
5V0: C13.1, U10.5 (VCC); also elsewhere on the board
-BATT: C10.2, C11.2, C12.2, C13.2, C14.2, J3.1, R40.2, R41.2, U8.4 (V-), U9.7 (GND), U10.1 (/OE), U10.3 (GND), U11.4 (VSS), U11.7 (~WC); also elsewhere on the board
I2C_CLOCK: U11.6 (SCL); also elsewhere on the board
I2C_DATA: U11.5 (SDA); also elsewhere on the board
LED_MATRIX_3V3_SIG: U10.2 (A); also elsewhere on the board
LED_MATRIX_5V0_SIG: R46.1; also elsewhere on the board
unnamed: R36.2, R38.1, U8.6 (_)
unnamed: R44.1, U9.2
unnamed: R45.1, U9.3
unnamed: R46.2, U10.4 (Y)
unnamed: U9.1, U9.5, U9.6
unnamed: U9.4, U9.12
unnamed: U9.9, U9.13
SENSE1: J3.3, R35.1, R39.2, R41.1, U8.5 (+); also elsewhere on the board
SENSE_OUT_B: J3.6, R43.2, R45.2, U8.7
SENSE_PULSE: J3.8, U9.10, U9.11; also elsewhere on the board
SENSE_RESET: J3.7, U9.8; also elsewhere on the board

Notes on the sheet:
SENSE SIGNAL DIFFERENTIAL AMPLIFIERS
DNI
SENSE SIGNAL LATCH
SENSE DEBUG
SILKSCREEN: 3V3 ONLY SENSE DEBUG
NOR -> NOT -> RS LATCH
LED MATRIX DRIVE AND LEVEL SHIFT
SILKSCREEN: 5V0 ONLY LED MATRIX
BOARD ID AND S/N
EEPROM I2C ADDRESS: 0b1010111, 0x57 (87)
Header not populated

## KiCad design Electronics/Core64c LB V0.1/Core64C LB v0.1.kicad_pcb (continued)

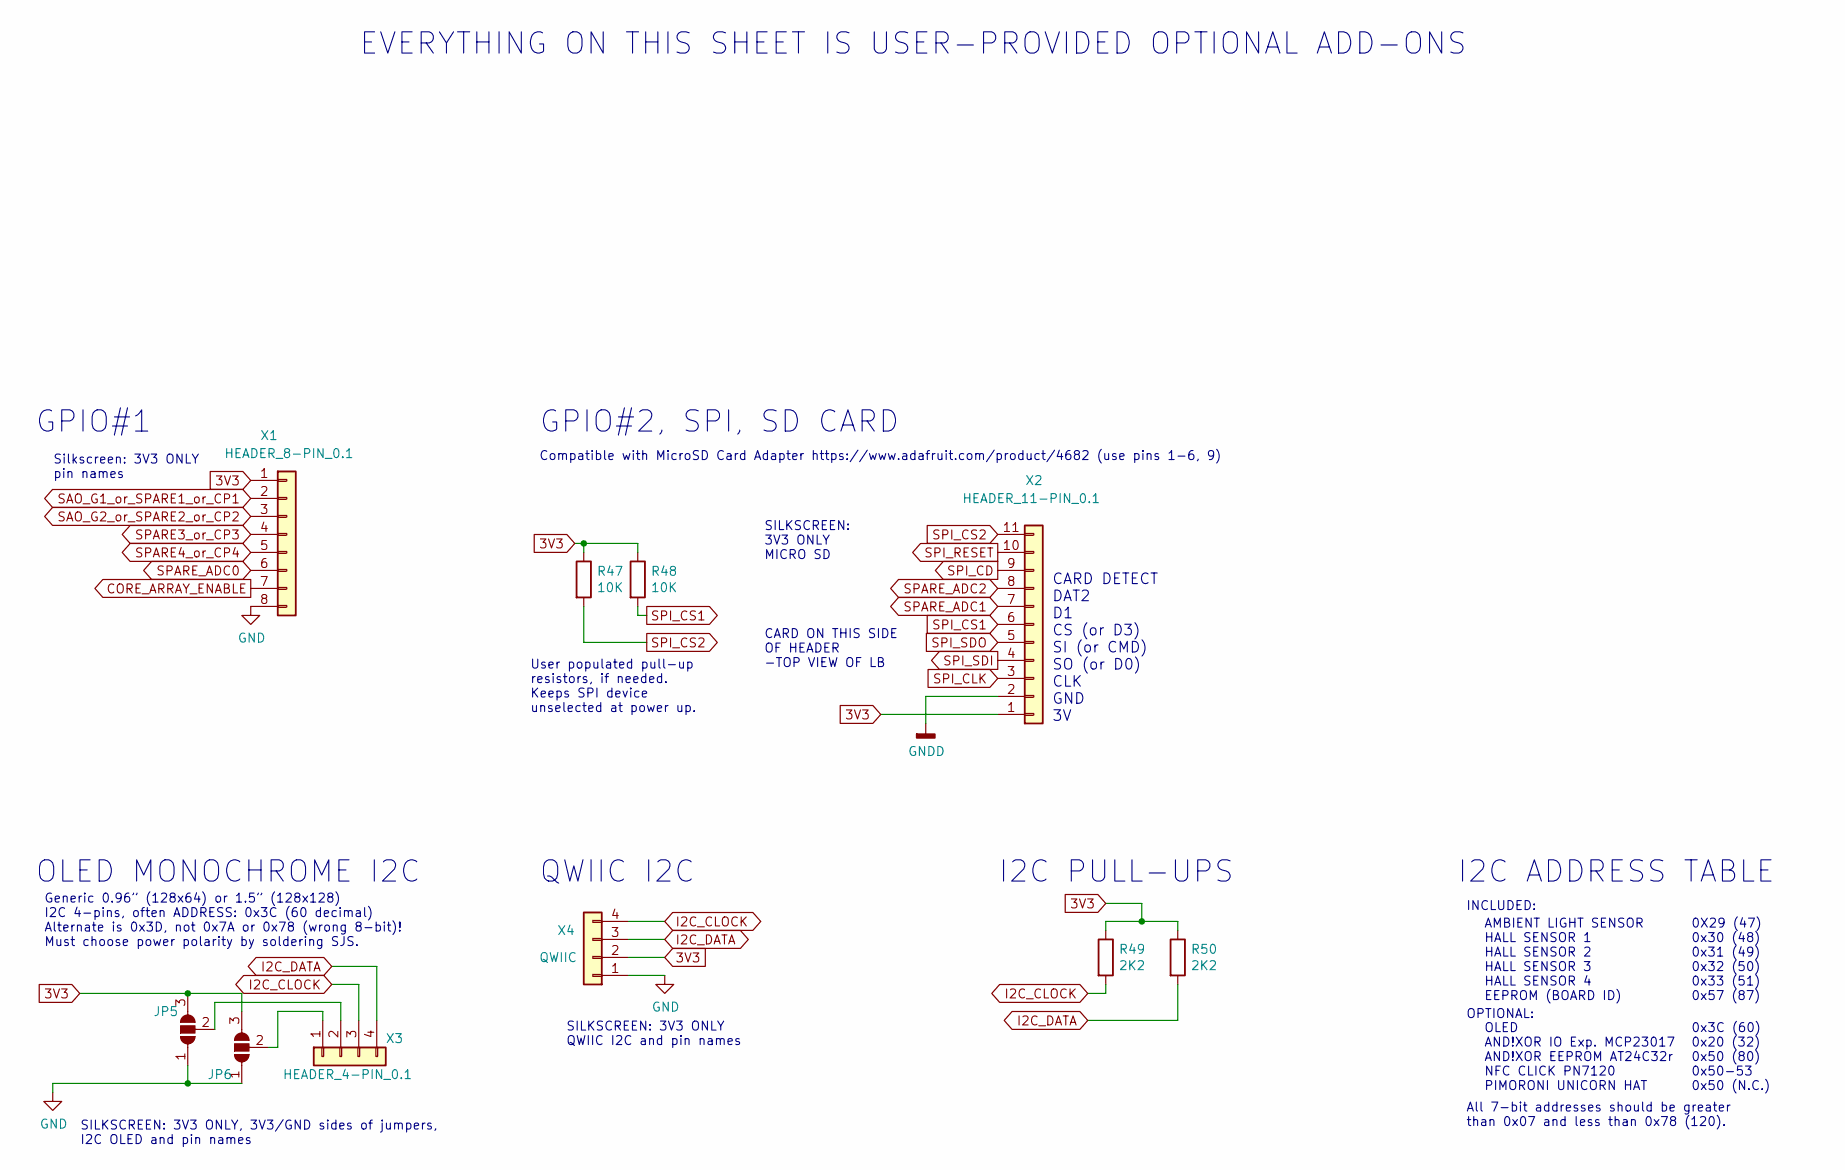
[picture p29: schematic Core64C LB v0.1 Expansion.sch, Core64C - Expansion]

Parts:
JP5, JP6: SolderJumper_3_Open; SolderJumper-3_P1.3mm_Open_Pad1.0x1.5mm_NumberLabels
R47, R48: 10K; R_0805_2012Metric
R49, R50: 2K2; R_0805_2012Metric
X1: HEADER_8-PIN_0.1; PinSocket_1x08_P2.54mm_Vertical
X2: HEADER_11-PIN_0.1; PinSocket_1x11_P2.54mm_Vertical
X3: HEADER_4-PIN_0.1; PinSocket_1x04_P2.54mm_Vertical
X4: QWIIC; JST_SH_SM04B-SRSS-TB_1x04-1MP_P1.00mm_Horizontal

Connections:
3V3: JP5.3 (B), JP6.3 (B), R47.1, R48.1, R49.1, R50.1, X1.1, X2.1, X4.2; also elsewhere on the board
3V3_MON: X2.7; also elsewhere on the board
-BATT: JP5.1 (A), JP6.1 (A), X1.8, X2.2, X4.1; also elsewhere on the board
BAT_MON: X1.6; also elsewhere on the board
CORE_ARRAY_ENABLE: X1.7; also elsewhere on the board
CP1_EN: X1.2; also elsewhere on the board
CP2_EN: X1.3; also elsewhere on the board
CP3_EN: X1.4, X2.9; also elsewhere on the board
CP4_EN: X1.5, X2.10; also elsewhere on the board
HS1: X2.4; also elsewhere on the board
HS2: R48.2, X2.6; also elsewhere on the board
HS3: X2.3; also elsewhere on the board
HS4: X2.5; also elsewhere on the board
I2C_CLOCK: R49.2, X3.3, X4.4; also elsewhere on the board
I2C_DATA: R50.2, X3.4, X4.3; also elsewhere on the board
LED_MATRIX_3V3_SIG: R47.2, X2.11; also elsewhere on the board
unnamed: JP5.2 (C), X3.2
unnamed: JP6.2 (C), X3.1
SPARE_ADC2: X2.8; also elsewhere on the board

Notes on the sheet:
OLED MONOCHROME I2C
Generic 0.96” (128x64) or 1.5” (128x128) I2C 4-pins, often ADDRESS: 0x3C (60 decimal) Alternate is 0x3D, not 0x7A or 0x78 (wrong 8-bit)! Must choose power polarity by soldering SJS.
QWIIC I2C
SILKSCREEN: 3V3 ONLY, 3V3/GND sides of jumpers, I2C OLED and pin names
Silkscreen: 3V3 ONLY pin names
GPIO#1
EVERYTHING ON THIS SHEET IS USER-PROVIDED OPTIONAL ADD-ONS
SILKSCREEN: 3V3 ONLY QWIIC I2C and pin names
All 7-bit addresses should be greater than 0x07 and less than 0x78 (120).
AMBIENT LIGHT SENSOR HALL SENSOR 1 HALL SENSOR 2 HALL SENSOR 3 HALL SENSOR 4 EEPROM (BOARD ID)
0X29 (47) 0x30 (48) 0x31 (49) 0x32 (50) 0x33 (51) 0x57 (87)
INCLUDED:
OPTIONAL:
OLED AND!XOR IO Exp. MCP23017 AND!XOR EEPROM AT24C32r NFC CLICK PN7120 PIMORONI UNICORN HAT
0x3C (60) 0x20 (32) 0x50 (80) 0x50-53 0x50 (N.C.)
I2C ADDRESS TABLE
I2C PULL-UPS
GPIO#2, SPI, SD CARD
Compatible with MicroSD Card Adapter https://www.adafruit.com/product/4682 (use pins 1-6, 9)
SILKSCREEN: 3V3 ONLY MICRO SD
CARD ON THIS SIDE OF HEADER -TOP VIEW OF LB
CARD DETECT DAT2 D1 CS (or D3) SI (or CMD) SO (or D0) CLK GND 3V
User populated pull-up resistors, if needed. Keeps SPI device unselected at power up.

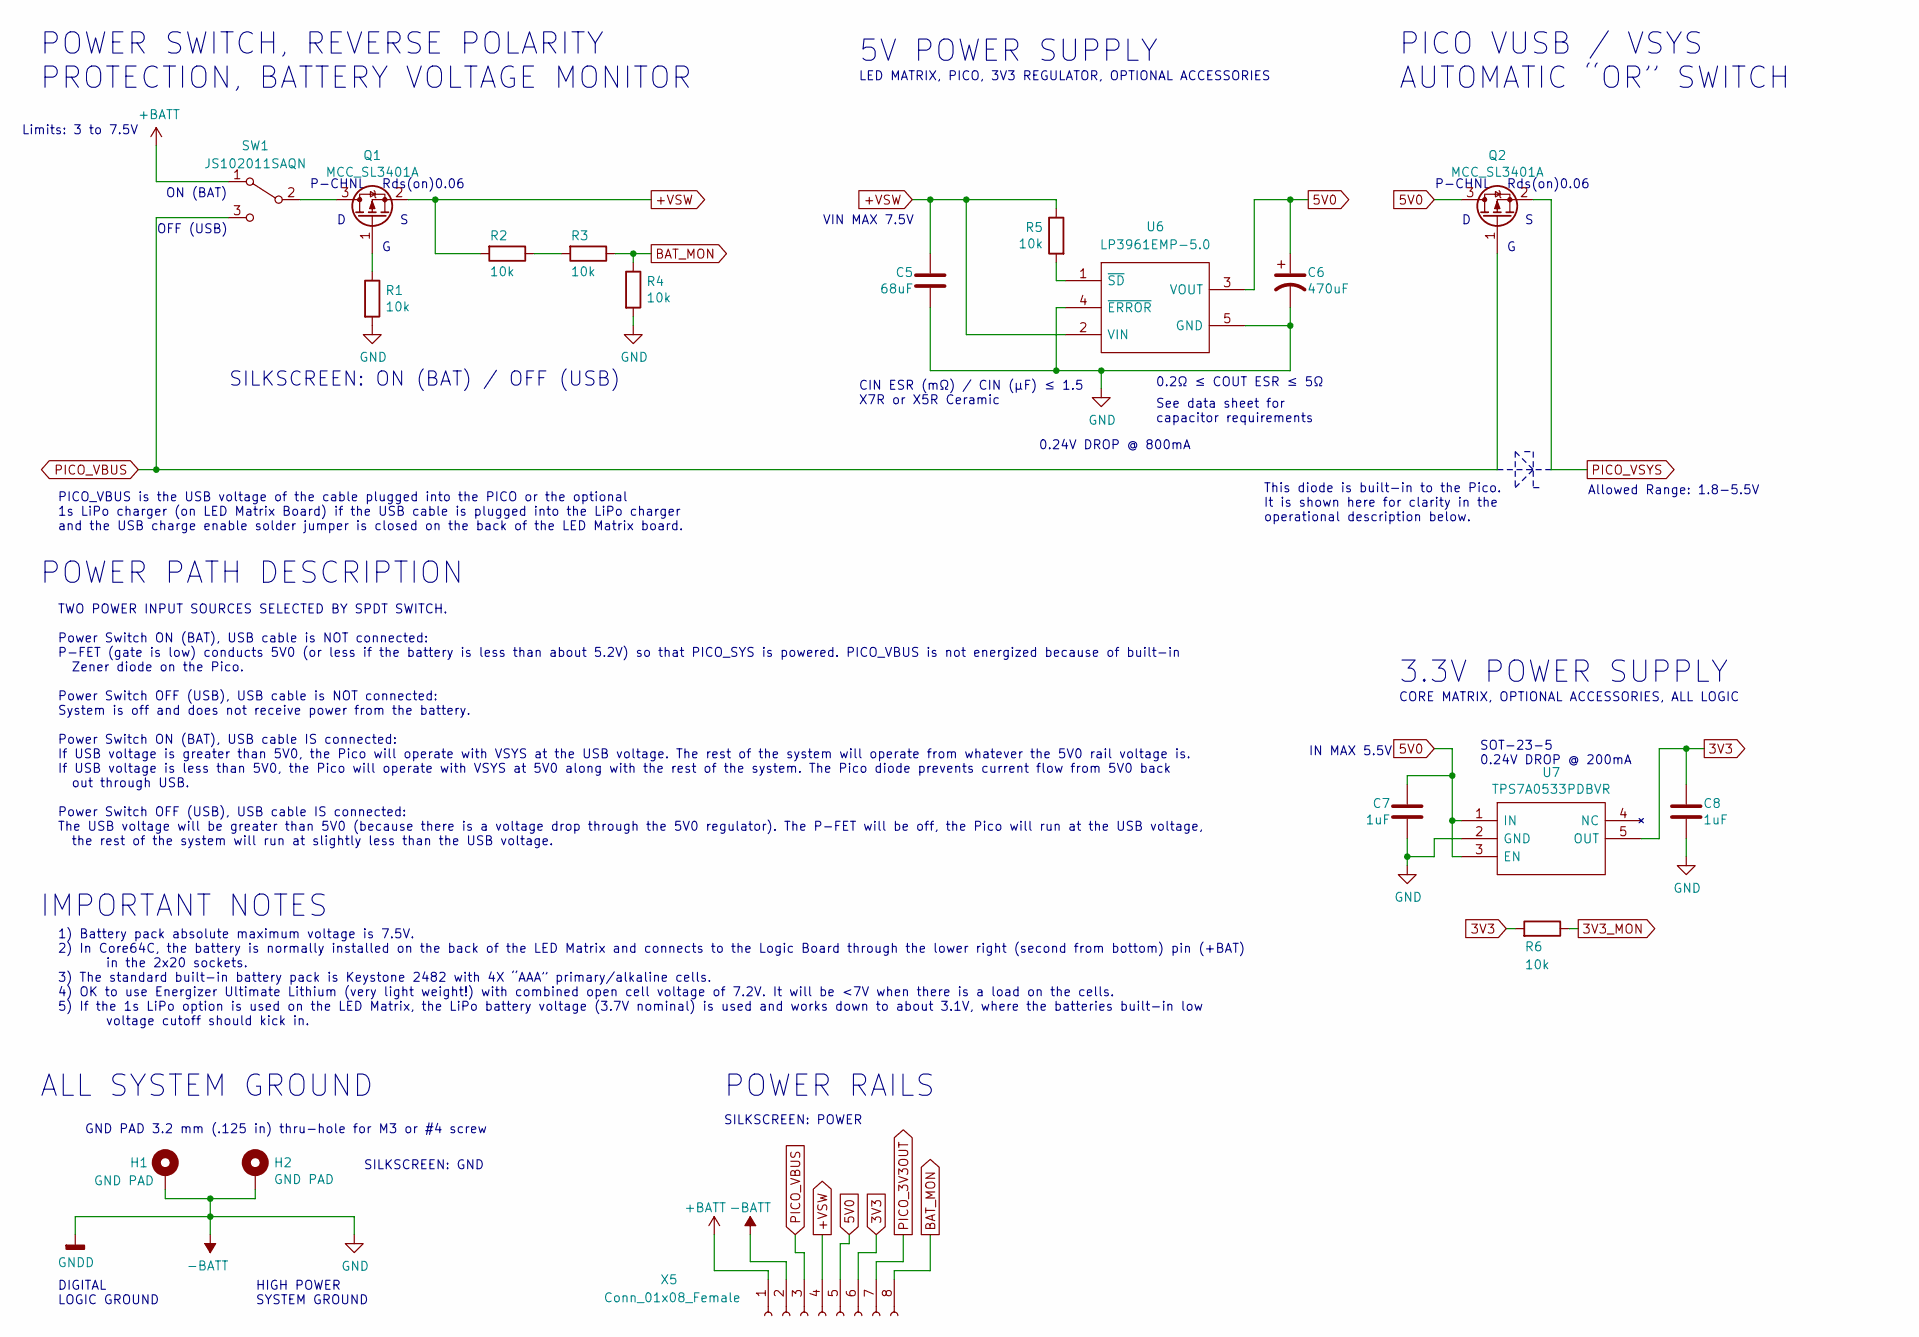
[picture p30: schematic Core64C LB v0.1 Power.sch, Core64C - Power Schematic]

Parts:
C5: 68uF; C_1206_3216Metric
C6: 470uF; CP_Elec_6.3x7.7; Digi-Key_PN 565-EMHL100ARA471MHA0GCT-ND
C7, C8: 1uF; C_0805_2012Metric
H1, H2: GND PAD; MountingHole_3.2mm_M3_Pad_Via
Q1, Q2: MCC_SL3401A; SOT-23-3; LCSC C350311
R1, R2, R3, R4, R5, R6: 10k; R_0805_2012Metric
SW1: JS102011SAQN; SW_SPDT_CK-JS102011SAQN_Core64_Recessed
U6: LP3961EMP-5.0; SOT150P696X180-5N; Manufacturer_Part_Number LP3961EMP-5.0; Mouser Part Number 926-LP3961EMP-50
U7: TPS7A0533PDBVR; SOT95P280X145-5N; Manufacturer_Part_Number TPS7A0533PDBVR; Mouser Part Number 595-TPS7A0533PDBVR
X5: Conn_01x08_Female; PinSocket_1x08_P2.54mm_Vertical

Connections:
3V3: C8.1, R6.2, U7.5 (OUT), X5.6; also elsewhere on the board
3V3_MON: R6.1; also elsewhere on the board
5V0: C6.1, C7.1, Q2.3 (D), U6.3 (VOUT), U7.1 (IN), U7.3 (EN), X5.5; also elsewhere on the board
+BATT: SW1.1 (A), X5.1; also elsewhere on the board
+VSW: C5.1, Q1.2 (S), R2.2, R5.1, U6.2 (VIN), X5.4
-BATT: C5.2, C6.2, C7.2, C8.2, H1.1, H2.1, R1.2, R4.2, U6.4 (~ERROR), U6.5 (GND), U7.2 (GND), X5.2; also elsewhere on the board
BAT_MON: R3.1, R4.1, X5.8; also elsewhere on the board
unnamed: Q1.1 (G), R1.1
unnamed: Q1.3 (D), SW1.2 (B)
unnamed: R2.1, R3.2
unnamed: R5.2, U6.1 (~SD)
PICO_3V3OUT: X5.7; also elsewhere on the board
PICO_VBUS: Q2.1 (G), SW1.3 (C), X5.3; also elsewhere on the board
PICO_VSYS: Q2.2 (S); also elsewhere on the board

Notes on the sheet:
CORE MATRIX, OPTIONAL ACCESSORIES, ALL LOGIC
POWER SWITCH, REVERSE POLARITY PROTECTION, BATTERY VOLTAGE MONITOR
3.3V POWER SUPPLY
LED MATRIX, PICO, 3V3 REGULATOR, OPTIONAL ACCESSORIES
ALL SYSTEM GROUND
POWER RAILS
HIGH POWER SYSTEM GROUND
DIGITAL LOGIC GROUND
SILKSCREEN: ON (BAT) / OFF (USB)
5V POWER SUPPLY
P-CHNL
SOT-23-5 0.24V DROP @ 200mA
CIN ESR (mΩ) / CIN (μF) ≤ 1.5 X7R or X5R Ceramic
0.2Ω ≤ COUT ESR ≤ 5Ω
See data sheet for capacitor requirements
GND PAD 3.2 mm (.125 in) thru-hole for M3 or #4 screw
SILKSCREEN: GND
SILKSCREEN: POWER
ON (BAT)
OFF (USB)
Rds(on)0.06
VIN MAX 7.5V
0.24V DROP @ 800mA
IN MAX 5.5V
Allowed Range: 1.8-5.5V
TWO POWER INPUT SOURCES SELECTED BY SPDT SWITCH. Power Switch ON (BAT), USB cable is NOT connected: P-FET (gate is low) conducts 5V0 (or less if the battery is less than about 5.2V) so that PICO_SYS is powered. PICO_VBUS is not energized because of built-in Zener diode on the Pico. Power Switch OFF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
PICO VUSB / VSYS AUTOMATIC “OR” SWITCH
This diode is built-in to the Pico. It is shown here for clarity in the operational description below.
PICO_VBUS is the USB voltage of the cable plugged into the PICO or the optional 1s LiPo charger (on LED Matrix Board) if the USB cable is plugged into the LiPo charger and the USB charge enable solder jumper is closed on the back of the LED Matrix board.
POWER PATH DESCRIPTION
1) Battery pack absolute maximum voltage is 7.5V. 2) In Core64C, the battery is normally installed on the back of the LED Matrix and connects to the Logic Board through the lower right (second from bottom) pin (+BAT) in the 2x20 sockets. 3) The standard built-in battery pack is Keystone 2482 with 4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
IMPORTANT NOTES
Limits: 3 to 7.5V


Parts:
C9: 470uF; CP_Elec_6.3x7.7; Digi-Key_PN 565-EMHL100ARA471MHA0GCT-ND
D1, D3, D5, D7, D9, D11: BAT54AW; SOT-323_SC-70
D2, D4, D6, D8, D10, D12: BAT54CW; SOT-323_SC-70
J1, J2: HDR100IMP40F-G-V-TH; PinSocket_1x20_P2.54mm_Vertical
Q3: Q_NMOS_DGS_NVTR4503NT1G; SOT-23-3; LCSC C184182
Q4, Q6, Q8, Q10, Q12, Q14, Q16, Q18, Q20, Q22: MMBT4403LT1G; SOT-23-3; MPN MMBT4403LT1G; Digi-Key_PN MMBT4403LT1GOSCT-ND
Q5, Q7, Q9, Q11, Q13, Q15, Q17, Q19, Q21, Q23: MMBT4401LT1G; SOT-23-3; MPN MMBT4401LT1G; Digi-Key_PN MMBT4401LT1GOSCT-ND
R7, R8, R9, R10, R11, R12, R13, R14, R15, R16, R17, R18, R19, R20, R21, R22, R23, R24, R25, R26, R33: 470; R_0805_2012Metric
R27, R28, R29, R30, R31, R32: 6R8-1%; R_0805_2012Metric
R34: 10k; R_0805_2012Metric

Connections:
3V3: C9.1, J1.13, Q4.2 (E), Q6.2 (E), Q8.2 (E), Q10.2 (E), Q12.2 (E), Q14.2 (E), Q16.2 (E), Q18.2 (E), Q20.2 (E), Q22.2 (E); also elsewhere on the board
5V0: J2.1; also elsewhere on the board
+BATT: J2.19; also elsewhere on the board
-BATT: C9.2, J1.14, J2.2, Q3.2 (S), R34.1; also elsewhere on the board
CORE_ARRAY_ENABLE: R33.2; also elsewhere on the board
CP1_EN: J2.15; also elsewhere on the board
CP2_EN: J2.16; also elsewhere on the board
CP3_EN: J2.17; also elsewhere on the board
CP4_EN: J2.18; also elsewhere on the board
CP5_EN: J1.18; also elsewhere on the board
CP6_EN: J1.17; also elsewhere on the board
CP7_EN: J1.16; also elsewhere on the board
CP8_EN: J1.15; also elsewhere on the board
GNDPWR: Q3.3 (D), Q5.2 (E), Q7.2 (E), Q9.2 (E), Q11.2 (E), Q13.2 (E), Q15.2 (E), Q17.2 (E), Q19.2 (E), Q21.2 (E), Q23.2 (E)
I2C_CLOCK: J1.11; also elsewhere on the board
I2C_DATA: J1.12; also elsewhere on the board
LED_MATRIX_5V0_SIG: J1.1; also elsewhere on the board
unnamed: D1.3, D3.3, Q12.3 (C)
unnamed: D2.3, D4.3, Q13.3 (C)
unnamed: D5.3, D7.3, Q14.3 (C)
unnamed: D6.3, D8.3, Q15.3 (C)
unnamed: D9.3, Q16.3 (C)
unnamed: D10.3, Q17.3 (C)
unnamed: D11.3, Q18.3 (C)
unnamed: D12.3, Q19.3 (C)
unnamed: Q3.1 (G), R33.1, R34.2
unnamed: Q4.1 (B), R7.1
unnamed: Q4.3 (C), Q5.3 (C), R27.1
unnamed: Q5.1 (B), R8.1
unnamed: Q6.1 (B), R9.1
unnamed: Q6.3 (C), Q7.3 (C), R28.2
unnamed: Q7.1 (B), R10.1
unnamed: Q8.1 (B), R11.1
unnamed: Q8.3 (C), Q9.3 (C), R29.2
unnamed: Q9.1 (B), R12.1
unnamed: Q10.1 (B), R13.1
unnamed: Q10.3 (C), Q11.3 (C), R30.2
unnamed: Q11.1 (B), R14.1
unnamed: Q12.1 (B), R15.1
unnamed: Q13.1 (B), R16.1
unnamed: Q14.1 (B), R17.1
unnamed: Q15.1 (B), R18.1
unnamed: Q16.1 (B), R19.1
unnamed: Q17.1 (B), R20.1
unnamed: Q18.1 (B), R21.1
unnamed: Q19.1 (B), R22.1
unnamed: Q20.1 (B), R23.1
unnamed: Q20.3 (C), Q21.3 (C), R31.2
unnamed: Q21.1 (B), R24.1
unnamed: Q22.1 (B), R25.1
unnamed: Q22.3 (C), Q23.3 (C), R32.2
unnamed: Q23.1 (B), R26.1
PICO_VBUS: J2.20; also elsewhere on the board
Q1N: R16.2; also elsewhere on the board
Q1P: R15.2; also elsewhere on the board
Q2N: R18.2; also elsewhere on the board
Q2P: R17.2; also elsewhere on the board
Q3N: R8.2; also elsewhere on the board
Q3P: R7.2; also elsewhere on the board
Q4N: R10.2; also elsewhere on the board
Q4P: R9.2; also elsewhere on the board
Q5N: R12.2; also elsewhere on the board
Q5P: R11.2; also elsewhere on the board
Q6N: R14.2; also elsewhere on the board
Q6P: R13.2; also elsewhere on the board
Q7N: R20.2; also elsewhere on the board
Q7P: R19.2; also elsewhere on the board
Q8N: R22.2; also elsewhere on the board
Q8P: R21.2; also elsewhere on the board
Q9N: R24.2; also elsewhere on the board
Q9P: R23.2; also elsewhere on the board
Q10N: R26.2; also elsewhere on the board
Q10P: R25.2; also elsewhere on the board
SENSE1: J1.9; also elsewhere on the board
XB0: D1.2, D2.1, J2.7
XB1: D1.1, D2.2, J2.8
XB2: D3.2, D4.1, J2.9
XB3: D3.1, D4.2, J2.10
XB4: D5.2, D6.1, J2.11
XB5: D5.1, D6.2, J2.12
XB6: D7.2, D8.1, J2.13
XB7: D7.1, D8.2, J2.14
XT0,4: J2.6, R27.2
XT1,5: J2.5, R28.1
XT2,6: J2.4, R29.1
XT3,7: J2.3, R30.1
YL0: D9.1, D10.2, J1.3
YL1: D9.2, D10.1, J1.4
YL2: D11.1, D12.2, J1.5
YL3: D11.2, D12.1, J1.6
YL4: J1.7, R31.1
YL5: J1.8, R32.1

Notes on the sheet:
COL 0,4
COL 1,5
COL 2,6
COL 0
COL 1
COL 2
COL 3
COL 4
COL 5
COL 6
COL 7
ROW 0,4 ROW 2,6
ROW 1,5 ROW 3,7
ROW 0,4
ROW 3,7
ROW 1,5
ROW 2,6
CORE MEMORY GROUND
CORE MEMORY POWER
CORE MATRIX POWER
CORE MATRIX BOTTOM COLUMN DRIVERS
CORE MATRIX TOP COLUMN DRIVERS
CORE MATRIX ROW DRIVERS
CORE MATRIX WRITE ENABLE
DIGITAL LOGIC GROUND
SYSTEM POWER GROUND
CORE BOARD INTERCONNECTS
Silkscreen: 3V3 ONLY
QxP (PNP) is normally high, low to activate matrix transistor. QxN (NPN) is normally low, high to activate matrix transistor.
N-CHNL FET as low-side switch
Rds(ON)=0.1
Drive Transistor current: 3.3/470=7mA
5VUSB if LED MATRIX USB SJ IS CLOSED ON BACK OF BOARD.
COL 3,7

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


Board: 2 copper layers, 85.0 x 85.0 mm, 130 parts (3 on the bottom side), 132 nets.

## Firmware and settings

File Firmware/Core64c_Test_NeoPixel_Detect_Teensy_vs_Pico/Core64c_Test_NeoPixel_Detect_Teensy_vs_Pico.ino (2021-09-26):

// 2021-08-05 Updated to detect board type at compile time and adjust IO map accordingly.
#include "Detect_Board.h"
#include "Hardware_IO_map.h"

// NeoPixel test program showing use of the WHITE channel for RGBW
// pixels only (won't look correct on regular RGB NeoPixel strips).

#include <Adafruit_NeoPixel.h>
#ifdef __AVR__
 #include <avr/power.h> // Required for 16 MHz Adafruit Trinket
#endif

// How many NeoPixels are attached to the Arduino?
#define LED_COUNT  64

// NeoPixel brightness, 0 (min) to 255 (max)
static uint8_t Brightness = 255; // Set BRIGHTNESS to about 1/5 (max = 255)

// Declare our NeoPixel strip object:
Adafruit_NeoPixel strip(LED_COUNT, LED_PIN, NEO_GRB + NEO_KHZ800);
// Argument 1 = Number of pixels in NeoPixel strip
// Argument 2 = Arduino pin number (most are valid)
// Argument 3 = Pixel type flags, add together as needed:
//   NEO_KHZ800  800 KHz bitstream (most NeoPixel products w/WS2812 LEDs)
//   NEO_KHZ400  400 KHz (classic 'v1' (not v2) FLORA pixels, WS2811 drivers)
//   NEO_GRB     Pixels are wired for GRB bitstream (most NeoPixel products)
//   NEO_RGB     Pixels are wired for RGB bitstream (v1 FLORA pixels, not v2)
//   NEO_RGBW    Pixels are wired for RGBW bitstream (NeoPixel RGBW products)

void setup() {
  // These lines are specifically to support the Adafruit Trinket 5V 16 MHz.
  // Any other board, you can remove this part (but no harm leaving it):
#if defined(__AVR_ATtiny85__) && (F_CPU == 16000000)
  clock_prescale_set(clock_div_1);
#endif
  // END of Trinket-specific code.

  strip.begin();           // INITIALIZE NeoPixel strip object (REQUIRED)
  strip.clear();
  strip.setBrightness(Brightness);
  strip.show();            // Turn OFF all pixels ASAP
}

void loop() {
//  SimpleTestCode();
  
  // Fill along the length of the strip in various colors...
  colorWipe(strip.Color(255,   0,   0)     , 30); // Red
  colorWipe(strip.Color(  0, 255,   0)     , 30); // Green
  colorWipe(strip.Color(  0,   0, 255)     , 30); // Blue
  colorWipe(strip.Color(255, 255, 255), 30); // RGB white

  whiteOverRainbow(50, 5);

  pulseWhite(5);

  rainbowFade2White(3, 3, 1);

}

void SimpleTestCode() {
  // https://learn.adafruit.com/adafruit-neopixel-uberguide/arduino-library-use
  static uint16_t hue = 65536/2; // 0-65535
  static uint8_t saturation = 255; // Maximum saturation
  static uint8_t value = 0; // the effective brightness for dynamic brightness control with Neopixels library
  for(int i=0; i<strip.numPixels(); i++) { // For each pixel in strip...
    // strip.setPixelColor(i, 20,10,10);         //  Set pixel's color (in RAM) pixel #, red, green, blue
//    strip.setPixelColor( i, strip.Color(strip.gamma8(hue),strip.gamma8(saturation),strip.gamma8(value) ));  //  Set pixel's color (in RAM) pixel #, hue, saturation, brightness
    strip.setPixelColor( i, strip.gamma32(strip.ColorHSV(hue,saturation,value)) );  //  Set pixel's color (in RAM) pixel #, hue, saturation, brightness
    strip.show();                          //  Update strip to match
    //delay(5);                             //  Pause for a moment
  }
  value++;
}




// Fill strip pixels one after another with a color. Strip is NOT cleared
// first; anything there will be covered pixel by pixel. Pass in color
// (as a single 'packed' 32-bit value, which you can get by calling
// strip.Color(red, green, blue) as shown in the loop() function above),
// and a delay time (in milliseconds) between pixels.
void colorWipe(uint32_t color, int wait) {
  for(int i=0; i<strip.numPixels(); i++) { // For each pixel in strip...
    strip.setPixelColor(i, color);         //  Set pixel's color (in RAM)
    strip.show();                          //  Update strip to match
    delay(wait);                           //  Pause for a moment
  }
}

void whiteOverRainbow(int whiteSpeed, int whiteLength) {

  if(whiteLength >= strip.numPixels()) whiteLength = strip.numPixels() - 1;

  int      head          = whiteLength - 1;
  int      tail          = 0;
  int      loops         = 3;
  int      loopNum       = 0;
  uint32_t lastTime      = millis();
  uint32_t firstPixelHue = 0;

  for(;;) { // Repeat forever (or until a 'break' or 'return')
    for(int i=0; i<strip.numPixels(); i++) {  // For each pixel in strip...
      if(((i >= tail) && (i <= head)) ||      //  If between head & tail...
         ((tail > head) && ((i >= tail) || (i <= head)))) {
        strip.setPixelColor(i, strip.Color(255,255,255)); // Set white
      } else {                                             // else set rainbow
        int pixelHue = firstPixelHue + (i * 65536L / strip.numPixels());
        strip.setPixelColor(i, strip.gamma32(strip.ColorHSV(pixelHue)));
      }
    }

    strip.show(); // Update strip with new contents
    // There's no delay here, it just runs full-tilt until the timer and
    // counter combination below runs out.

    firstPixelHue += 40; // Advance just a little along the color wheel

    if((millis() - lastTime) > whiteSpeed) { // Time to update head/tail?
      if(++head >= strip.numPixels()) {      // Advance head, wrap around
        head = 0;
        if(++loopNum >= loops) return;
      }
      if(++tail >= strip.numPixels()) {      // Advance tail, wrap around
        tail = 0;
      }
      lastTime = millis();                   // Save time of last movement
    }
  }
}

void pulseWhite(uint8_t wait) {
  for(int j=0; j<256; j++) { // Ramp up from 0 to 255
    // Fill entire strip with white at gamma-corrected brightness level 'j':
    strip.fill(strip.Color(strip.gamma8(j), strip.gamma8(j), strip.gamma8(j)));
    strip.show();
    delay(wait);
  }

  for(int j=255; j>=0; j--) { // Ramp down from 255 to 0
    strip.fill(strip.Color(strip.gamma8(j), strip.gamma8(j), strip.gamma8(j)));
    strip.show();
    delay(wait);
  }
}

void rainbowFade2White(int wait, int rainbowLoops, int whiteLoops) {
  int fadeVal=0, fadeMax=100;

  // Hue of first pixel runs 'rainbowLoops' complete loops through the color
  // wheel. Color wheel has a range of 65536 but it's OK if we roll over, so
  // just count from 0 to rainbowLoops*65536, using steps of 256 so we
  // advance around the wheel at a decent clip.
  for(uint32_t firstPixelHue = 0; firstPixelHue < rainbowLoops*65536;
    firstPixelHue += 256) {

    for(int i=0; i<strip.numPixels(); i++) { // For each pixel in strip...

      // Offset pixel hue by an amount to make one full revolution of the
      // color wheel (range of 65536) along the length of the strip
      // (strip.numPixels() steps):
      uint32_t pixelHue = firstPixelHue + (i * 65536L / strip.numPixels());

      // strip.ColorHSV() can take 1 or 3 arguments: a hue (0 to 65535) or
      // optionally add saturation and value (brightness) (each 0 to 255).
      // Here we're using just the three-argument variant, though the
      // second value (saturation) is a constant 255.
      strip.setPixelColor(i, strip.gamma32(strip.ColorHSV(pixelHue, 255,
        255 * fadeVal / fadeMax)));
    }

    strip.show();
    delay(wait);

    if(firstPixelHue < 65536) {                              // First loop,
      if(fadeVal < fadeMax) fadeVal++;                       // fade in
    } else if(firstPixelHue >= ((rainbowLoops-1) * 65536)) { // Last loop,
      if(fadeVal > 0) fadeVal--;                             // fade out
    } else {
      fadeVal = fadeMax; // Interim loop, make sure fade is at max
    }
  }

  for(int k=0; k<whiteLoops; k++) {
    for(int j=0; j<256; j++) { // Ramp up 0 to 255
      // Fill entire strip with white at gamma-corrected brightness level 'j':
      strip.fill(strip.Color(strip.gamma8(j), strip.gamma8(j), strip.gamma8(j)));
      strip.show();
    }
    delay(100); // Pause 1 second
    for(int j=255; j>=0; j--) { // Ramp down 255 to 0
      strip.fill(strip.Color(strip.gamma8(j), strip.gamma8(j), strip.gamma8(j)));
      strip.show();
    }
  }

  delay(100); // Pause 1/2 second
}

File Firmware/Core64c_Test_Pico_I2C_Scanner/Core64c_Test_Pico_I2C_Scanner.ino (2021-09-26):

/*
Modified 2021-08-07 by Andy to work with I2C1 on Pico pins 14,15
Using the official "Arduino Mbed OS RP2040 Boards" version 2.3.1 support through Boards Manager (Not the Earle version)
To enable RP2040 I2C channel 1 as Wire (this really needs to be cleaned up by Arduino so I2C channel 0 is Wire, and Channel 1 is Wire1),
change as follows in file "pins_arduino.h" located in Macintosh HD ▸ Users ▸ ageppert ▸ Library ▸ Arduino15 ▸ packages ▸ arduino ▸ hardware ▸ mbed_rp2040 ▸ 2.3.1 ▸ variants ▸ RASPBERRY_PI_PICO
  // Wire
  #define PIN_WIRE_SDA        (10u)  // GP10 is Pico pin 14
  #define PIN_WIRE_SCL        (11u)  // GP11 is Pico pin 15
  
  // Default was:
  // #define PIN_WIRE_SDA        (6u)
  // #define PIN_WIRE_SCL        (7u)
  // See https://github.com/arduino/ArduinoCore-mbed/issues/194

*/
// --------------------------------------
// i2c_scanner
// http://playground.arduino.cc/Main/I2cScanner
//
// Version 1
//    This program (or code that looks like it)
//    can be found in many places.
//    For example on the Arduino.cc forum.
//    The original author is not know.
// Version 2, June 2012, Using Arduino 1.0.1
//     Adapted to be as simple as possible by Arduino.cc user Krodal
// Version 3, Feb 26  2013
//    V3 by louarnold
// Version 4, March 3, 2013, Using Arduino 1.0.3
//    by Arduino.cc user Krodal.
//    Changes by louarnold removed.
//    Scanning addresses changed from 0...127 to 1...119,
//    according to the i2c scanner by Nick Gammon
//    http://www.gammon.com.au/forum/?id=10896
// Version 5, March 28, 2013
//    As version 4, but address scans now to 127.
//    A sensor seems to use address 120.
// Version 6, November 27, 2015.
//    Added waiting for the Leonardo serial communication.
//
//
// This sketch tests the standard 7-bit addresses
// Devices with higher bit address might not be seen properly.
//

// 2021-08-07 Updated to detect board type at compile time and adjust IO map accordingly.
#include "Detect_Board.h"
#include "Hardware_IO_map.h"
// Nothing needed! Teensy just uses the default pins.

#include <Wire.h>

void setup() {
  // PICO
  // Default pins are 9 and 10 (GP6 and 7) if nothing is specified, 
  // unless pins_arduino.h is modified (which they are to make this work).

  // TEENSY 3.2
  // Defaults

  Wire.begin(); 
  Serial.begin(115200);
  while (!Serial);        // Leonardo: wait for serial monitor
  Serial.println(F("\nI2C Scanner"));
}


void loop() {
  byte error, address;
  int nDevices;

  Serial.println(F("Scanning..."));

  nDevices = 0;
  for (address = 1; address < 127; address++) {
    // The i2c_scanner uses the return value of
    // the Write.endTransmisstion to see if
    // a device did acknowledge to the address.
    Wire.beginTransmission(address);
    error = Wire.endTransmission();

    if (error == 0) {
      Serial.print(F("Device found at address 0x"));
      if (address < 16) {
        Serial.print("0");
      }
      Serial.print(address,HEX);
      Serial.print("  (");
      printKnownChips(address);
      Serial.println(")");

      nDevices++;
    } else if (error==4) {
      Serial.print(F("Unknown error at address 0x"));
      if (address < 16) {
        Serial.print("0");
      }
      Serial.println(address,HEX);
    }
  }
  if (nDevices == 0) {
    Serial.println(F("No I2C devices found\n"));
  } else {
    Serial.println(F("done\n"));
  }
  delay(500);           // wait 5 seconds for next scan
}


void printKnownChips(byte address)
{
  // Is this list missing part numbers for chips you use?
  // Please suggest additions here:
  // https://github.com/PaulStoffregen/Wire/issues/new
  switch (address) {
    case 0x00: Serial.print(F("AS3935")); break;
    case 0x01: Serial.print(F("AS3935")); break;
    case 0x02: Serial.print(F("AS3935")); break;
    case 0x03: Serial.print(F("AS3935")); break;
    case 0x0A: Serial.print(F("SGTL5000")); break; // MCLK required
    case 0x0B: Serial.print(F("SMBusBattery?")); break;
    case 0x0C: Serial.print(F("AK8963")); break;
    case 0x10: Serial.print(F("CS4272")); break;
    case 0x11: Serial.print(F("Si4713")); break;
    case 0x13: Serial.print(F("VCNL4000,AK4558")); break;
    case 0x18: Serial.print(F("LIS331DLH")); break;
    case 0x19: Serial.print(F("LSM303,LIS331DLH")); break;
    case 0x1A: Serial.print(F("WM8731")); break;
    case 0x1C: Serial.print(F("LIS3MDL")); break;
    case 0x1D: Serial.print(F("LSM303D,LSM9DS0,ADXL345,MMA7455L,LSM9DS1,LIS3DSH")); break;
    case 0x1E: Serial.print(F("LSM303D,HMC5883L,FXOS8700,LIS3DSH")); break;
    case 0x20: Serial.print(F("MCP23017,MCP23008,PCF8574,FXAS21002,SoilMoisture")); break;
    case 0x21: Serial.print(F("MCP23017,MCP23008,PCF8574")); break;
    case 0x22: Serial.print(F("MCP23017,MCP23008,PCF8574")); break;
    case 0x23: Serial.print(F("MCP23017,MCP23008,PCF8574")); break;
    case 0x24: Serial.print(F("MCP23017,MCP23008,PCF8574")); break;
    case 0x25: Serial.print(F("MCP23017,MCP23008,PCF8574")); break;
    case 0x26: Serial.print(F("MCP23017,MCP23008,PCF8574")); break;
    case 0x27: Serial.print(F("MCP23017,MCP23008,PCF8574,LCD16x2,DigoleDisplay")); break;
    case 0x28: Serial.print(F("BNO055,EM7180,CAP1188")); break;
    case 0x29: Serial.print(F("TSL2561,VL6180,TSL2561,TSL2591,BNO055,CAP1188")); break;
    case 0x2A: Serial.print(F("SGTL5000,CAP1188")); break;
    case 0x2B: Serial.print(F("CAP1188")); break;
    case 0x2C: Serial.print(F("MCP44XX ePot")); break;
    case 0x2D: Serial.print(F("MCP44XX ePot")); break;
    case 0x2E: Serial.print(F("MCP44XX ePot")); break;
    case 0x2F: Serial.print(F("MCP44XX ePot")); break;
    case 0x30: Serial.print(F("Si7210")); break;
    case 0x31: Serial.print(F("Si7210")); break;
    case 0x32: Serial.print(F("Si7210")); break;
    case 0x33: Serial.print(F("MAX11614,MAX11615,Si7210")); break;
    case 0x34: Serial.print(F("MAX11612,MAX11613")); break;
    case 0x35: Serial.print(F("MAX11616,MAX11617")); break;
    case 0x38: Serial.print(F("RA8875,FT6206,MAX98390")); break;
    case 0x39: Serial.print(F("TSL2561, APDS9960")); break;
    case 0x3C: Serial.print(F("SSD1306,DigisparkOLED")); break;
    case 0x3D: Serial.print(F("SSD1306")); break;
    case 0x40: Serial.print(F("PCA9685,Si7021,MS8607")); break;
    case 0x41: Serial.print(F("STMPE610,PCA9685")); break;
    case 0x42: Serial.print(F("PCA9685")); break;
    case 0x43: Serial.print(F("PCA9685")); break;
    case 0x44: Serial.print(F("PCA9685, SHT3X")); break;
    case 0x45: Serial.print(F("PCA9685, SHT3X")); break;
    case 0x46: Serial.print(F("PCA9685")); break;
    case 0x47: Serial.print(F("PCA9685")); break;
    case 0x48: Serial.print(F("ADS1115,PN532,TMP102,LM75,PCF8591")); break;
    case 0x49: Serial.print(F("ADS1115,TSL2561,PCF8591")); break;
    case 0x4A: Serial.print(F("ADS1115,Qwiic Keypad")); break;
    case 0x4B: Serial.print(F("ADS1115,TMP102,BNO080,Qwiic Keypad")); break;
    case 0x50: Serial.print(F("EEPROM,FRAM")); break;
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

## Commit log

2021-09-26 Initial commit with Core64c Logic Board V0.2 and some sample test code
    [Core64C LB v0.1 Driver.sch, Core64C LB v0.1 Expansion.sch, Core64C LB v0.1 Power.sch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]
2022-05-18 HWV 0.3.0: Create and release Core64c Logic Board V0.3.0
    Correct shift register schematic, add TC0_MON as ADC3, move 5V0 cap down, alternate LDO v-regs with 0.1uF caps, rotate SPI GPIO 180°, matrix current setting resistors 6.8 Ohm, I2C pull-ups 1.2K, add battery pack wire pads directly to board, silkscreen tweaks, move LED Matrix Driver components away from lanyard hole.
    [Core64C LB V0.3 Driver.sch, Core64C LB V0.3 Expansion.sch, Core64C LB V0.3 Power.sch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]
2022-05-20 HWV 0.3.0: Core64c Logic Board, add and rename data sheets, update BOM notes for JLCPCB component availability
    [Core64c LB v0.3 2021-05-17 BOM.xlsx]
2022-06-13 Correct Core64c LB v0.3 filename date from 2021 to 2022
    [Core64c LB v0.3 2022-05-17 BOM.xlsx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]
2022-06-13 Create Core64c Logic Board v0.4 from v0.3.
    SCHEMATIC
    Remove 2x 10Ks between Comparators and NOR gate like Core64 V0.6 LB.
    Update Comparator output pull-ups to be 1K2 like Core64 V0.6 LB (and i2C pull-ups).
    Organize the Ref Des #s nicely, like Core64. D1-D12, Q1-Q20 in core matrix driver.
    COMPONENTS
    Find alternatives to get from LCSC, Matrix Drive FET
    SILKSCREEN
    Add JLCJLCJLC above the PCB P/N list to ensure they put it there.
    Correct jumpers #s near OLED socket to match +/- pin names.
    Remove * in the middle of the Pico footprint. Replace with Raspberry Pi Pico name. Set invisible.
    Add +/- to back side near the optional battery wire pads/hole.
    Add "All Logic Levels 3.3V."
    [Core64C LB V0.4 Power.sch, Core64C LB v0.4 Driver.sch, Core64C LB v0.4 Expansion.sch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]
2024-10-10 Clean-up LB V0.4 design files
    [Core64C LB V0.4 Power.sch, Core64C LB v0.4 Driver.sch, Core64C LB v0.4 Expansion.sch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]
2024-10-10 Clean-up LB V0.5 files
    [Core64c LB v0.5 2024-03-24 BOM.xlsx, Core64c LB.kicad_pcb, Core64c LB.kicad_sch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]
2024-10-10 Add LB V0.6-V0.7 files
    [Core64c LB v0.6 2024-07-07 BOM.xlsx, Core64c LB-top.csv, Core64c LB.kicad_pcb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]

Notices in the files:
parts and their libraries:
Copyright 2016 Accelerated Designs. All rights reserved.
